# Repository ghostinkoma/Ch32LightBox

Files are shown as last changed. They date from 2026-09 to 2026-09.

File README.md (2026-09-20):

# LightBox — CH32V003 LED Dimmer Controller

**English** · [日本語](README_JP.md)

> **Status: ✅ Hardware Verified & Operational (as of 2026-09, no issues)** — All functions confirmed on both custom PCB (KiCad) and universal breadboard/perfboard. Verified nightlight, brightness control, soft start/off, 12-hour endurance test, and virtually zero heat generation with a ~1A LED.
> **Enclosed and currently in actual use inside a 3D-printed case designed in Fusion 360.**
>
> **License: Non-Commercial (CC BY-NC 4.0 compliant / Attribution required, modification allowed for non-commercial use, provided AS-IS without warranty)** → [LICENSE](LICENSE)

A single-channel PWM LED dimmer controlled via a rotary encoder.
Powered by the **CH32V003** microcontroller with a self-contained firmware based on [ch32fun](https://github.com/cnlohr/ch32fun).

To prioritize reproducing brightness as **perceived by the human eye**, the PWM duty cycle is generated using the **CIE 1931 L\* (lightness) curve**. One click produces a "perceptually equal" shift in brightness—slower changes at low levels and sharper changes at high levels—achieving a balanced response for human vision.

## Key Features

| Feature | Description |
|---|---|
| **CIE L\* Dimming** | Perceptually uniform brightness. 64 total steps, LUT generated at startup, runtime lookup via integer table. |
| **16-bit PWM** | TIM2, default 4095 steps / ~12 kHz. Adjustable resolution and frequency in `config.h`. |
| **Debouncing** | Full-step state machine (Ben Buxton) + direction reversal lockout (default 5 ms). No simple delays used. |
| **Fast-turn Snap** | Immediately sets duty to 100% or 0% if turned in the same direction $j$ times within $n$ ms. |
| **CW/CCW Support** | Swap rotation direction with a single line in `config.h`. |
| **Brightness Memory** | Flash wear leveling (dedicated 2 KB area, saved after 5 sec, ~1024x lifespan extension, saves ON/OFF state). |
| **Overheat Failsafe** (Default OFF) | Forcefully shuts off main PWM (MOSFET) when overheated → resumes when cooled down. Thermal throttles to $j$\% after $n$ cycles. **Die estimation disabled due to false triggers (`TEMP_PROTECT_ENABLE 0`)**; enable only when using an external NTC sensor. |
| **Watchdog** | IWDG. Automatically resets on system freeze for self-recovery. |
| **EMI Mitigation** | Configurable PWM slew rate (GPIO speed) + spread spectrum (period dithering, brightness invariant). |
| **Nightlight (WS2812 or single LED)** | When completely dark: ①WS2812/SK6812 breathes light↔dark on the CIE curve (RGB/RGBW, color order, max color), or ②a single-color LED blinks `x` ms every `n` s. |
| **Deep Low-Power (experimental)** | Optional battery mode (`LOW_POWER_MODE`): single-LED nightlight with the MCU in Standby between blinks (AWU periodic wake, push-switch EXTI wake). Default off; see CONFIG_REFERENCE. |
| **Soft Start** | Smoothly fades in/out to target brightness on power ON/OFF based on CIE curve (duration set in config, disabled if 0, max 65535 ms). |
| **Push Switch** | Short press toggles ON/OFF (time-based debouncing; smoothly tracks re-triggering during active fades). |

All configuration options are centralized in **`source/config.h`** (see [CONFIG_REFERENCE.md](documents/CONFIG_REFERENCE.md) for details).
Detailed specifications are in [SPEC.md](documents/SPEC.md), design decisions are in [DESIGN.md](documents/DESIGN.md), and battery / low-power and LED-driver notes are in [POWER_AND_DRIVER.md](documents/POWER_AND_DRIVER.md).

## Pinout (**All features fit on SOP8 / J4M6**)

| Pin | Signal | Function |
|---|---|---|
| PA1 | ENC_A | Encoder Phase A (Internal pull-up, Common=GND) |
| PC1 | ENC_B | Encoder Phase B (Internal pull-up, Common=GND) |
| PA2 | ENC_SW | Push Switch (Internal pull-up, Active Low) |
| PC2 | PWM | **Main LED Output** (default `PWM_PIN`=PC2 → TIM2_CH2 remap1) |
| PC4 | (Selectable) | **WS2812 Nightlight** / External Temp Sensor / Warning LED (Mutually exclusive, choose one) |
| PD1 | SWIO | Programming / debugprintf (Reserved) |

> **Feature ↔ pin assignment is done entirely in `config.h`** (one pin macro per feature: `PWM_PIN`, `ENC_*_PIN`, `WS_DIN_PIN`, `TEMP_SENSE_PIN`, `WARN_LED_PIN`). `source/pins.h` validates capabilities (PWM-/ADC-capable pins) and pin conflicts at compile time, and the LightBox Studio config editor mirrors the same checks. See the “Feature ↔ Pin Assignment” section of [CONFIG_REFERENCE.md](documents/CONFIG_REFERENCE.md).

> **Temperature protection is OFF by default** (die estimation rejected due to false shutdowns). Watchdog and EMI mitigations **require no external pins**, allowing PC4—the only remaining free pin on SOP8—to be used for the nightlight.
> If an external physical temperature sensor or warning LED is needed, allocate PC4 accordingly (mutually exclusive with the nightlight). To use more features simultaneously, switch to TSSOP20/QFN (F4P6) and assign individual pins in `config.h`.

## Connecting the LED

- **Recommended**: PC2 → MOSFET gate (e.g., AO3400 / 2N7002), driving the LED on the low side via the drain.
- **Simplified**: Low-current LEDs can be connected directly via `PC2 → [Resistor] → LED → GND` (Strictly respect $I_{\max} \approx 8\text{ mA}$ per pin).
- **Overheat Protection (Default OFF)**: The CH32V003 lacks an internal die temperature sensor. The initial duty-based "die temperature estimation" caused **false shutdowns (sudden turn-offs during continuous use)** because it was not a physical measurement. It has been **rejected (`TEMP_PROTECT_ENABLE 0`)**. If physical thermal protection is strictly required, attach a thermal-coupled NTC on the MOSFET to an ADC pin and run with `TEMP_PROTECT_ENABLE=1` + `TEMP_SOURCE=EXTERNAL`. See SPEC.md for details.

## Operation

- **Rotate Encoder**: $\pm 1$ step per click (perceptually equal spacing using CIE L*).
- **Fast Turn** (Default: 6+ clicks within 0.5s): Snaps to full brightness (100%) in the bright direction, or turns off (0%) in the dark direction.
- **Push Switch Short Press**: Toggles ON/OFF (retains last brightness level).
- **Auto Memory**: Defaults to 0 on first boot. Setting a brightness and leaving it untouched for 5 seconds automatically saves it to flash for next startup restoration.
- **Soft Start**: Fades in/out smoothly to target brightness on power ON/OFF or boot up (fade duration configured in config).
- **Nightlight**: Breathes automatically when turned completely dark (turns off when main LED turns on/brightens).

## Build & Flash

### ① ch32fun + Makefile (Verified Standard Build)

Dependencies: [ch32fun](https://github.com/cnlohr/ch32fun), RISC-V GCC (xpack riscv-none-elf recommended for `rv32ec libgcc`), WCH-LinkE.

```bash
cd source
make lightbox.bin CH32FUN=/path/to/ch32fun/ch32fun    # Build only
make             CH32FUN=/path/to/ch32fun/ch32fun    # Build -> Flash
```

Build memory footprints (Default config, all features ON, `DEBUG_LOG=0`): **Flash 8200 B / 16 KB (50%), RAM 184 B (9%)**.
Stripped footprint: Core only ~3 KB, + Nightlight ~3.6 KB. `DEBUG_LOG=1` adds ~1 KB.

> Set `DEBUG_LOG` to 1 only during development. `printf` is blocking and can stall if an SWD host is disconnected, causing dropped inputs in hot loops. Defaults to 0, which unlinks the printf infrastructure entirely.

### ② PlatformIO

See [PLATFORMIO.md](PLATFORMIO.md) (`platformio.ini` included).
*Note: The PlatformIO build has not been verified in this environment. The verified build method is the Makefile above.*

### ③ LightBox Studio (GUI — no VS Code required)

For a GUI-only workflow (`config.h` editing → compile → flash from a single menu), use the Java toolset in [tools/LightBoxStudio/](tools/LightBoxStudio/README.md). It downloads a self-contained toolchain on first run, so no command line or VS Code is required. See the [LightBox Studio README](tools/LightBoxStudio/README.md) for details.

## Directory Structure

```
LightBox/
├─ source/         Firmware source files
│  ├─ lightbox.c      Main application (main / encoder / PWM)
│  ├─ config.h        Centralized configuration (edit parameters here)
│  ├─ cie.h           CIE L* curve library (shared by main PWM & nightlight)
│  ├─ store.h         Non-volatile brightness storage (wear leveling)
│  ├─ temp.h          Temperature reading (external NTC, default OFF)
│  ├─ wdt.h           Watchdog timer (IWDG)
│  ├─ nightlight.h    WS2812/SK6812 nightlight driver
│  ├─ funconfig.h     ch32fun environment configuration
│  └─ Makefile
├─ documents/      SPEC.md / CONFIG_REFERENCE.md / HARDWARE.md / DESIGN.md / POWER_AND_DRIVER.md (+ *_JP.md)
├─ tools/          LightBoxStudio/ = GUI toolset (config edit → build → flash, no VS Code)
├─ ldscript/       Linker script for PlatformIO (lightbox_ch32v003.ld)
├─ PCB/            KiCad board files (LightBox/ = Schematic/PCB; AertWork.png; KiCad/ = FDS5680 lib)
├─ platformio.ini / PLATFORMIO.md
├─ 3D_Models/      Enclosure (Fusion 360 design / STL files, 3D printed)
└─ LICENSE         Non-commercial license (CC BY-NC 4.0 compliant)
```

## Enclosure

**Designed in Fusion 360 → 3D printed**. The board is assembled inside and **currently in operational use** (STL files available in `3D_Models/`).

## Hardware (PCB)

PCB layout, schematic, and artwork (with pin headers) completed → `PCB/LightBox/` (KiCad).
**Pin routing matches firmware exactly.** Details, BOM, and J1 pinout are in [HARDWARE.md](documents/HARDWARE.md).

- U1 CH32V003 (SOP8) / Q1 FDS5680 (N-MOSFET, low-side drive for main LED) / D1 SK6812 (OST45050C1A-W nightlight)
- R1 $100\ \Omega$ (Gate series resistor) / R2 $10\text{ k}\Omega$ (Gate pull-down = LED OFF during reset) / **D2 Pilot LED + R3 $100\ \Omega$ (series)**
- **Main (Power) LED is off-board** (Connected via LED OUT → J1). **Near-zero heat generation with ~1A LED** (heatsink added only as a precaution).
- J1 9-pin header: Breaks out Power / SWIO / Encoder / Signals for both LEDs. **Powered by $\text{VDD} = 5\text{ V}$**.
- Equivalent circuit constructed on a 1.27 mm pitch universal perfboard and verified working.

## Verification Status — ✅ Hardware Verified (Running Continuously)

- **★ Physical Board Operation Confirmed (2026-09-16 ~ present, running without issues)**: Board schematic/routing verified, flashing successful.
  - **Nightlight** (SK6812 / OST45050C1A-W, RGBW sequence)
  - **Brightness adjustment** (CIE L*, acceleration x3, fast-turn snap)
  - **ON/OFF soft start & soft off**
  - **12-hour ON / 12-hour OFF endurance test passed** (Disabling thermal protection eliminated false cutoffs, ensuring long-term stability)
- Build checks: Zero compiler warnings across all feature ON/OFF, RGBW, and half-step combinations (Makefile, ch32fun).
- Host simulation tests: CIE LUT, encoder state machine, flash wear store boundaries, nightlight curves, color ordering, acceleration, thermal model.
- Unverified: Long-term Flash wear (~10 million cycles by design), external NTC thermal protection (disabled by default), PlatformIO build environment.

## License

This project (original parts of firmware, PCB, enclosure, and documentation created by ghostinkoma) is licensed under a **Non-Commercial License (Creative Commons Attribution-NonCommercial 4.0 International / CC BY-NC 4.0 compliant)**. See [LICENSE](LICENSE) for full details.

- **Non-Commercial Use Only** (Contact the author for commercial licensing).
- **Attribution Required** (Must credit the original author **ghostinkoma** and "LightBox").
- **Modifications Allowed** (Free to adapt for non-commercial purposes; derivative works must inherit the same license conditions).
- **No Warranty / No Liability** (Provided "AS IS". The author accepts no responsibility for damages resulting from use).

*Note: Bundled/dependent third-party code (e.g., [ch32fun](https://github.com/cnlohr/ch32fun)) remains under its respective original licenses (MIT-x11 / NewBSD).*

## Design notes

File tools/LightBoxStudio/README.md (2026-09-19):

# LightBox Studio — CH32V003 One-Stop GUI (No VS Code Required)

**English** · [日本語](README_JP.md) · [← Project README](../../README.md)

A Java toolset for executing the workflow of `config.h` editing → compilation → flashing **from a single menu GUI**.
Its goal is to enable complete development of LightBox ([../../README.md](../../README.md)) using only a GUI, without requiring VS Code.

> **Status: ✅ Verified on real hardware (2026-09-18)**. On first-time setup, it automatically downloads the toolchain, deploys it to `toolchain/`, and fills in configuration settings automatically (self-contained, sandbox without scanning the PC).
> **config.h editing → compilation → CH32V003 flashing** was successfully executed on actual hardware using **only minichlink bundled in the downloaded ch32fun (inside dist, self-contained)** (`Detected CH32V003 → Image written`).
> Users do not need to search for installed paths. Detailed troubleshooting logs are recorded in [BUGFIX.md](BUGFIX.md).

## Architecture (5-Component Set)

| Executable | Role | Type |
|---|---|---|
| `LightBoxMenu.jar` | **Menu (Kicker)**. Launches other tools and aggregates logs | GUI |
| `setup.jar` | **Initial Setup**. Downloads/extracts toolchain and auto-fills settings (with progress bar) | GUI |
| `config-editor.jar` | Form-edits `config.h`, validates, and saves | GUI |
| `builder.jar` | Executes `make` to build (and optionally flash) | Background |
| `flasher.jar` | Flashes to CH32V003 using `minichlink` | Background |

The menu GUI and each background functional JAR operate as loosely coupled **separate processes**. Settings are shared via `settings.properties` (located in the same folder as the JARs).

## Requirements

- **JDK / JRE 11 or higher** (JDK for building, JRE sufficient for execution).
- Native toolchains (ch32fun / RISC-V GCC / make / minichlink) are **automatically prepared by [⬇ Initial Setup]**, so pre-installation is not required.
- Only for flashing, the **WinUSB driver for WCH-LinkE** (Zadig on first-time setup only) is required.
  * This is the only manual step that cannot be automated via Java (for distribution on other PCs).
  Instructions are built into the menu under **[🔌 Driver (Zadig)]** (refer to [ZADIG.md](ZADIG.md)).

> If you only edit `config.h`, **setup is not required** (operates in pure Java).

## Initial Setup (Self-Contained)

Pressing **[⬇ Initial Setup]** (`setup.jar`) in the menu **downloads & extracts** the following into `toolchain/` and automatically populates `settings.properties`. Progress is displayed via a progress bar.

| Component | Source | Approx. Size |
|---|---|---|
| RISC-V GCC (xpack riscv-none-elf) | xpack-dev-tools Releases | **~360MB** (takes time) |
| make (xpack windows-build-tools) | xpack-dev-tools Releases | ~2.7MB |
| ch32fun SDK | cnlohr/ch32fun (master zip) | A few MBs |
| minichlink | Automatically detects & copies existing binaries on PC due to lack of official prebuilts (internal process, no user action needed) | — |

- Download sources/versions can be replaced via `dist/toolchain.manifest.properties` (optional).
- Since `toolchain/` is large, it is ignored via `.gitignore` (not included in the repository).
- If minichlink is not found on the PC, the step is skipped; building and editing remain functional, but **flashing requires manually specifying minichlink**.

## Build

```bash
# Windows
build.bat
# Linux/macOS
./build.sh
```
Five JAR files will be generated in `dist/` (pre-generated JARs are also bundled in this repository).

## Usage

1. Launch the menu:
   - **Recommended: Double-click `LightBoxStudio.bat` (Windows) / `LightBoxStudio.sh` (Linux/macOS)**.
     The launcher automatically detects Java (① Bundled portable JRE → ② `JAVA_HOME` → ③ PATH) and starts.
   - Direct execution is also possible: `java -jar dist/LightBoxMenu.jar`
2. First-time only: Press **[⬇ Initial Setup]** to acquire the toolchain (wait until the progress bar completes).
   * If only editing config.h, this step is not needed. If a toolchain already exists, you can manually specify it in **[⚙ Settings]**.
3. **① Edit config.h** → **② Compile** → **③ Flash** (or **②+③ Build & Flash**).

### Java Runtime (When System Installation is Undesirable)

- The launcher **prioritizes detecting and reusing existing Java** (`JAVA_HOME`/PATH). If Java is already present, nothing extra is needed.
- If you **do not wish to install Java onto the system**, select **"☐ Also acquire portable JRE"** during initial setup. This extracts Adoptium Temurin 17 JRE (~44MB, no installer required) **only into `dist/runtime/`**.
- **System PATH, registry, and admin privileges remain untouched** — deleting the folder returns the system to its original state (**sandbox**). Subsequent launcher runs will automatically use this `runtime/`.
- Distributing to a PC without Java: **Run "Also acquire portable JRE" on a PC with Java → Copy the folder whole**. The target PC can run the launcher without installing Java (including `dist/toolchain/` allows self-contained building and flashing as well).

## Settings (settings.properties)

| Key | Meaning |
|---|---|
| `project.dir` | The `source/` folder containing `config.h` / `Makefile` (empty = auto-detect) |
| `ch32fun.dir` | The folder containing `ch32fun.mk` |
| `make.path` | `make` executable path (empty = PATH) |
| `gcc.bin.dir` | `bin` directory containing `riscv-none-elf-gcc` (empty = PATH) |
| `minichlink.path` | `minichlink` executable path (empty = PATH) |
| `flash.artifact` | Target file to flash (default `lightbox.bin`, relative paths based on `project.dir`) |

## Features of config.h Editor

- **Schema-Driven**: Form-edit all 64 settings with type-specific widgets (numeric / checkbox / dropdown / pin / color).
  Definitions correspond to [`documents/CONFIG_REFERENCE.md`](../../documents/CONFIG_REFERENCE.md) and `source/config.h`.
- **Feature ↔ Pin Assignment**: Per-feature pin dropdowns are filtered by hardware capability — `PWM_PIN` lists only PWM-capable pins, `TEMP_SENSE_PIN` only ADC-capable pins. Pin conflicts (two features on one pin), capability violations, and SWIO(PD1) use are flagged before save, mirroring the firmware `source/pins.h` compile-time checks.
- **Nightlight type & deep low-power**: choose ①WS2812 or ②single-color LED; validation enforces that deep low-power (`LOW_POWER_MODE`) is used only with single-LED + no-PWM + `NL_PERIOD_S≤30` + `WDT_ENABLE=0`. A **live CR2032 battery-life estimate** (1 kΩ assumption) is shown for the single-LED nightlight to guide config.
- **Non-Destructive Editing**: Replaces **only value tokens** in `#define KEY VALUE`, preserving comments, enum definitions, empty lines, `u`/`L` suffixes, and `(-300)` formatting (without regenerating full text). Creates `config.h.bak` before saving.
- **Cross-Constraint Validation** (Pre-save validation):
  - When `PWM_SPREAD_SPECTRUM=1`: `PWM_TOP+PWM_SPREAD_RANGE≤65535` and `RANGE<PWM_TOP`
  - `STORE_SIZE_BYTES` must be a multiple of 1KB / `LEVEL_INIT≤LEVELS`
  - `WARN_TEMP_HYST_C<WARN_TEMP_C` / `THERMAL_THROTTLE_MAX<100` / `TEMP_CAL_SLOPE_X100≠0`
  - **PC4 Mutual Exclusion** (Nightlight / External temp sensor / Warning LED cannot share PC4 simultaneously)
  - Links digit counts of `WS_MAX_COLOR` with `WS_ORDER` (RGB = 6 digits / RGBW = 8 digits)
  - Warnings: `DEBUG_LOG=1` (must be 0 for normal operation), Die estimation temperature source (risk of false cutoffs)
- **Advanced Mode**: Fixed hardware wiring items like `ENC_*_PIN` are locked by default to prevent accidental modifications.

## Flashing Notes (Compliant with README / CONFIG_REFERENCE.md)

- SWD printf monitoring (`minichlink -T`) is **mutually exclusive with flashing**. Close monitoring before flashing.
- If no flash artifact exists, run **② Compile** first to generate `lightbox.bin`.
- WCH-LinkE not recognized → Verify WinUSB driver (Zadig), power supply, and SWIO (PD1) wiring.
- **If flashing hangs**: Use **[■ Abort]** in the menu to stop execution (kills child minichlink processes as well).
- **minichlink compatibility varies by build**: When multiple versions exist on a PC, some builds initialize successfully but hang during flashing. As a countermeasure, flashing **tries multiple minichlink candidates sequentially**, with each attempt **timing out after ~25 seconds** before falling back automatically (ensuring execution using a working binary even if a hanging binary is selected initially). Initial setup automatically records candidates in `minichlink.candidates`.
- **For guaranteed reliability**: Specify a proven `minichlink.exe` via **[🔧 Select Flashing Tool]** in the menu (runs with highest priority). This setting persists across setup re-runs.
- **Once successfully flashed, minichlink is recorded in user profile (`~/.lightboxstudio/`)**, and will be **automatically prioritized on subsequent runs** even if the `tools/` folder is deleted and cleanly reinstalled.
  * "Once a working minichlink is configured, it works automatically from then on."
- Candidate evaluation order: ① Local settings → ② Historical successful runs → ③ Auto-detected candidates. If a record exists, unnecessary waiting is avoided.
- Re-running setup skips downloading large files if `toolchain/` is already extracted.

### minichlink Compatibility and Self-Containment (Investigation Results)

- **Source builds are not required**. ch32fun bundles Windows `minichlink.exe` and `libusb-1.0.dll` in its repository (prebuilts built with tcc committed). Extracting ch32fun during initial setup yields `toolchain/ch32fun-master/minichlink/minichlink.exe`.
  → **Flashing automatically tests this minichlink as a self-contained candidate** (no PC-wide search required).
- **However, compatibility exists between minichlink builds and WCH-LinkE drivers/firmware** (Verified on hardware):
  - `Could not initialize` … WinUSB driver not assigned. Assign WCH-Link to WinUSB via **Zadig** (one-time setup).
  - Hangs after `Found WCH Link` … Compatibility issue between minichlink build and LinkE firmware (e.g., firmware 2.17 succeeds with older `bc15212` series but hangs with newer series). **Once a working version is used, it is remembered automatically**.
- Fallback sequence (**No full PC scanning = Sandbox**): ① Local settings → ② Historical successes (`~/.lightboxstudio/`) → ③ **Bundled with ch32fun (inside dist, self-contained)**. Each times out after 25s.
  **Successful versions are recorded permanently** (retained across clean reinstalls).
- If the bundled version fails in your environment: Explicitly specify a working `minichlink.exe` via [🔧 Select Flashing Tool] (default path points to the bundled location in ch32fun). Explicitly set paths gain highest priority and permanent memory.
- If flashing still fails, update WCH-LinkE firmware (using WCH-LinkUtility) to match driver versions.

> Key takeaway: Simply point to or assign a working minichlink **once**, and the process becomes fully automatic afterward. Even for CH32 beginners, the target is to complete flashing using ch32fun-bundled minichlink + Zadig (one-time initial driver setup).

## Roadmap

- **Phase 0 (Completed)**: GUI implementation assuming pre-existing environment. `config-editor` completed as a standalone tool.
- **Phase 1 (Completed / Current)**: `setup.jar` automatically downloads xpack GCC / make / ch32fun into `toolchain/`, auto-detects/copies existing minichlink, and populates configuration settings (self-contained, with progress bar).
- **Phase 2 (In Progress)**: **Portable JRE (sandbox) + Launcher** for complete self-contained Java dependency management.
  Existing Java installations are auto-detected and reused; if missing/unwanted, extracted solely to `dist/runtime/` (no system modifications).
  Remaining: Single `.exe` creation via `jpackage`, integrated WinUSB driver installation (Zadig) guide.

## License

This toolset follows the same non-commercial license (CC BY-NC 4.0 compliant) as LightBox itself ([../../LICENSE](../../LICENSE)).

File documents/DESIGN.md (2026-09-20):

# LightBox Design Notes

**English** · [日本語](DESIGN_JP.md) · [← README](../README.md)

CH32V003 LED Dimmer. Documenting design decisions and rationale to ensure third-party reproducibility.
Battery / low-power and LED-driver decisions are recorded separately in [POWER_AND_DRIVER.md](POWER_AND_DRIVER.md).

## Requirements
- Input: Locally connected rotary encoder
- Output: Single PWM (1ch LED)
- MCU: CH32V003
- Uses a 16-bit timer
- **Perceptual Brightness Priority**: Recreates human visual perception as top priority → adopts CIE 1931 L*
- Snap shortcut: Sets duty to 100% or 0% immediately if clicked $j+$ times in the same direction within $n\text{ ms}$ ($n, j$ configured via config)
- Encoder Direction: Supports both CW/CCW encoder types (configurable)
- Non-Volatile Brightness Memory: Stores brightness level upon power cycle with wear-leveling (initial 0, saves after 5 seconds)
- Over-temperature Fail-Safe: Thermal protection light (fail-safe with configurable thresholds)
- WS2812/SK6812 Night Light: "Breathing" illumination based on CIE standard when dark (configurable color, byte order, period)
- All settings consolidated in **config.h**

## Pin Assignment Rationale
Designed for the smallest package, **SOP8 (J4M6)**. Available GPIO pins are 5 in total: PA1, PA2, PC1, PC2, PC4 (excluding VDD/VSS, and preserving PD1 for SWIO debugging/flashing).

- PWM Output: **TIM2_CH2 (remap1) = PC2**. Tested and proven in the sister project FanConCH32V003, presenting the lowest risk.
- Encoder Inputs: A=PA1, B=PC1, SW=PA2 assigned from remaining pins, all configured as internal pull-ups.
- Reserve Pin: PC4 reserved (for a future 2nd channel or status LED).

Since larger packages maintain pin compatibility with this layout, SOP8 serves as the baseline design.

## Encoder Decoding and Debouncing
Mechanical rotary encoders inherently suffer from contact bounce. **Simple delay-based debouncing was rejected** as it blocks the main execution loop, worsening dropped events and failing to suppress bounce occurring during the delay itself. Instead, a **State Machine + Time Lockout** architecture is implemented.

### Evaluated Debounce Strategies
| # | Strategy | Effect | Adoption |
|---|---|---|---|
| 1 | Reject invalid transitions (2-bit simultaneous change) | Suppresses glitch noise | Embedded in State Machine |
| 2 | **Full-Step State Machine (Ben Buxton Method)** | Triggers 1 step only upon completing a valid path between detents. Intermediate bounce bounces back/forth without firing, ignoring single-phase chatter. | **Adopted (Core)** |
| 3 | **Direction Reversal Lockout (Default 5ms)** | Ignores reverse steps occurring within an extremely short time window as physical impossibilities (bounce). Same-direction steps are unrestricted. | **Adopted** |
| 4 | Fixed Period Sampling (e.g., 1ms) | Hides fast bounce between samples | Rejected: Coarse sampling drops fast turns. #2 + #3 suffice without loss. |
| 5 | Majority Voting / Integration per Phase | Phase-independent debouncing | Rejected: Redundant with #2. |
| 6 | Inter-step Refractory Period | General step throttling | Reduced into #3 (reversal only). Global throttling hampers fast spins. |
| 7 | Simple `delay()` | - | **Rejected** (Degrades responsiveness, drops steps, fails to resolve bounce). |
| 8 | Pushbutton Time-Based Integration Debounce | Replaces loop-count-dependent counters | **Adopted** |

### (2) Full-Step State Machine
Column index = Current 2-phase state `(A<<1)|B` (idle = `0b11`). States start at START and must traverse BEGIN $\rightarrow$ NEXT $\rightarrow$ FINAL in the **correct order** for either CW or CCW to emit `DIR_CW` or `DIR_CCW`. Phase bounce simply oscillates between BEGIN $\leftrightarrow$ START without triggering invalid steps. Half-step lookup tables are also available via `ENC_HALF_STEP` (unused tables excluded via `#if`).
- Host Verification: Clean CW×3 $\rightarrow$ [1,1,1] / CCW×3 $\rightarrow$ [-1,-1,-1]. Single detent with injected bounce $\rightarrow$ [1]. Immediate reverse chatter following CW $\rightarrow$ [1] (zero false reversals).

### (3) Direction Reversal Lockout
Implements a strict threshold where opposite directional steps within 5ms are discarded. Even if state transitions near mechanical thresholds produce a reverse step, if it occurs in the opposite direction of the last **confirmed** step within `ENC_REVERSAL_LOCK_MS` (default 5ms), it is dropped as contact bounce. Manual reverse turning takes tens of ms; thus, reversals under 5ms are guaranteed chatter. **Same-direction steps are unrestricted**, maintaining responsiveness for rapid spins. Timing uses SysTick (unsigned subtraction, overflow-safe).

### (8) Pushbutton Debounce
When raw state changes, candidate value and timestamp update. Once the value remains stable for `SW_DEBOUNCE_MS` (default 20ms), state updates. Validated press (falling edge) toggles state. Replaces inaccurate loop-counter methods.

Polling Choice: Manual encoder rotation achieves at most a few ms per quarter-step. Polling in the main loop captures all events without missing, avoids interrupt complexity, and preserves SOP8 EXTI resources.

## Dimming Curve — CIE 1931 L* (Perceptual Brightness Priority)
The primary design goal is **matching human brightness perception**. Human visual perception follows a **power law (~cubic root, Stevens's Law)** rather than a pure logarithmic response, featuring high sensitivity at low light levels and lower sensitivity at high light levels. **CIE 1931 L\*** is used as the standardized perceptually uniform scale. Logarithmic/exponential tapers approximate this curve but suffer from accuracy loss at lower brightness levels.

Level index $i$ is mapped linearly to lightness $L^*$ (0..100) (meaning 1 click = equal perceived step change), and mapped back to relative luminance $Y$ and duty cycle:

$$\text{For } L^* \le 8: Y = \frac{L^*}{903.3} \quad (\text{linear toe near complete darkness})$$

$$\text{For } L^* > 8: Y = \left(\frac{L^* + 16}{116}\right)^3 \quad (\text{power law})$$

$$\text{Duty} = \text{PWM\_TOP} \times Y$$

- **Integer-Only Math**: CH32V003 lacks an FPU. $L^*$ is represented in units of $1/100$, and the cubic term is calculated during initialization using 64-bit unsigned integers (`uint64_t`): $\text{PWM\_TOP} \times (L^* + 16)_{x100}^3 / (11600)^3$. Maximum value $65535 \times 11600^3 < 2^{63}$, preventing overflow without `libm` or `float` dependencies.
- Linear Toe ($L^* \le 8$): Handles low-light conditions, avoiding the extreme dim-crushing associated with pure logarithmic functions.
- Lookup Table (LUT): Computed once at boot. Main execution relies purely on `uint16_t` array indexing. Host verified: 0 $\rightarrow$ PWM_TOP boundaries, strictly monotonic, no duplicate steps, uniform low-end resolution (`duty = 0, 7, 14, 21, 28, ...`).
- The curve is **fixed and parameterless** (as CIE $L^*$ defines standardized human vision). Gamut adjusters can be added upstream if custom scaling is needed in the future.

## PWM Resolution and Frequency (16-bit Timer)
- TIM2 is a **16-bit counter**. `PWM_TOP` supports values up to 65535 and is configurable via `config.h`.
- Default: `PWM_TOP = 4095` (12-bit resolution), `PSC = 0` $\rightarrow 48\text{MHz} / 4096 \approx \mathbf{11.7\text{kHz}}$. Operates outside audible range without visible flicker. Preserves fine step resolution at low duty cycles (e.g., duty = a few counts), whereas 8-bit resolution (256 steps) leads to rounding collisions at the low end. Resolution can be increased to 8191 or 16383 for smoother dimming.

## High-Speed Rotation Snap (Duty 100% / 0% Shortcut)
Rapidly setting maximum or minimum brightness is achieved through fast rotation gestures.

- Circular buffer tracks timestamps of recent `SNAP_CLICKS` clicks in the same direction.
- On a new click, if elapsed time `now - oldest` across $j$ clicks is within `SNAP_WINDOW_MS` ($n\text{ ms}$), shortcut triggers: sets `level = LEVELS` (100%) for clockwise/brightening, or `level = 0` (0%) for counter-clockwise/dimming.
- Driven by SysTick (`SysTick->CNT` / `Ticks_from_Ms`). Unsigned subtraction avoids wrap-around issues ($0.5\text{s window} \ll 32\text{-bit wrap period} \approx 715\text{s}$).
- Clears click history post-trigger to prevent repeated snapping. Configurable via `SNAP_WINDOW_MS` and `SNAP_CLICKS`.

## Dual CW/CCW Encoder Support
Variations in encoder hardware or wiring order can invert rotation direction. Invert signal decoding digitally via `ENC_REVERSE` (0 or 1 in `config.h`) without modifying hardware wiring (flips decoded `dir` sign, applying consistently across dimming and snap gestures).

## LED Drive Circuitry
- Recommended: **Low-side MOSFET switch** (e.g., 2N7002, AO3400). Avoids MCU GPIO drive limits ($I_{max} \approx 8\text{mA}$), enabling drive of high-power LEDs, series strings, or constant-current drivers.
- Small signal LEDs may connect directly to PC2 via current-limiting resistor within rating boundaries.

## Soft Power Toggle and Operating Options
Short press on encoder switch toggles output state (ON/OFF). Preserves active dimming level during OFF state, restoring prior brightness upon turning back ON.

- **`WAKE_ON_TURN` (Default: 1)**: Turning encoder while OFF automatically restores output. Prevents hidden level adjustments while output remains dark.
- **`DEBUG_LOG` (Default: 0)**: Restricts UART/SWD `printf` to development mode.

## Hot-Loop I/O Optimization (`DEBUG_LOG`)
Enabling `printf` calls within event loops introduces blocking behavior: (a) If SWD host is disconnected, buffer saturation halts CPU execution; (b) Each call incurs hundreds of microseconds to milliseconds, missing intermediate encoder transitions and dropping detents. Setting `DEBUG_LOG = 0` compiles out logging mechanics entirely, running polling loops at maximum rate. Reduces flash consumption from 4380 B to 2968 B.

## Non-Volatile Brightness Storage (Wear-Leveling)
Restores last selected brightness level across power cycles. To accommodate flash write/erase limits, the driver appends updates sequentially to erased space rather than overwriting fixed addresses, performing sector erasures only when full.

### Flash Physics (CH32V003 Standard Mode)
- Bit transitions are limited to **$1 \rightarrow 0$**. Resetting $0 \rightarrow 1$ requires sector erase.
- **Erase Block = 1KB** (`PER`). **Write Unit = 2 Bytes** (`PG`, half-word).
- Erased State = `0xFFFF`.

### Appending Single-Cell Log (Last-Written-Wins)
- Reserves the final `STORE_SIZE_BYTES` (2KB) as a dedicated **1KB-aligned `const` array** (initialized to `0xFFFF`). Being 1KB-aligned and a multiple of 1KB, this memory occupies dedicated sectors without interfering with code or constants (verified: `g_store @ 0x1400`, occupying sectors 5–6 while application code remains separated below `0x1400`).
- **Save Operation**: Appends 2-byte entry to the first available `0xFFFF` cell. **1 save = 1 write**.
- **Read Operation**: Reads cell immediately preceding first empty (`0xFFFF`) slot. Defaults to 0 on uninitialized storage.
- **Full Storage**: Erases reserved 2KB sectors and wraps execution to start.
- Levels (0..64) do not collide with `0xFFFF`, allowing raw values to reside in single cells.
- Flash controller operations translate array references into physical memory offsets based on $0x08000000$.

### Commit Delay Optimization
Defers flash writes until level remains unchanged for `STORE_COMMIT_MS` (5 seconds), grouping adjustments into a single flash commit.

### Flash Lifespan Estimation
- $2\text{KB} / 2\text{ Bytes} = \mathbf{1024\text{ records}}$. Sector erase occurs once every 1024 updates, reducing erase cycles to **~1/1024th** and extending flash endurance by ~1024x.
- Example: For flash erase endurance $E$, naive storage permits $E$ saves; this implementation permits $\approx 1024 \times E$ saves. Assuming $E = 10,000$, total write cycles reach **~10,000,000 saves**.
- Host Verification: Verified initial boot state 0, save/restore integrity, 1024-cell wraparound erase, and edge case handling.

### Alternative Storage Approaches
An alternative 2-cell structure using marker markers (`0x0000` + value) updates former markers to invalid state upon writing. The single-cell log structure simplifies this to a single write per save (reducing write ops to 1/3) while doubling capacity to 1024 records per 2KB.

### Power Interruption Behavior
Power loss during sector erase (~6ms per 1024 saves) may reset unsaved level changes to default (acceptable for non-critical lighting levels).

## Thermal Fail-Safe (Hardware Considerations)
CH32V003 lacks an internal junction temperature sensor (ADC ch8 = Vrefint, ch9 = Vcalint). Thermal monitoring utilizes external NTC thermistors thermally coupled to output MOSFETs via ADC channels.

- Utilizes `funAnalogInit()` / `funAnalogRead(ch)` with ADCCLK divided to HCLK/8 (6MHz) for stability ($\le 14\text{MHz}$).
- First-order linear approximation computes operational thermal thresholds, driving alert GPIO outputs with hysteresis.
- Optional safety feature: Clamps main PWM output to 0 during over-temperature events (`WARN_TEMP_CUT_OUTPUT`).

## WS2812/SK6812 Night Light Integration
When main lighting is inactive (`!g_on || level == 0`), the MCU drives a low-power background night light using a triangular breathing cycle scaled by CIE $L^*$ curve, followed by an off interval. Color, channel order, and RGBW parameters are fully configurable.

- Depends on `ws2812b_simple.h` (ch32fun), requiring **SysTick = HCLK (48MHz)** via `FUNCONF_SYSTICK_USE_HCLK 1` in `funconfig.h`. Timing references scale automatically via `Ticks_from_Ms`.
- Color byte ordering (GRB/RGB/GRBW/RGBW) rearranges packed output bytes during transmission. RGBW modes apply CIE scaling to W channel concurrently.

## Verification & Test Summary
- Resource Utilization: Flash: 8200 B / 16KB (50%), RAM: 184 B (9%) with all features enabled. Core implementation occupies ~3KB (Night light: +3.6KB, `DEBUG_LOG=1`: +1KB). Clean compilation across all feature combinations.
- Math & Logic Verification: Monotonicity and boundary checks confirmed via host testing. State machine and storage log logic verified under simulated chatter and wraparound conditions.
- **Hardware Verified (In Operation since 2026-09-16 on LightBox Custom PCB)**: Operational test covering SK6812 RGBW night light, rotary acceleration (3x), soft start/off, and continuous 12-hour ON/OFF cycles. Junction temperature estimation disabled (`TEMP_PROTECT_ENABLE 0`) to prevent false tripping.
- Hardware specifications and pinout details available in `documents/HARDWARE.md`.

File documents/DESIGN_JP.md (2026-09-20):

# LightBox 設計メモ

[English](DESIGN.md) · **日本語** · [← README](../README_JP.md)

CH32V003 による LED 調光器。設計上の判断とその根拠を残す（第三者が再現できるように）。
電池/低電力・LEDドライバの判断は [POWER_AND_DRIVER_JP.md](POWER_AND_DRIVER_JP.md) に別記。

## 要求
- 入力: ローカル接続のロータリーエンコーダ
- 出力: シングル PWM（LED 1ch）
- MCU: CH32V003
- 16bit タイマを使用
- **人間の目が感じる明るさ（知覚感度）を最優先で再現** → CIE 1931 L* を採用
- n ms 以内に同方向 j 回以上のクリックで duty=100%/0% に即セット（config で n,j）
- エンコーダの CW/CCW 2 タイプに両対応（config で切替）
- 電源再投入後に明るさを記憶（フラッシュ寿命を延ばすウェアレベリング／初回0／5秒後保存）
- 温度警告灯（フェイルセーフ, config で閾値）
- WS2812/SK6812 常夜灯（暗い時に CIE 基準で呼吸, config で色/色順/周期）
- 上記の設定値は **config.h** に集約

## ピン割当の根拠
最小パッケージ **SOP8 (J4M6)** で成立させる。使えるのは PA1/PA2/PC1/PC2/PC4 の 5 本
（PD1 は SWIO=書込/printf のため温存、VDD/VSS を除く）。

- PWM 出力は **TIM2_CH2 (remap1) = PC2** を採用。姉妹プロジェクト FanConCH32V003 で
  実機実証済みの経路で、リスクが最も低い。
- 残りからエンコーダ A=PA1 / B=PC1 / SW=PA2 を割当。全て内部プルアップ入力。
- PC4 は予備（将来の 2ch 目やステータスLEDに）。

より大きなパッケージでも同じ割当がそのまま使えるため、SOP8 基準で設計。

## エンコーダのデコードとチャタリング吸収
機械式エンコーダの接点は開閉時に必ずバウンス（チャタ）する。**単純 delay で固める方式は
却下**（ループを止めて他処理/取りこぼしが悪化、かつ delay 中のバウンスは吸収できない）。
代わりに「**状態機械 + 時間ロックアウト**」で構造的に吸収する。

### 検討した処置（列挙）と採否
| # | 処置 | 効果 | 採否 |
|---|---|---|---|
| 1 | 遷移テーブルで無効遷移(2bit同時変化)棄却 | ノイズ的グリッチ除去 | 状態機械に内包 |
| 2 | **フルステップ状態機械 (Ben Buxton方式)** | ディテント間の"正しい遷移経路"を完走時のみ1発火。途中バウンスは中間↔静止を往復するだけで発火せず、単相バウンスを構造的に無視 | **採用(主軸)** |
| 3 | **方向反転ロックアウト (既定5ms)** | 直前と逆方向のステップが極短時間に来たら物理的にあり得ない=バウンスとして破棄。同方向は制限せず高速回転を妨げない | **採用** |
| 4 | 定周期サンプリング(例1ms) | サンプル間の高速バウンスを不可視化 | 不採用: 粗いと高速回転でステップ取りこぼし。#2+#3で取りこぼし無く十分 |
| 5 | 各相の多数決積分(N回一致) | 相ごと独立デバウンス | 不採用: #2と役割重複 |
| 6 | ステップ間リフラクトリ(最小間隔) | 一般形 | #3(反転限定)に縮小採用。全方向に効かせると高速回転を殺す |
| 7 | 単純 delay | ─ | **却下**（応答性/取りこぼし悪化・そもそも吸収にならない） |
| 8 | 押しSWの時間ベース積分デバウンス | ループ回数依存の粗いカウンタ廃止 | **採用** |

### (2) フルステップ状態機械
列 index = 現在の2相 `(A<<1)|B`（静止=0b11）。状態は START から始まり、CW 側/CCW 側それぞれ
BEGIN→NEXT→FINAL の経路を**正しい順で完走**した時だけ `DIR_CW`/`DIR_CCW` を1回出す。
バウンスで途中の相が戻っても状態が BEGIN↔START を往復するだけで発火しない。
ハーフステップ品用の表も用意し `ENC_HALF_STEP` で選択（未使用側は `#if` で不コンパイル）。
- ホスト検証: クリーン CW×3→[1,1,1] / CCW×3→[-1,-1,-1]、各遷移にバウンス挿入した1ディテント→[1]
  のみ、CW直後の逆方向ジッタ→[1]のみ（誤反転ゼロ）を確認。

### (3) 方向反転ロックアウト（ユーザ要求の中核）
「5ms 以内に順逆が出現しない」を直接実装。状態機械が万一境界で反転を出しても、直前に**確定した**
ステップと逆方向で、経過が `ENC_REVERSAL_LOCK_MS`(既定5ms) 未満なら破棄する。人が実際にディテントを
逆回しするには数十 ms 以上かかるため、5ms 以内の反転は確実にバウンス。**同方向は無制限**なので
勢いよく回す（スナップ）操作は妨げない。時間は SysTick 実時間（符号なし減算でラップ安全）。

### (8) 押しSW デバウンス（時間ベース積分）
生読みが変化したら候補+時刻を更新し、同じ値が `SW_DEBOUNCE_MS`(既定20ms) 継続したら確定。
確定した押下(立下り)で ON/OFF トグル。ループ回数依存の旧カウンタ方式を廃した。

ポーリングにした理由: エンコーダは手回しで速くても quarter 数 ms 程度。メインループのポーリングで
取りこぼさず、割込みより単純・バグりにくく、SOP8 の EXTI 資源も温存できる。

## 調光カーブ — CIE 1931 L*（人間の知覚を最優先で再現）
最優先要求は「**人間の目が感じる明るさの再現**」。人間の明度知覚は輝度に対し純対数ではなく
**べき乗則（≒立方根, Stevens）**で、暗部は緩やか・明部は急峻。これを標準化した知覚均等スケールが
**CIE 1931 L\***。log/指数テーパでも「暗ゆっくり・明急峻」の形は出るが、特に暗部の感度が実際の
知覚とずれる。忠実再現を最優先するので L* を採用した。

段 i を明度 L*(0..100) に**等間隔**に割り当て（＝1クリック=知覚的に等量の変化）、
L* → 相対輝度 Y → duty に逆算する:

```
L* <= 8 : Y = L* / 903.3            (真っ暗付近の直線トウ)
L* >  8 : Y = ((L* + 16) / 116)^3   (べき乗則)
duty = PWM_TOP * Y
```

- **整数演算のみ**（CH32V003 は FPU 無し）。L* を 1/100 単位で持ち、立方項だけ起動時に
  `uint64` で計算（`PWM_TOP * (L*+16)_x100 ^3 / (11600)^3`）。最大 65535×11600³ < 2^63 で収まる。
  → **libm/float 完全不使用**（float 版よりコードも小さい）。
- 直線トウ（L*<=8）が真っ暗付近を担い、log の「暗部を潰しすぎる」問題を避ける。
- LUT は起動時に 1 回だけ生成。ループ中は `uint16` テーブル参照のみ。
  検算: 端点 0→PWM_TOP、単調増加、重複段ゼロ、低輝度側が知覚的に均等（duty=0,7,14,21,28,…）
  をホストで確認済み。
- 曲線は**固定・パラメータ無し**（L* は知覚均等になるよう定義された曲線そのもの）。
  もし後日「もっと暗部を伸ばす／浅くする」等が要れば、L*→duty の前段にガンマ係数を1つ足すだけで
  調整できる（現状は忠実再現を優先し素の L*）。

## PWM の分解能・周波数（16bit タイマ）
- TIM2 は **16bit カウンタ**。`PWM_TOP` は最大 65535 まで設定でき、`config.h` で可変。
- 既定 `PWM_TOP=4095(12bit), PSC=0` → 48MHz/4096 ≒ **11.7kHz**。可聴域外・目視フリッカ無し、
  かつ対数テーパの低輝度側（duty=数カウント）でも段が潰れず分離する
  （8bit=256 だと最下段が同一 duty に丸まってしまう）。さらに滑らかにしたいなら 8191/16383 へ。

## 高速回しスナップ（duty 100%/0% ショートカット）
「一気に最大／最小にしたい」を、勢いよく回すジェスチャで実現する。

- 同方向クリックの時刻を直近 `SNAP_CLICKS` 個だけリングバッファに保持。
- 新クリックで、その j 個の所要時間 `now - 最古` が `SNAP_WINDOW_MS`(=n ms) 以内なら発火し、
  明るい方向なら `level=LEVELS`(=100%)、暗い方向なら `level=0`(=0%) に即セット。
- 時間基準は SysTick（`SysTick->CNT` / `Ticks_from_Ms`）。符号なし減算でラップ安全
  （窓 0.5s ≪ 32bit ラップ周期 ~715s）。
- 発火後はカウンタをリセットして連続スナップを抑止。`SNAP_WINDOW_MS`/`SNAP_CLICKS` は config。

## エンコーダ CW/CCW 両対応
品種・配線で A/B の位相関係が逆になり、回す向きと増減が反転することがある。
配線し直さず `ENC_REVERSE`(config, 0/1) でデコード方向を反転して吸収する
（デコード後の方向 `dir` を符号反転するだけ。スナップ方向にも一貫して効く）。

## LED 駆動
- 推奨は **MOSFET ローサイドスイッチ**（2N7002 / AO3400 等）。CH32V003 のピン電流
  （Imax ≈ 8mA）に縛られず、明るい LED / 複数直列 / 定電流ドライバも駆動できる。
- 小信号 LED なら PC2 直結（直列抵抗経由）も可だが電流厳守。

## ソフト ON/OFF（押しSW）と動作オプション
押しSW 短押しで出力を ON/OFF トグル。OFF 中もレベルは保持し、再 ON で元の明るさへ。
デバウンスは時間ベース積分（上記(8)）。

- **WAKE_ON_TURN(既定1)**: OFF 中にエンコーダを回すと自動点灯。これが無いと OFF 中の回転は
  隠れた level だけ動いて LED が暗いまま＝無反応に見えるため、既定で有効にした。
- **DEBUG_LOG(既定0)**: printf は開発時専用。理由は下記「ログI/Oをホットループから排除」。

## ログ I/O をホットループから排除（DEBUG_LOG）
再検討で見つかった弱点: 旧実装は毎ディテントで printf していた。ch32fun の debugprintf は
**ブロッキング**で、(a) SWD ホスト未接続だと出力バッファが埋まり処理が停滞、(b) 接続時でも1回が
数百µs〜数ms かかり、その間にエンコーダの A/B 遷移が進むと **quarter を取りこぼして detent を落とす**
（＝高速回転が必要なスナップ機能を自ら阻害）。対策として全ログを `DEBUG_LOG` でコンパイル時ゲートし、
既定 0 では printf 機構ごとリンクしない → ホットループは I/O ブロック無しの最速ポーリング。
Flash も 4380→2968B に減。

## 明るさの不揮発記憶（ウェアレベリング）
電源再投入後に最後の明るさを復元する。フラッシュには**消去回数寿命**があるため、
「同じ番地を毎回 消去→書込」ではなく、消去済み領域へ**追記**し満杯時だけ消去する（循環）。

### フラッシュ物理則（CH32V003 標準モード）
- ビットは **1→0 のみ**書込可。0→1 に戻すには消去が必要。
- **消去単位 = 1KB**（`PER`）。**書込単位 = 2バイト**（`PG`, ハーフワード）。
- 消去済み = 0xFFFF。

### 採用方式：単一セル追記ログ（last-written-wins）
- 末尾 `STORE_SIZE_BYTES`(=2KB) を専用領域として **1KB整列の const 配列**で予約
  （初期値 0xFFFF）。1KB整列かつサイズ=1KBの倍数なので、この領域は**専用セクタ群を
  丸ごと占有**し、消去がコード/定数へ波及しない（実ビルドで g_store@0x1400、
  専用セクタ5–6を占有・コードは〜0x1400 で分離、を確認）。
- **保存** = 先頭から最初の空(0xFFFF)セルへ 2バイト書込（追記）。**1保存=1書込**。
- **現在値** = 先頭から見て最初の空セルの「手前」= 最後に書いた値。空なら 0（初回）。
- **満杯** = 2 セクタ消去して先頭から再利用（循環）。
- レベルは 0..64 で 0xFFFF と衝突しないため、値そのものを 1 セルに格納できる。
- フラッシュコントローラは 0x08000000 ベースの物理アドレスを要求するので、g_store の
  オフセットを 0x08000000 に載せ替えて読み書きする（ch32fun flashtest に倣う）。

### 保存タイミング（書込回数の最小化）
`STORE_COMMIT_MS`(=5秒) の間 明るさが変化しなくなってから **1回だけ**書く。回すたびには
書かない → 調整1セッション=1書込。実際の物理書込を激減させる。

### 寿命の見積り
- 2KB / 2バイト = **1024 レコード**。消去は 1024 保存に 1 回だけ
  → 消去回数を **約 1/1024** に削減 → フラッシュ寿命 **約1024倍**。
- 例: フラッシュ消去寿命を E 回とすると、素朴方式=E 保存、本方式≈ 1024×E 保存。
  E=10,000 なら約 **1000万回**保存可（要データシートで E を確認）。
- ホスト検証: 初回=0、各保存→復元一致、N セル満杯で循環消去、を確認。

### ユーザ提案との対応
ユーザ案は「マーカ(0x0000)＋値」の2セル方式で、更新時に旧マーカも書き換える。目的
（追記＋満杯時のみ消去で寿命延伸）は同じだが、本実装は**単一セル追記**に簡略化した：
- 1保存が **1書込**（案は マーカ＋値＋旧無効化で最大3書込）→ 書込が 1/3 で更に長寿命。
- 2KB で **1024** レコード（案の2セル=512 の倍）。
- 「先頭から最初の空の手前が最新」で一意に復元でき、マーカ／無効化書込が不要。
厳密に案どおりの2セル方式が必要なら容易に切替可能。

### 循環境界の電源断（保留）
満杯→全消去→先頭書込の間(約6ms/1024保存に1回)に電源断すると、その1回の設定が失われうる
（明るさは非致命的なので許容）。厳密化はセクタ ping-pong（新セクタに書いてから旧セクタ消去）。

## 温度警告灯 — CH32V003 に内蔵温度センサが無い問題
再検討で判明: **CH32V003 は内蔵ダイ温度センサを持たない**（ADC ch8=Vrefint / ch9=Vcalint のみ、
温度チャンネルは未定義）。当初 ch8 を温度として読む実装はバグ（無意味な値）だった。
ユーザ意図が「制御MOSFETへのサーマルカップリングで異常発熱を検知」なので、
**外付けアナログ温度センサ(NTC等)を MOSFET に熱結合して ADC で読む**方式に是正。
- `funAnalogInit()/funAnalogRead(ch)` を使用。ADCCLK≤14MHz にするため HCLK/8(6MHz)へ分周。
- 換算は近似1次（NTC は動作点付近を線形近似）。閾値+ヒステリシスで警告 GPIO を駆動。
- 任意で過熱時に本体 PWM も 0 クランプ（`WARN_TEMP_CUT_OUTPUT`）。

## WS2812/SK6812 常夜灯
本体が完全に暗い(`!g_on || level==0`)ときだけ、CIE 基準(cie.h 共用)で 明→暗 を三角波×CIE で
1往復し、その後インターバル完全オフ、を反復。色/色順/RGBW を config 化。
- ws2812b_simple.h(ch32fun) を使用。これが **SysTick=HCLK(48MHz)** を要求するため
  funconfig.h で `FUNCONF_SYSTICK_USE_HCLK 1`。時間ロジックは全て `Ticks_from_Ms` 経由で
  自動追従（SysTick 32bit は 48MHz で約89s ラップ、全ウィンドウ≪89s で安全）。
- 色順(GRB/RGB/GRBW/RGBW)はパック時にバイト順を切替。RGBW系は W チャンネルも CIE で明滅。

## バグ洗い出しの記録（このイテレーション）
- **[修正] 内蔵温度センサ不在**: ch8 は Vrefint。外付けセンサ方式へ是正（上記）。
- **[修正] WS_MAX_COLOR 桁不整合**: 既定 GRB(6桁)に対し 8桁(RGBW)値でバイトずれ → 6桁に修正、
  RGBW は別例として明記。
- **[追加] 静的アサート**: STORE_SIZE_BYTES%1KB、LEVELS<0xFFFF、SLOPE≠0、PERIOD≥2、WS_COUNT≥1。
- **[検証] ストア最終値 0x0000**: 0x0000(消灯)≠0xFFFF(空) で正しく復元。境界網羅テスト全合格＝バグ無し。
- **[検証] 条件コンパイル**: 全機能ON/OFF・RGBW・ハーフステップの各組合せで警告ゼロ。

## 検証状況
- ビルド検証済み: 全機能ON Flash 8200 B / 16KB (50%)・RAM 184 B (9%)。
  コアのみ約3KB、+常夜灯約3.6KB、DEBUG_LOG=1で+約1KB。
  全トグル組合せ(ON/OFF・RGBW・ハーフ)で警告ゼロ。
- LUT はホストで同式を検算（端点 0→TOP・単調性・重複ゼロ・知覚均等な低輝度分解能）。
- エンコーダ状態機械もホストで検証（クリーン回転=1発火・バウンス吸収・誤反転ゼロ）。
- ストア論理もホストで検証（初回=0・各保存→復元一致・満杯で循環消去・最終値0x0000）。
  ストア領域の1KB整列/セクタ分離を実 elf(g_store@0x1800, sec6–7)で確認。
- 常夜灯の呼吸カーブ(三角波×CIE)・WS色順パッキングもホスト検証。
- **★実機検証済み（2026-09-16〜, 実基板 PCB/LightBox・継続稼働中/問題なし）**: 常夜灯(SK6812/OST45050C1A-W,
  WS_ORDER=RGBW) / 明るさ調整(加速×3) / ON-OFFソフトスタート・ソフトオフ /
  **消灯・点灯 各約12時間 異常なし**。ダイ温度推定は誤遮断のため**不採用(TEMP_PROTECT_ENABLE 0)**。
- 未確認: フラッシュ長期摩耗(設計~1000万回)、外付けNTC温度保護(既定OFF)、PlatformIO ビルド。
- ハードウェア(BOM/回路/ピンアウト)は documents/HARDWARE.md。

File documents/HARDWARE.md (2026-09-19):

# LightBox Hardware (Board / Circuit / BOM)

**English** · [日本語](HARDWARE_JP.md) · [← README](../README.md)

Physical PCB for the CH32V003 LED Dimmer Controller. Complete KiCad project located at:
`PCB/LightBox/` (Schematic: `LightBox.kicad_sch` / PCB: `LightBox.kicad_pcb`).
Artwork image: `PCB/AertWork.png`. MOSFET symbol: `PCB/KiCad/FDS5680.*`.

> PCB design, schematic design, and artwork (including pin headers) are complete. **Wiring has been verified to match the active firmware identically.**

## System Overview

* **U1 CH32V003JxMx** (SOP8 / J4M6) — Main MCU

* **Q1 FDS5680** (N-channel MOSFET, SO-8) — **Low-side drive** for the main LED

* **D1 SK6812** (RGBW addressable = OptoSupply **OST45050C1A-W**) — Night light, data line on `PC4`

* **D2 LED** — **On-board pilot (status) LED**. Synchronized with Q1's `LED OUT` (drain) side

* **R1 100$\Omega$** — Series resistor from `PC2` to MOSFET gate

* **R2 10k$\Omega$** — Gate-to-GND pull-down (**fail-safe ensuring LED is OFF during reset or un-driven state**)

* **R3 100$\Omega$** — **Series current-limiting resistor for pilot LED D2** (connected to D2 cathode)

* **Main (Power) LED** — External to PCB. Connected via pin header from `LED OUT` (`J1-1`) (external current limiting required)

* **J1 Conn_01x09** (9-pin header) — Breakout for power, programming, encoder, and dual LED signals

* **SW2 RotaryEncoder_Switch** — Rotary encoder with push button switch

## Pin Assignment (U1 = CH32V003 SOP8)

| U1 Pin | Signal (Net) | Destination | Firmware `config.h` | 
 | -----: | ----- | ----- | ----- | 
| 1 PA1 | ENC A | SW2-A / J1-7 | `ENC_A_PIN=PA1` | 
| 2 VSS | GND | GND | — | 
| 3 PA2 | SW (Encoder Push) | SW2-S1 / J1-8 | `ENC_SW_PIN=PA2` | 
| 4 VDD | VDD | Power / J1-9 | — | 
| 5 PC1 | ENC B | SW2-B / J1-6 | `ENC_B_PIN=PC1` | 
| 6 PC2 | PWM $\rightarrow$ R1 $\rightarrow$ Q1 Gate | R1 / U1-6 | PWM=`PC2` (Fixed) | 
| 7 PC4 | LED2810 (SK6812 DIN) | D1-2 / J1-2 | `WS_DIN_PIN=PC4` | 
| 8 PD1 | SW IO (SWIO Flash/debug) | J1-3 | Preserved | 

$\rightarrow$ **PCB pinout matches the flashed firmware identically** (all features verified on real hardware).

## J1 9-Pin Header Pinout

| J1 | Signal | Description | 
 | ---: | ----- | ----- | 
| 1 | LED OUT | Main LED Cathode side (Q1 Drain). Connect external LED + current limiting here | 
| 2 | LED2810 / DIN | Night light SK6812 / OST45050C1A-W data input (`PC4`) | 
| 3 | SW IO | SWIO (WCH-LinkE Flashing / `debugprintf`, `PD1`) | 
| 4 | GND | Power / Signal Ground | 
| 5 | GND | Power / Signal Ground | 
| 6 | ENC B | Encoder Phase B (`PC1`) | 
| 7 | ENC A | Encoder Phase A (`PA1`) | 
| 8 | SW | Encoder Push Switch (`PA2`) | 
| 9 | VDD | Power Supply (**5V Input**. CH32V003 operates from 2.7V to 5.5V) | 

## Main LED Drive Stage (Low-Side Switch)

```
VDD ──▶ [External Main LED (≈1A)] ──▶ J1-1 (LED OUT) = Q1 (FDS5680) Drain
VDD ──▶ [Pilot LED D2] ─[R3 100Ω]──▶ (LED OUT)                      ← Status Indicator
PC2 ─[R1 100Ω]─┬─ Q1 Gate
               └─[R2 10kΩ]─ GND    (Pull-down: LED OFF during reset)
Q1 Source ── GND
```

* PWM (`PC2`) High $\rightarrow$ MOSFET ON $\rightarrow$ Drain pulled to GND $\rightarrow$ External LED and Pilot D2 illuminate.

* **R2 actively pulls the gate Low during boot/reset, keeping the LED OFF** (passive fail-safe).

* **External current limiting** (resistor or constant-current driver) must be provided for the main LED. Pilot LED D2 is limited by R3.

* FDS5680 is a 30V logic-level N-channel MOSFET. **Generates virtually no heat when driving a $\approx 1\text{A}$ LED** (heatsink is purely preventive).

## Power Supply

* **VDD = 5V Input**. Since the CH32V003 supports 5V operation, GPIO High levels reach $\approx 5\text{V}$, easily exceeding the SK6812 data input high threshold ($\approx 0.7 \times \text{VDD} = 3.5\text{V}$). This makes 5V preferable to 3.3V.

## LED Configuration Details

* **Main (Power) LED is External**: Connected via pin header at `LED OUT` (`J1-1`, Q1 drain). Current limiting is handled externally (resistor or CC driver). Verified operational with a **$\approx 1\text{A}$ LED**.

* **On-board Pilot LED D2**: Illuminates in sync with `LED OUT`, with **current limited by R3 (100$\Omega$)** (connected to D2 cathode). Acts as a physical status indicator for the output.

* SK6812 data line (`PC4` $\rightarrow$ DIN) is directly connected. For noisy environments, a series resistor of 100–470$\Omega$ and a decoupling capacitor ($0.1\mu\text{F}$ to a few $\mu\text{F}$) near the power pins can optionally be added.

> *Note:* Earlier references mentioning "R3 unconnected" were based on an outdated `LightBox.dsn` export prior to routing R3. The physical hardware has R3 wired in series with D2 as specified.

## Physical Hardware Verification — ✅ Verified (In active use, operating normally)

* **★ Flashed successfully on 2026-09-16** (WCH-LinkE / minichlink, CH32V003 UUID `a5-69-ab-cd-0d-91-bc-5b`). Running continuously without issues since.

* **★ Functional Verification Complete**: SK6812 / OST45050C1A-W night light breathing, brightness scaling (3x rotary acceleration), soft start / soft off transitions, and **12-hour continuous testing in both ON and OFF states passed without anomalies** (false over-temperature cutoffs resolved by setting thermal protection to OFF).

* **★ Prototyped on 1.27mm pitch perfboard with hand-wired circuit $\rightarrow$ Operational success confirmed**.

* **★ Integrated into custom 3D-printed enclosure designed in Fusion 360** (STL files located in `3D_Models/`).

* **Thermal Performance**: Although a heatsink was attached as a precaution, **virtually no heat generation was observed under a $\approx 1\text{A}$ LED load**. This confirms that previous false trips under duty-cycle-based die estimation were caused by math model discrepancies rather than physical heat, validating the decision to set `TEMP_PROTECT_ENABLE` to `0` (disabled). If thermal protection is required in the future, a physical external NTC sensor should be used.

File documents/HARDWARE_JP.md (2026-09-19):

# LightBox ハードウェア (基板 / 回路 / BOM)

[English](HARDWARE.md) · **日本語** · [← README](../README_JP.md)

CH32V003 LED 調光コントローラの実基板。KiCad プロジェクト一式:
`PCB/LightBox/`（回路図 `LightBox.kicad_sch` / 基板 `LightBox.kicad_pcb`）。
アートワーク画像: `PCB/AertWork.png`。MOSFETシンボル: `PCB/KiCad/FDS5680.*`。

> 基板設計・スキーマ設計・アートワーク（ピンヘッダ付き）完了。**ファーム(現行)と配線完全一致を確認済み**。

## 構成概要
- **U1 CH32V003JxMx**（SOP8 / J4M6）— メインMCU
- **Q1 FDS5680**（N-ch MOSFET, SO-8）— メインLED を**ローサイド駆動**
- **D1 SK6812**（RGBW アドレサブル = OptoSupply **OST45050C1A-W**）— 常夜灯、データ=PC4
- **D2 LED** — **基板上パイロット(点灯表示)LED**。Q1 の `LED OUT`(ドレイン)側に同期して点灯
- **R1 100Ω** — PC2 → MOSFET ゲート直列
- **R2 10K**  — ゲート → GND プルダウン（**リセット/未駆動時に LED OFF のフェイルセーフ**）
- **R3 100Ω** — **パイロットLED D2 の直列(電流制限)抵抗**（D2-K に接続）
- **メイン(パワー)LED** — 基板外。`LED OUT`(J1-1) からピンヘッダ経由で外部接続（電流制限は外部）
- **J1 Conn_01x09**（9ピンヘッダ）— 電源/書込/エンコーダ/両LED信号の引き出し
- **SW2 RotaryEncoder_Switch** — ロータリーエンコーダ（押しSW付き）

## ピン割当（U1 = CH32V003 SOP8）
| U1ピン | 信号(ネット) | 接続先 | ファーム config |
|---:|---|---|---|
| 1 PA1 | ENC A | SW2-A / J1-7 | `ENC_A_PIN=PA1` |
| 2 VSS | GND  | GND | — |
| 3 PA2 | SW（エンコーダ押下） | SW2-S1 / J1-8 | `ENC_SW_PIN=PA2` |
| 4 VDD | VDD | 電源 / J1-9 | — |
| 5 PC1 | ENC B | SW2-B / J1-6 | `ENC_B_PIN=PC1` |
| 6 PC2 | PWM → R1 → Q1ゲート | R1 / U1-6 | PWM=PC2（固定） |
| 7 PC4 | LED2810（SK6812 DIN） | D1-2 / J1-2 | `WS_DIN_PIN=PC4` |
| 8 PD1 | SW IO（SWIO 書込/debug） | J1-3 | 温存 |

→ **PCB のピン配線はフラッシュ済みファームと完全一致**（実機で全機能動作を確認済み）。

## J1 9ピンヘッダ ピンアウト
| J1 | 信号 | 説明 |
|---:|---|---|
| 1 | LED OUT | メインLED カソード側（Q1 ドレイン）。外部LED＋電流制限をここへ |
| 2 | LED2810 / DIN | 常夜灯 SK6812/OST45050C1A-W データ入力（PC4） |
| 3 | SW IO | SWIO（WCH-LinkE 書込 / debugprintf、PD1） |
| 4 | GND | — |
| 5 | GND | — |
| 6 | ENC B | エンコーダ B 相（PC1） |
| 7 | ENC A | エンコーダ A 相（PA1） |
| 8 | SW | エンコーダ押しSW（PA2） |
| 9 | VDD | 電源（**5V 給電**。CH32V003 は 2.7〜5.5V 動作） |

## メインLED 駆動段（低側スイッチ）
```
VDD ──▶ [外部メインLED(≒1A)] ──▶ J1-1(LED OUT)=Q1(FDS5680)ドレイン
VDD ──▶ [パイロットLED D2] ─[R3 100Ω]─▶ (LED OUT)          ← 本体状態表示
PC2 ─[R1 100Ω]─┬─ Q1 ゲート
               └─[R2 10K]─ GND   (プルダウン: リセット時LED OFF)
Q1 ソース ── GND
```
- PWM(PC2) High → MOSFET ON → ドレインがGNDへ → 外部LED / パイロットD2 が点灯。
- **リセット/起動前は R2 が確実にゲートを引き下げ、LED は消灯**（受動的フェイルセーフ）。
- 外部メインLEDの**電流制限は外部**（抵抗 or 定電流）。パイロットD2は R3 で制限。
- FDS5680 は 30V 級ロジックレベル N-ch。**≒1A LED で発熱ほぼ無し**（ヒートシンクは予防的）。

## 電源
- **VDD=5V 給電**。CH32V003 は 5V 動作可のため、GPIO High ≈ 5V となり
  SK6812 系のデータ閾値（約 0.7×VDD=3.5V）を確実に満たす（3.3V ではなく 5V が有利）。

## LED まわりの構成（確定）
- **メイン(パワー)LED は基板外**：`LED OUT`(J1-1, Q1ドレイン) からピンヘッダ経由で外部接続。
  電流制限は外部（抵抗 or 定電流ドライバ）で設ける。実測 **≒1A のLED**で運用実績あり。
- **基板上パイロットLED D2**：`LED OUT` 側に同期点灯し、**R3(100Ω) で電流制限**（D2-K 接続）。
  本体出力の状態表示になる。
- SK6812 データ線(PC4→DIN) は直結。ノイズが気になる環境では 100〜470Ω 直列＋
  電源近傍デコップリング(0.1µF/数µF) を追加可（任意）。

> ※本ファイルの初版で「R3 未接続」と記したのは、参照した `LightBox.dsn`(Specctra) が
>   R3 結線前の古いエクスポートだったため。現物は上記のとおり R3=D2 直列で接続済み。

## 検証状況（実機） — ✅ 実機検証済み（継続稼働中・問題なし）
- **★2026-09-16 実機フラッシュ成功**（WCH-LinkE / minichlink、CH32V003 UUID a5-69-ab-cd-0d-91-bc-5b）。以降 問題なく稼働中。
- **★実機動作確認済**: 常夜灯(SK6812/OST45050C1A-W) / 明るさ調整(加速×3) /
  ON-OFF ソフトスタート・ソフトオフ / **消灯・点灯 各約12時間 異常なし**
  （過熱誤遮断は温度保護オフで解消、長時間安定）。
- **★ユニバーサル基板(1.27mmピッチ)でフリーハンド同等回路を製作 → 動作確認済**。
- **★Fusion 360 で設計・3Dプリントした筐体に組み込み、実運用中**（STL は `3D_Models/`）。
- **発熱**: 念のためヒートシンクを追加しているが、**≒1A のLED接続でほとんど発熱は見られない**。
  → デューティ由来の「ダイ温度推定」が誤遮断していたのは実発熱ではなく推定値の問題だったことを裏付け、
  温度保護OFF(不採用)の判断は妥当。実発熱で保護が要るなら外付けNTC実測へ。

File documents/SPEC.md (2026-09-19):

# LightBox Specification Document (SPEC)

**English** · [日本語](SPEC_JP.md) · [← README](../README.md)

Functional specification for the CH32V003 LED Dimmer Controller. Architectural rationale and design decisions can be found in [DESIGN.md](DESIGN.md), and configuration references in [CONFIG_REFERENCE.md](CONFIG_REFERENCE.md).

## 1. Target & Architecture
- **MCU**: CH32V003 (Recommended package: **F4P6 TSSOP20**; SOP8 supports core functionality only)
- **Framework**: ch32fun (self-contained)
- **Clock**: HCLK 48MHz, SysTick = HCLK (48MHz) *Required for WS2812 driver timings*
- **Inputs**: Rotary Encoder (A/B + Push Switch), External Temperature Sensor (NTC, etc.)
- **Outputs**: Main Output PWM 1-channel (LED), Over-temperature Warning GPIO, WS2812/SK6812 Night Light

## 2. Dimming Curve (CIE 1931 $L^*$)
- Step $i \in [0..64]$ is allocated at equal intervals of lightness $L^* \rightarrow$ inverse mapping $L^* \rightarrow \text{luminance } Y \rightarrow \text{duty cycle}$ (1 click = perceptually uniform change).
  - $L^* \le 8: Y = L^* / 903.3$ (linear toe) / $L^* > 8: Y = ((L^* + 16) / 116)^3$
- Uses integer arithmetic only (cubic terms computed using `uint64_t`), without `libm` or floating-point libraries. Shared between the main output and night light (`cie.h`).

## 3. PWM Output
- `TIM2_CH2` (remap 1) = `PC2`, 16-bit counter. Default `PWM_TOP = 4095` ($\approx 12\text{kHz}$). Maximum limit: 65,535.
- **Output pin selectable via `PWM_PIN`** (default `PC2`=TIM2_CH2; also `PC1`=TIM2_CH4 / `PA1`=TIM1_CH2 / `PC4`=TIM1_CH4). `source/pins.h` derives the timer/channel/remap and validates it at compile time. Only `PC2` is hardware-verified; other pins are compile-supported.

## 4. Encoder & Debouncing
- **Full-step State Machine (Ben Buxton)**: Emits $\pm 1$ only upon completing a valid state transition path $\rightarrow$ suppresses single-phase bounce artifacts.
- **Direction Reversal Lockout**: If a step in the opposite direction occurs within `ENC_REVERSAL_LOCK_MS` (default 5ms), it is treated as physical bounce and discarded. Steps in the same direction are unrestricted to allow fast spinning.
- Supports half-step hardware (`ENC_HALF_STEP`) and direction inversion (`ENC_REVERSE`).
- **Fast-spin Snap**: Performing `SNAP_CLICKS` steps in the same direction within `SNAP_WINDOW_MS` snaps brightness immediately to 100% or 0%.
- **Push Switch**: Time-based integration debounce (`SW_DEBOUNCE_MS`). Short press toggles power ON/OFF.

## 5. Non-Volatile Brightness Memory (Wear Leveling)
### Storage Strategy
- Dedicated reservation of `STORE_SIZE_BYTES` (default 2KB) via a 1KB-aligned `const` array. Single-cell append log (last-written-wins).
  - *Note*: Placement is managed by the linker (immediately following code execution space) rather than hardcoded to the flash boundary. Because it is **1KB aligned and sized as a multiple of 1KB**, it exclusively occupies dedicated flash sectors, guaranteeing that erase operations will not affect adjacent code regardless of absolute address.
  - *Note*: Memory address may shift across firmware compilation sizes. Default data is embedded as `0xFF` in the binary payload. Maintaining persistence across firmware re-flashing requires fixing the memory location in the linker script.
- **Save Operation**: Appends 2 bytes to the first empty cell (`0xFFFF`) from the array start (1 save = 1 write). Active value resides immediately before the first empty cell. When full, 2 sectors are erased and rotation resets to the start. Default initial state (`0xFFFF` array) restores as OFF / Brightness 0.
- **Power State Persistence**: Packs both state and level into a single cell (`bit15 = ON`, `bit[0..6] = level`; maximum value `0x8040`, non-conflicting with empty marker `0xFFFF`).
  $\rightarrow$ Remembers power state across power cycles and restores to OFF if powered down while OFF.
- **Write Timing**: Commits once after state (`ON/OFF + level`) remains unchanged for `STORE_COMMIT_MS` (5 seconds).
  *Note: Powering off within 5 seconds of an adjustment leaves the latest change uncommitted to minimize flash wear.*

### Flash Endurance Estimation
- CH32V003 Flash Erase Endurance $\approx \mathbf{10,000 \text{ cycles/sector}}$ (WCH datasheet nominal value).
- $2\text{KB} / 2\text{ bytes} = \mathbf{1024 \text{ records/erase cycles}}$. Therefore:

  $$\text{Estimated Total Write Cycles} \approx 1024 \times 10,000 = \mathbf{\approx 10,240,000 \text{ cycles}}$$

- **Assessment**: Exceeds 100,000 write cycles by approximately 100 times. $\rightarrow$ **The default 2KB allocation is sufficient; no flash expansion required.**
  - Even assuming a conservative sector limit of 1,000 cycles, $1024 \times 1000 \approx 1,024,000$ operations.
  - The 5-second delayed write filter consolidates each adjustment session into a single commit, reducing real-world consumption far below theoretical limits.
- To expand log retention, scale `STORE_SIZE_BYTES` in 1KB increments ($4\text{KB} = 2048$ records).

### Handling Zero Level Edge Cases
- Brightness levels range from $0..64$. **`0x0000` (lights off) is a valid data state**, whereas empty cells read `0xFFFF`. Because these values are distinct, zero values restore accurately. Verified on host test harness across edge cases (single 0, consecutive 0s, terminal cell 0, alternating 0/non-zero, full wraparound 0).

## 6. Thermal Fail-Safe (Forced Cutoff & Thermal Throttling)
> **★ Default Status: OFF (`TEMP_PROTECT_ENABLE 0`)**. Die temperature estimation previously caused false triggers on physical hardware during full output due to mathematical model drift without an physical sensor.
> $\rightarrow$ **Die estimation is discarded**. Thermal protection should only be enabled when using external NTC physical sensing (Section 6.2).
> The following describes the system behavior when enabled.

Selectable temperature source via `TEMP_SOURCE`:

### 6.1 Internal Die Temperature Estimation (Deprecated / Reference)
- ★ **CH32V003 lacks an integrated internal die temperature sensor** (ADC channels only expose `ADC_CH8 = Vrefint` and `ADC_CH9 = Vcalint`). Thermal state is estimated via a thermal rise model:
  - $T_{\text{target}} = T_{\text{ambient}} (28^\circ\text{C}) + \left(\frac{\text{effective\_duty}}{\text{PWM\_TOP}}\right) \times T_{\text{rise\_full}} (60^\circ\text{C})$
  - $T_{\text{est}}$ follows $T_{\text{target}}$ using a first-order lag filter with time constant `DIE_TAU_MS`.
  - Uses effective duty cycle (reflecting active cutoffs/throttling) as input, enabling estimation decay upon shutdown.
- Zero external component requirement. Output values are indicative reference approximations.

### 6.2 External Analog Sensor (Physical Sensing)
- Thermally couples an NTC thermistor to the switching MOSFET and samples via ADC (`TEMP_SENSE_PIN`; the ADC channel is derived automatically). Calibrated via linear approximation coefficients `TEMP_CAL_*`.

### 6.3 Protection Logic (Both Sources)
- Exceeding `WARN_TEMP_C` ($80^\circ\text{C}$) $\rightarrow$ **Forces main output PWM (MOSFET) to 0** to mitigate thermal hazards.
- Resumes operation once temperature drops below hysteresis limit `WARN_TEMP_HYST_C`.
- **Thermal Throttling**: Every `THERMAL_TRIP_N` ($n$) trip/recovery cycles, maximum allowed output duty cumulative drops by `THERMAL_THROTTLE_PCT` ($j\%$), capped at `THERMAL_THROTTLE_MAX`.
  $\rightarrow$ Automatically limits power dissipation under sustained thermal loads until thermal equilibrium is maintained below the threshold.
- Optional indicator output via `WARN_LED_ENABLE` (asserted High during over-temperature condition).

## 5b. Soft Start (Fade-In / Fade-Out)
- Smoothly fades output to target brightness upon power toggle (push switch) or system boot.
- **Perceptual lightness $L^*$ is linearly interpolated over time**, converting each step to PWM duty via CIE 1931 $\rightarrow$ visually linear dimming transitions.
- Independent durations via `SOFT_START_ON` / `SOFT_START_OFF` (in milliseconds; 0 = immediate, max 65,535ms).
- Direct rotary encoder adjustments bypass soft start for immediate response. Rotary or switch inputs during an active fade transition smoothly recalculate target trajectory from current dynamic output level without abrupt jumps.
- Night light sequence initiates only after soft-off fade completely reaches zero brightness.

## 6b. Watchdog Timer (IWDG)
- Automatic system reset recovery in event of firmware execution stall. Timeout configurable via `WDT_TIMEOUT_MS` (default 2000ms, range $\approx 2..\text{8190ms}$).
- Driven by low-speed internal oscillator (LSI $\approx 128\text{kHz}$) divided by 256. Refreshed at top of main loop execution cycle.
- Timeout duration validated to exceed longest blocking operation (flash page erase/write cycles $\approx \text{several ms}$).
- *Note: If `DEBUG_LOG = 1` and SWD host is disconnected, unbuffered `printf` blocking may trigger watchdog resets.*

## 6c. EMI Mitigation (High-Current Load Optimization)
- **Slew Rate Control**: Configures GPIO speed `PWM_SLEW_MHZ` (2, 10, or 30MHz) to soften edge transitions and suppress high-frequency harmonics (2MHz recommended for high-current driving).
- **Spread Spectrum**: `PWM_SPREAD_SPECTRUM = 1` applies micro-dither ($\pm\text{PWM\_SPREAD\_RANGE}$) to auto-reload register `ATRLR` to spread fundamental frequency peaks. Duty ratios dynamically track period adjustments, **maintaining constant light output**. Dither period managed via `PWM_SPREAD_PERIOD_MS`.

## 7. WS2812 / SK6812 Night Light
- Active exclusively when main lighting output is fully extinguished (`!g_on || level == 0`).
- **Operating Cycle**: Executes smooth bright-to-dark pulse over `NIGHTLIGHT_PERIOD_MS` ($n$) using triangular wave mapped through CIE dimming curves.
- Enters complete off state for `NIGHTLIGHT_INTERVAL_MS` ($i$) after each cycle before repeating. Disables immediately upon main light activation.
- Time tracking evaluates on millisecond scale prior to scaling to prevent integer overflow in `Ticks_from_Ms(period) = period \times 48000` ($period \gtrsim 89.5\text{s}$). Cycle/interval configurations constrained to $\le 60,000\text{ms}$ to maintain safety margin against 32-bit SysTick roll-over ($\approx 89.5\text{s}$).
- Configurable maximum color `WS_MAX_COLOR` (RGB format `0xRRGGBB` / RGBW format `0xRRGGBBWW`).
- Selectable color channel ordering via `WS_ORDER` (GRB, RGB, GRBW, RGBW).
- Supports SK6812 RGBW LED protocol. Configured on `WS_DIN_PIN` (GPIO port/number derived automatically) for `WS_COUNT` elements.
- Frame updates emitted at `NIGHTLIGHT_REFRESH_MS` intervals via `ws2812b_simple.h` (requires `SysTick = HCLK`).

## 8. Boot Sequence
1. Execute `SystemInit` $\rightarrow$ Initialize GPIO and encoder hardware peripherals.
2. Generate CIE 1931 lookup tables (LUT).
3. Restore state and level from non-volatile flash storage (default initial state = level 0, `g_on = level > 0`).
4. Initialize PWM peripheral (applying restored state).
5. Initialize Temperature ADC / Night Light control logic.
6. Enter main execution loop (Encoder processing $\rightarrow$ Switch debounce $\rightarrow$ Temperature checking $\rightarrow$ Night Light state engine $\rightarrow$ Flash store commit processing).

## 9. Verification & Status — ✅ Verified on Physical Hardware (In Continuous Operation)
- **★ Hardware Execution Verified (2026-09-16 to present)**: Flashed and operational on target PCB (`LightBox`). 
  - Verified Night Light function (SK6812 / OST45050C1A-W).
  - Verified CIE brightness control, rotary acceleration ($3\times$), and snapping.
  - Verified Soft-Start / Soft-Off transition curves.
  - **12-hour continuous operation in ON and OFF states validated without anomalies** (disabling uncalibrated thermal protection eliminated false shutdowns).
- **Host Unit Tests Passed**: CIE calculations, state machine transitions, flash boundary storage handling, night light curves, channel ordering, acceleration, and thermal modeling.
- **Build Verification**: Zero warnings across configuration permutations. Memory usage footprint: Flash 50%, RAM 3.5%.
- **Unverified Edge Cases**: Long-term flash endurance wear limit testing (design target $\approx 10^7$ writes), physical external NTC thermal protection behavior (default OFF), PlatformIO toolchain integration.
- Hardware specifications, schematics, and BOM detailed in [HARDWARE.md](HARDWARE.md).

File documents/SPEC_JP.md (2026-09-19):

# LightBox 仕様書 (SPEC)

[English](SPEC.md) · **日本語** · [← README](../README_JP.md)

CH32V003 LED 調光コントローラの機能仕様。設計判断の根拠は [DESIGN_JP.md](DESIGN_JP.md)、
設定項目は [CONFIG_REFERENCE_JP.md](CONFIG_REFERENCE_JP.md)。

## 1. 対象・構成
- MCU: CH32V003（推奨パッケージ **F4P6 TSSOP20**。SOP8 はコア機能のみ）
- フレームワーク: ch32fun（自己完結）
- クロック: HCLK 48MHz、SysTick=HCLK（48MHz）※WS2812 ドライバ要件
- 入力: ロータリーエンコーダ(A/B + 押しSW)、外付け温度センサ(NTC等)
- 出力: 本体 PWM 1ch(LED)、温度警告 GPIO、WS2812/SK6812 常夜灯

## 2. 調光カーブ（CIE 1931 L*）
- 段 i(0..64) を明度 L* に等間隔割当 → L*→輝度Y→duty 逆算（1クリック=知覚的に等量）。
  - `L*≤8: Y=L*/903.3`（直線トウ） / `L*>8: Y=((L*+16)/116)^3`
- 整数演算のみ（立方は uint64）、libm/float 不使用。本体と常夜灯で共用（`cie.h`）。

## 3. PWM 出力
- TIM2_CH2(remap1)=PC2、16bit カウンタ。既定 `PWM_TOP=4095`（≈12kHz）。最大 65535。
- **出力ピンは `PWM_PIN` で選択可**（既定 `PC2`=TIM2_CH2。他に `PC1`=TIM2_CH4 / `PA1`=TIM1_CH2 / `PC4`=TIM1_CH4）。`source/pins.h` がタイマ/チャネル/remap を導出しコンパイル時に検証。実機検証済は `PC2` のみ、他はコンパイル対応。

## 4. エンコーダ / チャタリング吸収
- フルステップ状態機械(Ben Buxton)。正しい遷移経路を完走時のみ ±1 発火 → 単相バウンス構造吸収。
- **方向反転ロックアウト**: 直前と逆方向のステップが `ENC_REVERSAL_LOCK_MS`(既定5ms)以内なら
  物理的にあり得ない=バウンスとして破棄。同方向は無制限（高速回しを妨げない）。
- ハーフステップ品対応(`ENC_HALF_STEP`)、CW/CCW 反転(`ENC_REVERSE`)。
- 高速回しスナップ: `SNAP_WINDOW_MS` 内に同方向 `SNAP_CLICKS` 回で 100%/0%。
- 押しSW: 時間ベース積分デバウンス(`SW_DEBOUNCE_MS`)、短押しで ON/OFF。

## 5. 明るさ不揮発記憶（ウェアレベリング）
### 方式
- `STORE_SIZE_BYTES`(既定2KB) を 1KB整列 const 配列で専用予約。単一セル追記ログ(last-written-wins)。
  ※配置は「Flash末尾」ではなくリンカ任せ(コード直後)。だが **1KB整列 かつ サイズ=1KBの倍数**
  なので専用セクタを丸ごと占有し、消去が他データに波及しないことは**位置に依存せず保証**される
  （const オブジェクト=リンカが排他確保、実測でも同セクタ内は g_store のみ）。
  ※アドレスはファーム容量で変わりうる／保存データはバイナリに0xFF初期値として含まれ再書込で消える
  （ファーム更新をまたいで残すには別途リンカスクリプトで固定領域を確保する必要あり）。
- 保存 = 先頭から最初の空(0xFFFF)へ 2バイト追記（1保存=1書込）。現在値=最初の空の手前。
  満杯で 2 セクタ消去し循環。初回(全0xFFFF)=OFF/明るさ0。
- **ON/OFF も保存**: 1セルに `bit15=ON, bit0..6=level` をパック（最大0x8040, 空0xFFFFと非衝突）。
  → 電源を切った(OFF)状態も記憶し、次回投入時に OFF で復帰する。
- 保存タイミング: 状態(ON/OFF+level)が `STORE_COMMIT_MS`(5秒)変化しなくなってから 1回だけ。
  ※5秒未満で電源断すると直前の変更は未保存（フラッシュ摩耗を抑える遅延書込の仕様）。

### フラッシュ寿命（データシート上の想定設定回数）
- CH32V003 フラッシュ消去寿命 ≈ **10,000 回/セクタ**（WCH データシート値。実機で要確認）。
- 2KB / 2バイト = **1024 レコード**／消去。よって:

  **想定保存回数 ≈ 1024 × 10,000 = 約 10,240,000 回（約1000万回）**

- **判定**: 10万回を大きく上回る（約100倍以上）。→ **現状の 2KB でフラッシュ増設は不要**。
  - 仮に消去寿命が 1,000 回でも 1024×1000 ≈ 102万回で 10万超。
  - さらに「5秒後に1回だけ書込」で実書込は1調整セッション=1回に圧縮され、実運用の
    消費はこの理論値よりずっと少ない。
- 記録数を増やしたい場合のみ `STORE_SIZE_BYTES` を 1KB 単位で増やす（4KB=2048レコードで倍）。

### 最終値 0x0000 の扱い（境界）
- レベルは 0..64 で **0x0000(=消灯) は有効値**、空セルは 0xFFFF。両者は別物なので
  「最終値が0」でも正しく復元される。ホストで境界網羅テスト済（単発0/連続0/最終セル0/
  0とnonzero交互/満杯循環後0 — 全て復元一致）。**この件のバグは無し。**

## 6. 過熱フェイルセーフ（強制遮断＋サーマルスロットル）
> **★現状 既定OFF（`TEMP_PROTECT_ENABLE 0`）**。当初のダイ温度「推定」は実測でないため
> 全開時に推定値だけで閾値を超え、点けっぱなしで**急に消灯する誤遮断**が実機で発生した。
> → ダイ推定は**不採用**。本当に発熱保護が要る場合のみ、外付けNTC実測(6.2)で有効化する。
> 以下は機能の仕様として記載（有効化した場合の動作）。

温度源を 2 種から選択（`TEMP_SOURCE`）:

### 6.1 ダイ温度「推定」（不採用・参考）
- ★**CH32V003 に内蔵ダイ温度センサは無い**（ADC ch8=Vrefint / ch9=Vcalint のみ）。
  実測できないので **熱モデルで推定**する（「おおよその値／28℃からの上昇分」で十分という前提）:
  - `T_target = DIE_AMBIENT_C(28℃) + (実効duty/PWM_TOP) × DIE_RISE_AT_FULL_C(60℃)`
  - `T_est` は時定数 `DIE_TAU_MS` で `T_target` に一次追従。
  - 実効デューティ（遮断/スロットル反映後）を入力にするので、遮断すれば推定も下がり再開する。
- 外付け部品ゼロ。値は目安（`DIE_RISE_AT_FULL_C` を実機の発熱に合わせ調整）。

### 6.2 外付けアナログセンサ（実測・要ピン）
- NTC 等を制御MOSFETに熱結合し ADC(`TEMP_SENSE_PIN`。ADCチャネルは自動導出)で実測。近似1次校正 `TEMP_CAL_*`（要校正）。

### 6.3 保護動作（両ソース共通）
- `WARN_TEMP_C`(80℃)超 → **本体PWM(MOSFET)を強制的に0**（火災リスク回避）。
- `WARN_TEMP_HYST_C` 下がって再開。
- **サーマルスロットル**: 遮断→再開を `THERMAL_TRIP_N`(n)回繰り返すごとに、最大出力を
  `THERMAL_THROTTLE_PCT`(j)% ずつ累積ダウン（上限 `THERMAL_THROTTLE_MAX`）。
  → 過熱を繰り返す環境では自動的に出力が下がり、いずれ定常温度が閾値未満に収まって安定。
  （ホスト検証: 全開→80℃遮断→72℃再開を3回→20%ダウン→実効80%→定常76℃で以後トリップ停止。）
- 任意で警告灯 `WARN_LED_ENABLE`（過熱中 High）。

## 5b. ソフトスタート（フェードイン/アウト）
- 電源(押しSW)ON/OFF 時、および起動(電源投入)時に、設定輝度まで滑らかにフェード。
- **明度 L*(知覚量)を時間に対し線形補間**し、各点を CIE で duty 化 → 目で見て均等な変化。
  （duty は暗部で細かく明部で粗く変化＝知覚リニア。ホスト検証: L*時間差分ほぼ一定。）
- `SOFT_START_ON`/`SOFT_START_OFF`(ms, 0=即時, 最大65535≒65.5s)。ON/OFFで別指定。
- エンコーダ操作は即応（ソフトスタート対象外）。フェード中の再トグル/回転は現在輝度から
  滑らかに目標へ追従（ジャンプしない）。押しSWチャタは時間ベースデバウンスで吸収。
- 常夜灯はフェード完了で輝度0になってから開始（フェード中は点かない）。

## 6b. ウォッチドッグ（IWDG）
- ファーム暴走時に自動リセットで復帰。`WDT_TIMEOUT_MS`(既定2000ms、約2〜8190ms)。
- LSI(≈128kHz)/256 駆動でタイムアウトは概算。メインループ先頭で毎周リフレッシュ。
- 最悪ブロック（フラッシュ書込 数ms 等）よりタイムアウトが十分長いことを確認済み。
- ※`DEBUG_LOG=1` かつ SWD ホスト未接続だと printf 停滞で WDT リセットしうる（開発時の注意）。

## 6c. EMI 対策（大電流LED向け）
- **スルーレート制御**: PWM 出力ピンの GPIO 速度 `PWM_SLEW_MHZ`(2/10/30) を下げてエッジを鈍らせ
  高調波を低減（大電流は 2MHz 推奨）。
- **スペクトラム拡散**: `PWM_SPREAD_SPECTRUM=1` で ATRLR を `±PWM_SPREAD_RANGE` 微小ディザし
  基本波のピークを分散。duty比は周期に追従させるので **明るさは不変**。`PWM_SPREAD_PERIOD_MS` 間隔。

## 7. WS2812 / SK6812 常夜灯
- 本体が「完全に暗い」（`!g_on || level==0`）ときだけ動作。
- 1周期: `NIGHTLIGHT_PERIOD_MS`(n) かけて CIE 基準で 明→暗 を1往復（三角波×CIE）。
- 周期後 `NIGHTLIGHT_INTERVAL_MS`(i) 完全オフ → 反復。本体を明るくすると即オフ。
- 時間判定は**ms基準で比較**（経過を先に ms 化）。`Ticks_from_Ms(period)=period×48000` の
  uint32 オーバーフロー(period≳89.5s)を回避。周期/間隔は静的に ≤60000ms に制約(SysTick
  32bit ラップ~89.5s の安全マージン)。
- 最大色 `WS_MAX_COLOR`（RGB=0xRRGGBB / RGBW=0xRRGGBBWW）。各chを CIE で明滅。
- チップのバイト並び `WS_ORDER` を GRB/RGB/GRBW/RGBW から選択（製品差を吸収）。
- SK6812 RGBW 対応。データ線 `WS_DIN_PIN`（port/番号は自動導出）、`WS_COUNT` 個。
- 送信は `NIGHTLIGHT_REFRESH_MS` 間隔。ws2812b_simple.h(ch32fun) 使用（SysTick=HCLK 要件）。

## 8. 起動シーケンス
1. SystemInit → GPIO/エンコーダ初期化
2. CIE LUT 生成
3. ストアから前回明るさ復元（初回=0、`g_on=level>0`）
4. PWM 起動（復元値を反映）
5. 温度 ADC / 常夜灯 初期化
6. メインループ（エンコーダ/SW/温度周期/常夜灯/ストアコミット）

## 9. 検証状況 — ✅ 実機検証済み（継続稼働中・問題なし）
- **★実機動作 確認済（2026-09-16〜、以降 問題なく稼働中）**: 実基板(PCB/LightBox)・配線一致・フラッシュ成功。
  常夜灯(SK6812/OST45050C1A-W) / 明るさ調整(CIE・加速×3・スナップ) /
  ON-OFF ソフトスタート・ソフトオフ / **消灯・点灯 各約12時間 異常なし**（温度保護OFFで
  誤遮断解消・長時間安定）。
- ホスト検証済: CIE、状態機械、ストア境界、常夜灯カーブ、色順、加速、熱モデル。
- ビルド検証済: 全機能組合せで警告ゼロ、Flash 50%/RAM 3.5%。
- 未確認: フラッシュ長期摩耗(設計~1000万回)、外付けNTC温度保護(既定OFF)、PlatformIO ビルド。
- ハードウェア詳細(BOM/回路/J1): [HARDWARE_JP.md](HARDWARE_JP.md)。

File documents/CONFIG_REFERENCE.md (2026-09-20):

# LightBox Configuration Reference Guide (config.h)

**English** · [日本語](CONFIG_REFERENCE_JP.md) · [← README](../README.md)

Full reference for all parameters in `source/config.h`. Rebuild after changing any values (refer to [README](../README.md)).
Pins are named using ch32fun pin nomenclature (`PA1`, `PC2`, `PD0`, etc.).

## Pin Assignments (one macro per feature)

Each feature is assigned with a **single pin macro**. `source/pins.h` derives the GPIO
port/number, ADC channel, and PWM timer/channel/remap automatically, and rejects capability
violations (non-PWM / non-ADC pins) and pin conflicts (two features on one pin) at **compile
time** (`_Static_assert`). SOP8 (J4M6) pins: `PA1 PA2 PC1 PC2 PC4 PD1(SWIO)`.

| Item | Default | Description |
|---|---|---|
| `PWM_PIN` | `PC2` | Main LED PWM output. PWM-capable pins only: `PC2`(TIM2_CH2) / `PC1`(TIM2_CH4) / `PA1`(TIM1_CH2) / `PC4`(TIM1_CH4). **`PC2` is the hardware-verified default; other pins are compile-supported but not hardware-verified** |
| `ENC_A_PIN` | `PA1` | Encoder Phase A (Internal Pull-Up) |
| `ENC_B_PIN` | `PC1` | Encoder Phase B (Internal Pull-Up) |
| `ENC_SW_PIN` | `PA2` | Push Button Switch (Internal Pull-Up, Active Low) |

## PWM (16-bit TIM2)

| Item | Default | Description |
|---|---|---|
| `PWM_TOP` | `4095` | Resolution - 1. Frequency = `48MHz / (TOP + 1) / (PSC + 1)`. Max 65535. Increasing it results in smoother dimming at a lower frequency. |
| `PWM_PSC` | `0` | Prescaler |

## Dimming Levels

| Item | Default | Description |
|---|---|---|
| `LEVELS` | `64` | Number of steps (0 = Off to LEVELS = Max) |
| `LEVEL_INIT` | `32` | Startup brightness level when persistent store is disabled (only active when `STORE_ENABLE=0`) |

> The dimming curve (CIE L*) is fixed and parameterless (it directly uses the formula defined for perceptually linear light adjustment).

## Encoder / Debounce

| Item | Default | Description |
|---|---|---|
| `ENC_REVERSE` | `0` | Set to `1` to swap CW/CCW direction (accommodates hardware/wiring variations) |
| `ENC_HALF_STEP` | `0` | `0` = Full-step (4 transitions = 1 step) / `1` = Half-step (2 transitions = 1 step) |
| `ENC_ACCEL_ENABLE` | `1` | Acceleration: Turning quickly multiplies step count |
| `ENC_ACCEL_FACTOR` | `3` | Step multiplier per click during fast turns (3x) |
| `ENC_ACCEL_WINDOW_MS` | `50` | If time since last click in the same direction is less than this value (ms), enable acceleration |
| `ENC_REVERSAL_LOCK_MS` | `5` | Reverse steps occurring within this time window are ignored as bounce. Shorten if fast inputs drop clicks, lengthen if chatter remains |
| `SW_DEBOUNCE_MS` | `20` | Debounce stabilization time for push switch |

## Fast Turn Snap

| Item | Default | Description |
|---|---|---|
| `SNAP_WINDOW_MS` | `500` | Detection time window (ms) |
| `SNAP_CLICKS` | `6` | Number of clicks in the same direction required within the window to trigger snap ($\ge 2$) |

## Operational Options

| Item | Default | Description |
|---|---|---|
| `WAKE_ON_TURN` | `1` | Turning the encoder while off automatically turns the light on (only if resulting level > 0; turning towards dark keeps level at 0 and stays off). Set to `0` to require button push to turn on |
| `PWM_ON_TIME_S` | `0` | **Auto-off timer (seconds)**: turns the main output off (soft fade) this many seconds after it was switched on. `0` = disabled (stays on). Any encoder/switch activity resets (extends) the countdown. Lowers average on-time → saves battery, and adds an auto-off convenience on continuous power |
| `SOFT_START_ON` | `800` | Turn-on fade-in time (ms). `0` = Instantaneous, Max = 65535 ($\approx 65.5\text{s}$). Perceptually linear based on CIE |
| `SOFT_START_OFF` | `600` | Turn-off fade-out time (ms). `0` = Instantaneous, Max = 65535 |
| `DEBUG_LOG` | `0` | Set to `1` to enable SWD printf (development only). **Must be set to `0` for normal operation** (blocking printf can cause missed events) |

## Non-Volatile Brightness Store

| Item | Default | Description |
|---|---|---|
| `STORE_ENABLE` | `1` | Brightness memory using wear-leveling. Set to `0` to disable |
| `STORE_SIZE_BYTES` | `2048` | Reserved Flash memory size (**must be a multiple of 1KB**). 2KB = 1024 records. Larger size increases Flash longevity |
| `STORE_COMMIT_MS` | `5000` | Delay time after level stabilizes before committing to Flash (ms) |

> Lifespan $\approx (\text{STORE\_SIZE\_BYTES} / 2) \times \text{Erase cycles}$. 2KB yields approximately 10 million saves (SPEC.md Section 5).

## EMI Mitigation (PWM)

| Item | Default | Description |
|---|---|---|
| `PWM_SLEW_MHZ` | `2` | PWM output pin slew rate (GPIO speed): 2 / 10 / 30 MHz. Lower speeds soften edges and reduce harmonics (2 MHz recommended for high-current LEDs) |
| `PWM_SPREAD_SPECTRUM` | `0` | Set to `1` to dither PWM period for spread spectrum (brightness remains unaffected) |
| `PWM_SPREAD_RANGE` | `192` | ATRLR sweep range ($\pm\text{counts}$). **Must satisfy `PWM_TOP + RANGE` $\le 65535$ and `RANGE < PWM_TOP`** (ATRLR is 16-bit; violations are caught by compile-time assertions and clamped to $[1, 65535]$ at runtime) |
| `PWM_SPREAD_PERIOD_MS` | `2` | Dither update interval |

## Overheat Failsafe

| Item | Default | Description |
|---|---|---|
| `TEMP_PROTECT_ENABLE` | **`0`** | Thermal protection (cutoff + throttling). **Default OFF** (die estimation omitted to prevent false cutoffs). Enable only when using physical NTC |
| `TEMP_SOURCE` | `TEMP_SOURCE_EXTERNAL` | Temperature source when enabled. **Physical NTC (`EXTERNAL`) is recommended**. `DIE` estimation is not recommended due to potential false cutoffs |
| **[DIE]** `DIE_AMBIENT_C` | `28` | Baseline ambient temperature at zero load ($^\circ\text{C}$) |
| **[DIE]** `DIE_RISE_AT_FULL_C` | `60` | Steady-state temperature rise at 100% duty cycle ($^\circ\text{C}$). *Adjust based on real hardware measurement* |
| **[DIE]** `DIE_TAU_MS` | `30000` | Thermal time constant (ms). Larger values smooth out temperature changes |
| **[EXT]** `TEMP_SENSE_PIN` | `PC4` | Analog sensor input pin. **ADC-capable pins only: `PA2`(ch0) / `PA1`(ch1) / `PC4`(ch2)** (the ADC channel is derived automatically) |
| **[EXT]** `TEMP_CAL_T0_C` | `25` | Calibration reference temperature |
| **[EXT]** `TEMP_CAL_ADC0` | `512` | Raw 10-bit ADC value at $T_{0\text{C}}$ (*Requires calibration*) |
| **[EXT]** `TEMP_CAL_SLOPE_X100` | `-300` | $\text{ADC counts} / ^\circ\text{C} \times 100$ (Signed, non-zero) (*Requires calibration*) |
| `WARN_TEMP_C` | `80` | Cutoff trigger threshold ($^\circ\text{C}$) |
| `WARN_TEMP_HYST_C` | `8` | Recovery temperature margin ($^\circ\text{C}$ drop required to restart; $0 < \text{HYST} < \text{WARN}$) |
| `WARN_TEMP_PERIOD_MS` | `200` | Sampling / update interval |
| `THERMAL_TRIP_N` | `3` | Number of cutoff $\rightarrow$ restart cycles before throttling engages ($n$) |
| `THERMAL_THROTTLE_PCT` | `20` | Output power reduction step during throttling (%) (accumulates every $N$ trips) |
| `THERMAL_THROTTLE_MAX` | `80` | Maximum power reduction limit (%) ($< 100$) |
| `WARN_LED_ENABLE` | `0` | Set to `1` to drive `WARN_LED_PIN` High during overheat conditions |
| `WARN_LED_PIN` | `PC4` | Warning LED pin (any SOP8 GPIO; conflicts with other features are caught at compile time) |

## Watchdog Timer

| Item | Default | Description |
|---|---|---|
| `WDT_ENABLE` | `1` | Enable IWDG. Automatically resets MCU on hang |
| `WDT_TIMEOUT_MS` | `2000` | Reset threshold if watchdog is not refreshed within this duration ($\approx 2\text{ to }8190\text{ ms}$) |

> *Note:* If `DEBUG_LOG=1` and no SWD host is connected, `printf` blocking may trigger unintended Watchdog resets during development.

### External Sensor (EXTERNAL) Calibration Procedure (Linear Approximation)
$$\text{temp} = \text{TEMP\_CAL\_T0\_C} + \frac{(\text{adc} - \text{TEMP\_CAL\_ADC0}) \times 100}{\text{TEMP\_CAL\_SLOPE\_X100}}$$

1. Build and flash with `DEBUG_LOG=1`. (If you need to view raw ADC readings, temporarily add output for `adc` in `temp_update` inside `temp.h`).
2. Record raw ADC value at a known baseline temperature $T_1$ (e.g., room temperature $25^\circ\text{C}$) $\rightarrow$ Assign to `TEMP_CAL_ADC0` and `TEMP_CAL_T0_C`.
3. Record raw ADC value at a second temperature $T_2$ (e.g., $60^\circ\text{C}$ using a heat gun) $\rightarrow$ Calculate slope:
   $$\text{TEMP\_CAL\_SLOPE\_X100} = \frac{(\text{adc}_2 - \text{adc}_1) \times 100}{T_2 - T_1}$$
4. Set `WARN_TEMP_C` to target limit ($80^\circ\text{C}$). Although NTCs are non-linear, a 2-point calibration near the operating limit ($80^\circ\text{C}$) provides sufficient accuracy for over-temperature warnings.
5. Revert `DEBUG_LOG=0` for production release.

## Nightlight

Two nightlight types are selectable with `NIGHTLIGHT_TYPE`:
①`NL_TYPE_WS2812` (color, effect-priority — the existing WS2812/SK6812 driver) and
②`NL_TYPE_SINGLE` (single-color LED on a dedicated pin, blinked `NL_ON_MS` every `NL_PERIOD_S`).
Only **② single LED with `NL_USE_PWM=0`** is eligible for the deep low-power (Standby) mode below.

| Item | Default | Description |
|---|---|---|
| `NIGHTLIGHT_ENABLE` | `1` | Enables nightlight feature |
| `NIGHTLIGHT_TYPE` | `NL_TYPE_WS2812` | ①`NL_TYPE_WS2812` (color/effect) or ②`NL_TYPE_SINGLE` (single-color LED, low-power) |
| **②** `NL_LED_PIN` | `PC4` | Single-LED dedicated pin (any SOP8 GPIO) |
| **②** `NL_PERIOD_S` | `5` | Blink period in **seconds** (`1..60`; `1..30` when deep low-power is on) |
| **②** `NL_ON_MS` | `100` | On-time per blink in ms (must be `< NL_PERIOD_S*1000`) |
| **②** `NL_USE_PWM` | `0` | `0` = GPIO on/off (lowest power, deep-sleep eligible) / `1` = soft-PWM breathing (effect; not deep-sleep) |
| **①** `WS_DIN_PIN` | `PC4` | WS2812 data line GPIO (any SOP8 pin; GPIO port/number derived automatically) |
| `WS_COUNT` | `1` | Number of addressable LEDs |
| `NIGHTLIGHT_PERIOD_MS` | `4000` | Duration for 1 full bright $\rightarrow$ dim breathing cycle in ms (**2 to 60000**). Upper limit provides safety margin against 32-bit SysTick wrap ($\approx 89.5\text{s}$) |
| `NIGHTLIGHT_INTERVAL_MS` | `3000` | Complete OFF delay following breathing cycle in ms (**$\le 60000$**) |
| `NIGHTLIGHT_REFRESH_MS` | `30` | Refresh rate for data transmission (smoothness) |
| `NIGHTLIGHT_BOOT_TEST_MS` | `1500` | Illuminates WS LED with configured color briefly at startup (for wiring diagnostics; `0` = disabled) |
| `WS_ORDER` | `WS_ORDER_RGBW` | Chip color byte order: `WS_ORDER_GRB`, `RGB`, `GRBW`, or `RGBW` (default matches the bundled SK6812 RGBW) |
| `WS_MAX_COLOR` | `0x40300810` | Maximum color intensity. RGB = **`0xRRGGBB` (6 hex digits)** / RGBW = **`0xRRGGBBWW` (8 hex digits)** |

### Color Order & RGBW Configuration Examples
- Standard WS2812 (GRB): `#define WS_ORDER WS_ORDER_GRB` / `#define WS_MAX_COLOR 0x403008`
- RGB-ordered variants: `#define WS_ORDER WS_ORDER_RGB`
- **SK6812 RGBW**: `#define WS_ORDER WS_ORDER_GRBW` / `#define WS_MAX_COLOR 0x40300810` ($R=0\text{x}40, G=0\text{x}30, B=0\text{x}08, W=0\text{x}10$)
- *Note:* The hex length of `WS_MAX_COLOR` must strictly match the selected `WS_ORDER` (with or without White channel).

## Feature ↔ Pin Assignment (config.h only, SOP8 / J4M6)

Assign each feature with its single pin macro in `config.h`. `source/pins.h` validates every
assignment at compile time. SOP8 pin capabilities:

| Pin | GPIO | ADC ch | PWM route (positive output) | Default use |
|-----|---|---|---|---|
| `PA1` | GPIOA/1 | ch1 | TIM1_CH2 | ENC_A |
| `PA2` | GPIOA/2 | ch0 | — (CH2N complementary only) | ENC_SW |
| `PC1` | GPIOC/1 | — | TIM2_CH4 | ENC_B |
| `PC2` | GPIOC/2 | — | **TIM2_CH2** ★default PWM | PWM |
| `PC4` | GPIOC/4 | ch2 | TIM1_CH4 | Nightlight / Temp / Warn LED |
| `PD1` | GPIOD/1 | — | — | **SWIO (flash/printf reserved)** |

Rules enforced at compile time (and mirrored in the GUI config editor):
- **`PWM_PIN`** must be a PWM-capable pin (`PC2`/`PC1`/`PA1`/`PC4`). `PC2` is hardware-verified; others are compile-supported only.
- **`TEMP_SENSE_PIN`** (external temp) must be ADC-capable (`PA2`/`PA1`/`PC4`); the ADC channel is derived automatically.
- **No two enabled features may share a pin** (conflict → `_Static_assert` error). This subsumes the old "PC4 mutual exclusion" of Nightlight / External Sensor / Warning LED.
- Assigning **`PD1`** to a feature emits a `#warning` (it collides with SWIO flashing/`debugprintf`).

*Note:* Software-only features (die-estimated temperature, thermal cutoff/throttling, watchdog, EMI spread spectrum) **need no GPIO pin**. To run more pin-bound features simultaneously than SOP8 allows, switch to a larger package such as TSSOP20 / QFN (CH32V003F4P6) — that package's pin set is out of scope for this table.

## Deep Low-Power Mode (Standby + AWU) — experimental, hardware-unverified

For battery use, `LOW_POWER_MODE=1` puts the MCU into Standby between single-LED nightlight blinks
and wakes periodically via AWU; a push-switch (EXTI) wakes it to normal dimmer operation for a while.
Design rationale and the LED-driver discussion are in [POWER_AND_DRIVER.md](POWER_AND_DRIVER.md).

| Item | Default | Description |
|---|---|---|
| `LOW_POWER_MODE` | `0` | `1` = deep-sleep nightlight. **Requires** `NIGHTLIGHT_TYPE=NL_TYPE_SINGLE`, `NL_USE_PWM=0`, `NL_PERIOD_S≤30`, `WDT_ENABLE=0` (enforced at compile time and in the GUI) |
| `LOWPWR_ACTIVE_WINDOW_S` | `30` | Seconds of normal operation kept after a push-switch wake before returning to sleep |

- **Reflash safety**: hold the push-switch while powering on → the device stays in normal mode (does not sleep), so SWD can attach for flashing.
- **`LOW_POWER_MODE=0` (default) is byte-identical to the previous firmware.** The Standby/AWU/EXTI path is experimental and **must be verified on hardware** (Standby wake behavior, AWU period, actual current).

## Battery Operation (supplementary — design estimates)

LightBox is primarily designed for **continuous power**; battery use is feasible for a low-duty
nightlight. The figures below are **design estimates** (confirm on hardware):

- **Nightlight LED**: a green LED via a **~1 kΩ** series resistor at 3 V ≈ **0.9 mA** (clearly
  visible for a nightlight). A ~2 mA option (510 Ω) is brighter but roughly **halves** battery life;
  1 kΩ is a good brightness/life balance.
- **Duty**: e.g. 100 ms on every 5 s.
- **`PWM_ON_TIME_S` (shipped)**: the auto-off timer lowers average on-time and thus battery drain,
  independent of any sleep mode — the concrete lever available today.
- **Deep low-power (`LOW_POWER_MODE`, experimental — now implemented)**: Standby + AWU periodic
  wake, push-switch (EXTI) wake, encoder pull-ups released to analog-input during sleep. For
  1 kΩ / 100 ms-per-5 s, a single **CR2032 (~220 mAh)** is estimated at **~3–4 months as implemented**
  (the MCU sleeps at 48 MHz during the on-time). Lowering the clock during the on-time (future)
  would extend this toward ~6.5 months. **Without** deep low-power (MCU at 48 MHz always) a coin
  cell lasts only ~a day. The GUI config editor shows this CR2032 estimate live (1 kΩ assumption).
- **Cell choice**: 2×CR2032 in *series* raises voltage (6 V) but **not capacity**, and 6 V exceeds
  the CH32V003 5.5 V maximum (needs regulation). For longer life prefer *parallel* cells (~440 mAh)
  or a larger cell (CR2450 ~600 mAh ≈ ~2 years est.). Add a 10–100 µF buffer cap to handle CR2032
  pulse load / internal resistance.

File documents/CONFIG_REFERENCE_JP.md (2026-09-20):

# LightBox 設定リファレンスガイド (config.h)

[English](CONFIG_REFERENCE.md) · **日本語** · [← README](../README_JP.md)

`source/config.h` の全項目リファレンス。値を変えたら再ビルド（[README](../README_JP.md) 参照）。
ピンは ch32fun のピン名（`PA1`, `PC2`, `PD0` …）。

## ピン割当（1機能=1ピンマクロ）

各機能は**単一のピンマクロ**で割当てる。`source/pins.h` が GPIOポート/番号・ADCチャネル・
PWMのタイマ/チャネル/remap を自動導出し、能力違反（PWM/ADC不可ピン）とピン衝突（2機能が
同一ピン）を**コンパイル時**に `_Static_assert` で弾く。SOP8(J4M6)実在ピン: `PA1 PA2 PC1 PC2 PC4 PD1(SWIO)`。

| 項目 | 既定 | 説明 |
|---|---|---|
| `PWM_PIN` | `PC2` | 本体LED PWM出力。PWM可能ピンのみ: `PC2`(TIM2_CH2)/`PC1`(TIM2_CH4)/`PA1`(TIM1_CH2)/`PC4`(TIM1_CH4)。**PC2=実機検証済の既定。他はコンパイル対応・実機未検証** |
| `ENC_A_PIN` | `PA1` | エンコーダ A 相（内部プルアップ） |
| `ENC_B_PIN` | `PC1` | エンコーダ B 相（内部プルアップ） |
| `ENC_SW_PIN` | `PA2` | 押しSW（内部プルアップ, 押下=Low） |

## PWM（16bit TIM2）

| 項目 | 既定 | 説明 |
|---|---|---|
| `PWM_TOP` | `4095` | 分解能-1。周波数=`48MHz/(TOP+1)/(PSC+1)`。最大 65535。上げると滑らか/低周波 |
| `PWM_PSC` | `0` | プリスケーラ |

## 調光段

| 項目 | 既定 | 説明 |
|---|---|---|
| `LEVELS` | `64` | 段数（0=消灯〜LEVELS=最大） |
| `LEVEL_INIT` | `32` | ストア無効時の起動レベル（`STORE_ENABLE=0` のときのみ有効） |

> 調光カーブ（CIE L*）は固定・パラメータ無し（知覚均等になるよう定義された曲線そのもの）。

## エンコーダ / チャタリング

| 項目 | 既定 | 説明 |
|---|---|---|
| `ENC_REVERSE` | `0` | 1 で CW/CCW 反転（品種・配線差を吸収） |
| `ENC_HALF_STEP` | `0` | 0=フルステップ(4遷移で1段) / 1=ハーフステップ(2遷移で1段) |
| `ENC_ACCEL_ENABLE` | `1` | 加速: 速く回すとステップ倍化 |
| `ENC_ACCEL_FACTOR` | `3` | 速回し時の1クリックのステップ倍率（=3倍） |
| `ENC_ACCEL_WINDOW_MS` | `50` | 前クリックからこの時間未満(同方向)なら加速 |
| `ENC_REVERSAL_LOCK_MS` | `5` | この時間内の「逆方向」ステップはバウンス扱いで無視。速い操作で取りこぼすなら短く、チャタが残るなら長く |
| `SW_DEBOUNCE_MS` | `20` | 押しSW 安定確定時間 |

## 高速回しスナップ

| 項目 | 既定 | 説明 |
|---|---|---|
| `SNAP_WINDOW_MS` | `500` | 判定の窓（n ms） |
| `SNAP_CLICKS` | `6` | 窓内で発火する同方向クリック数（j, 2以上） |

## 動作オプション

| 項目 | 既定 | 説明 |
|---|---|---|
| `WAKE_ON_TURN` | `1` | 消灯中に回したら自動点灯（結果 level>0 のときのみ。level=0のまま暗方向は消灯維持）。0 で点灯は押しSWのみ |
| `PWM_ON_TIME_S` | `0` | **自動消灯タイマ(秒)**: 点灯からこの秒数で本体出力を自動消灯(ソフトオフ)。`0`=無効(点けっぱなし)。エンコーダ/押しSW 操作でカウントはリセット(延長)。平均点灯時間↓＝バッテリ節約＋常時電源でも自動消灯の付加価値 |
| `SOFT_START_ON` | `800` | 点灯フェードイン時間(ms)。0=即時、最大65535(≒65.5s)。CIE基準で均等 |
| `SOFT_START_OFF` | `600` | 消灯フェードアウト時間(ms)。0=即時、最大65535 |
| `DEBUG_LOG` | `0` | 1 で SWD printf（開発時のみ）。**通常運用は0厳守**（ブロッキングで取りこぼし要因） |

## 明るさ不揮発ストア

| 項目 | 既定 | 説明 |
|---|---|---|
| `STORE_ENABLE` | `1` | 明るさ記憶（ウェアレベリング）。0 で無効 |
| `STORE_SIZE_BYTES` | `2048` | 予約する恒久フラッシュ量（**1KBの倍数**）。2KB=1024レコード。増やすと寿命↑ |
| `STORE_COMMIT_MS` | `5000` | 値が落ち着いてから保存するまでの待ち（n 秒） |

> 寿命 ≈ (STORE_SIZE_BYTES/2) × 消去寿命。2KBで約1000万回（SPEC.md 5章）。

## EMI 対策（PWM）

| 項目 | 既定 | 説明 |
|---|---|---|
| `PWM_SLEW_MHZ` | `2` | PWM出力ピンのスルーレート(GPIO速度) 2/10/30。低いほどエッジが鈍り高調波↓（大電流LEDは2推奨） |
| `PWM_SPREAD_SPECTRUM` | `0` | 1 で周期を微小ディザしスペクトラム拡散（明るさ不変） |
| `PWM_SPREAD_RANGE` | `192` | ATRLR の振り幅(±カウント)。**`PWM_TOP+RANGE≤65535` かつ `RANGE<PWM_TOP`** 必須（ATRLRは16bit。違反はコンパイル時アサートで検出、実行時も[1,65535]にクランプ） |
| `PWM_SPREAD_PERIOD_MS` | `2` | ディザ更新間隔 |

## 過熱フェイルセーフ

| 項目 | 既定 | 説明 |
|---|---|---|
| `TEMP_PROTECT_ENABLE` | **`0`** | 過熱保護（遮断＋スロットル）。**既定OFF**（ダイ推定は誤遮断のため不採用）。実測NTCで守る時のみ1 |
| `TEMP_SOURCE` | `TEMP_SOURCE_EXTERNAL` | 有効化時の温度源。**実測NTC(EXTERNAL)推奨**。DIE(推定)は誤遮断のため非推奨 |
| **[DIE]** `DIE_AMBIENT_C` | `28` | 無負荷時の基準温度(℃) |
| **[DIE]** `DIE_RISE_AT_FULL_C` | `60` | duty100%連続時の定常上昇(℃) ※目安, 実機の発熱に合わせ調整 |
| **[DIE]** `DIE_TAU_MS` | `30000` | 熱時定数(ms)。大きいほどゆっくり上下 |
| **[EXT]** `TEMP_SENSE_PIN` | `PC4` | アナログセンサ入力ピン。**ADC対応ピンのみ: `PA2`(ch0)/`PA1`(ch1)/`PC4`(ch2)**（ADCチャネルは自動導出） |
| **[EXT]** `TEMP_CAL_T0_C` | `25` | 校正基準温度 |
| **[EXT]** `TEMP_CAL_ADC0` | `512` | T0_C 時の生ADC（10bit）※要校正 |
| **[EXT]** `TEMP_CAL_SLOPE_X100` | `-300` | ADCカウント/℃ ×100（符号付, 0不可）※要校正 |
| `WARN_TEMP_C` | `80` | 遮断オン閾値(℃) |
| `WARN_TEMP_HYST_C` | `8` | この分下がると再開（0<HYST<WARN） |
| `WARN_TEMP_PERIOD_MS` | `200` | サンプリング/更新周期 |
| `THERMAL_TRIP_N` | `3` | 遮断→再開をこの回数繰り返したらスロットル発動(n) |
| `THERMAL_THROTTLE_PCT` | `20` | スロットル時の出力ダウン量(%)(j, N回ごと累積) |
| `THERMAL_THROTTLE_MAX` | `80` | ダウンの上限(%)（<100） |
| `WARN_LED_ENABLE` | `0` | 1 で過熱中に `WARN_LED_PIN` を High |
| `WARN_LED_PIN` | `PC4` | 警告灯ピン（任意のSOP8 GPIO。他機能との衝突はコンパイル時に検出） |

## ウォッチドッグ

| 項目 | 既定 | 説明 |
|---|---|---|
| `WDT_ENABLE` | `1` | IWDG 有効。ハング時に自動リセット |
| `WDT_TIMEOUT_MS` | `2000` | この時間リフレッシュ無しでリセット（約2〜8190ms） |

> ※`DEBUG_LOG=1` かつ SWD ホスト未接続だと printf 停滞で WDT リセットしうる（開発時の注意）。

### 外付けセンサ(EXTERNAL)の校正手順（近似1次）
`temp = TEMP_CAL_T0_C + (adc - TEMP_CAL_ADC0)*100 / TEMP_CAL_SLOPE_X100`
1. `DEBUG_LOG=1` でビルド・書込。`temp=..C` と一緒に…（生ADCを見たい場合は temp.h の
   `temp_update` で `adc` も出力するよう一時追記）。
2. 既知温度T1（例 室温25℃）で生ADCを記録 → `TEMP_CAL_ADC0`, `TEMP_CAL_T0_C` に。
3. 別温度T2（例 ドライヤ等で60℃）で生ADCを記録 → 傾き
   `TEMP_CAL_SLOPE_X100 = (adc2 - adc1)*100 / (T2 - T1)`。
4. `WARN_TEMP_C` を目標(80℃)に。NTCは非線形だが、動作点(80℃)付近で2点校正すれば警告用途に十分。
5. `DEBUG_LOG=0` に戻して本運用。

## 常夜灯

`NIGHTLIGHT_TYPE` で2種から選択: ①`NL_TYPE_WS2812`(カラー・演出優先=従来WS2812/SK6812) と
②`NL_TYPE_SINGLE`(専用ピンの単色LEDを `NL_PERIOD_S` 秒おきに `NL_ON_MS` 点灯)。
**②単色LED＋`NL_USE_PWM=0` のときだけ**下記の深い低電力(Standby)対象。

| 項目 | 既定 | 説明 |
|---|---|---|
| `NIGHTLIGHT_ENABLE` | `1` | 常夜灯機能 |
| `NIGHTLIGHT_TYPE` | `NL_TYPE_WS2812` | ①`NL_TYPE_WS2812`(カラー/演出) or ②`NL_TYPE_SINGLE`(単色LED/低電力) |
| **②** `NL_LED_PIN` | `PC4` | 単色LED専用ピン(任意SOP8 GPIO) |
| **②** `NL_PERIOD_S` | `5` | 点灯周期**秒**(`1..60`。深い低電力時 `1..30`) |
| **②** `NL_ON_MS` | `100` | 1回の点灯時間ms(`< NL_PERIOD_S*1000`) |
| **②** `NL_USE_PWM` | `0` | `0`=GPIO ON/OFF(最小電力/deep sleep可) / `1`=ソフトPWM明滅(演出/不可) |
| **①** `WS_DIN_PIN` | `PC4` | WS2812 データ線GPIO（任意のSOP8ピン。port/番号は自動導出） |
| `WS_COUNT` | `1` | LED 個数 |
| `NIGHTLIGHT_PERIOD_MS` | `4000` | n: 明→暗 1往復(ms, **2〜60000**)。上限は32bit SysTick(~89.5s)ラップ回避の安全マージン |
| `NIGHTLIGHT_INTERVAL_MS` | `3000` | i: 周期後の完全オフ(ms, **≤60000**) |
| `NIGHTLIGHT_REFRESH_MS` | `30` | 送信リフレッシュ間隔（滑らかさ） |
| `NIGHTLIGHT_BOOT_TEST_MS` | `1500` | 起動直後にWS LEDを設定色で点灯（配線/切り分け用, 0=無効） |
| `WS_ORDER` | `WS_ORDER_RGBW` | チップのバイト並び。`WS_ORDER_GRB/RGB/GRBW/RGBW`（既定は同梱SK6812 RGBWに一致） |
| `WS_MAX_COLOR` | `0x40300810` | 最大色。RGB系=**0xRRGGBB(6桁)** / RGBW系=**0xRRGGBBWW(8桁)** |

### 色順・RGBW の設定例
- 一般的 WS2812（GRB）: `#define WS_ORDER WS_ORDER_GRB` / `#define WS_MAX_COLOR 0x403008`
- RGB 順の製品: `#define WS_ORDER WS_ORDER_RGB`
- **SK6812 RGBW**: `#define WS_ORDER WS_ORDER_GRBW` / `#define WS_MAX_COLOR 0x40300810`
  （R=0x40 G=0x30 B=0x08 W=0x10）
- ※`WS_MAX_COLOR` の桁数は `WS_ORDER`（W有無）に必ず合わせること。

## 機能↔ピン割当（config.h のみ, SOP8 / J4M6）

各機能を config.h の単一ピンマクロで割当てる。`source/pins.h` が全割当をコンパイル時に検証する。
SOP8 のピン能力:

| ピン | GPIO | ADC ch | PWM経路(正出力) | 既定用途 |
|---|---|---|---|---|
| `PA1` | GPIOA/1 | ch1 | TIM1_CH2 | ENC_A |
| `PA2` | GPIOA/2 | ch0 | —（CH2N相補のみ） | ENC_SW |
| `PC1` | GPIOC/1 | — | TIM2_CH4 | ENC_B |
| `PC2` | GPIOC/2 | — | **TIM2_CH2** ★既定PWM | PWM |
| `PC4` | GPIOC/4 | ch2 | TIM1_CH4 | 常夜灯 / 温度 / 警告灯 |
| `PD1` | GPIOD/1 | — | — | **SWIO（書込/printf 予約）** |

コンパイル時に強制されるルール（GUI 設定エディタでも同様に検証）:
- **`PWM_PIN`** は PWM可能ピン（`PC2`/`PC1`/`PA1`/`PC4`）のみ。`PC2` は実機検証済、他はコンパイル対応のみ。
- **`TEMP_SENSE_PIN`**（外付け温度）は ADC対応ピン（`PA2`/`PA1`/`PC4`）のみ。ADCチャネルは自動導出。
- **有効な2機能が同一ピンを共有できない**（衝突→`_Static_assert` エラー）。従来の「PC4 排他（常夜灯/外付けセンサ/警告灯）」はこれに包含。
- **`PD1`** を機能に割当てると `#warning`（SWIO 書込/`debugprintf` と競合）。

※ソフトのみの機能（ダイ推定温度・過熱遮断/スロットル・ウォッチドッグ・EMIスペクトラム拡散）は**ピン不要**。
SOP8 で足りないほど多機能を同時に使う場合は TSSOP20/QFN(F4P6) 等へ（そのピン集合は本表の対象外）。

## 深い低電力モード (Standby + AWU) ★実験的・実機未検証

バッテリ向け。`LOW_POWER_MODE=1` で、単色LED常夜灯の点灯間は MCU を Standby にして AWU で周期起床。
押しSW(EXTI)を押すと一定時間 通常ディマーとして動作する。
設計根拠と LED ドライバの検討は [POWER_AND_DRIVER_JP.md](POWER_AND_DRIVER_JP.md)。

| 項目 | 既定 | 説明 |
|---|---|---|
| `LOW_POWER_MODE` | `0` | `1`=deep sleep 常夜灯。**要件**: `NIGHTLIGHT_TYPE=NL_TYPE_SINGLE`, `NL_USE_PWM=0`, `NL_PERIOD_S≤30`, `WDT_ENABLE=0`(コンパイル時＆GUIで強制) |
| `LOWPWR_ACTIVE_WINDOW_S` | `30` | 押しSW起水後に通常動作を維持する秒数 |

- **再書込みセーフティ**: 起動時に押しSWを押していれば通常モードに留まりスリープしない(SWD 接続可)。
- **`LOW_POWER_MODE=0`(既定)は従来ファームと byte 同一。** Standby/AWU/EXTI 経路は実験的で、
  実機での確認（Standby 復帰・AWU 周期・実消費）が必須。

## バッテリ駆動（補足・設計見積り）

LightBox は基本 **常時電源**向けだが、低デューティの常夜灯ならバッテリ駆動も可能。以下は
**設計上の見積り**（実機で要確認）:

- **常夜灯LED**: 緑LEDを **~1kΩ** 直列・3V で ≈ **0.9mA**（常夜灯として十分視認可）。
  ~2mA(510Ω)は明るいが電池寿命はおよそ**半分**。**1kΩ が明るさ/寿命のバランス良好**。
- **デューティ**: 例）5秒おきに 100ms 点灯。
- **`PWM_ON_TIME_S`（実装済）**: 自動消灯タイマは平均点灯時間を下げて消費を削減。スリープ実装の
  有無に関わらず効く「今すぐ使えるレバー」。
- **深い低電力（`LOW_POWER_MODE`・実験的=実装済）**: Standby＋AWU 周期起床、押しSW(EXTI)起水、
  スリープ中はエンコーダのプルアップをアナログ入力化してリーク停止。1kΩ・100ms/5s で単セル
  **CR2032(~220mAh)** は **実装形では約3〜4ヶ月**（点灯中は 48MHz のまま Sleep）。点灯中にクロックを
  落とせば(将来)~6.5ヶ月方向へ延伸。**深い低電力なし(48MHz常時)では約1日**しかもたない。
  GUI 設定エディタはこの CR2032 目安を 1kΩ 前提でライブ表示する。
- **セル選択**: CR2032×2 の*直列*は電圧(6V)は上がるが**容量は増えず**、6V は CH32V003 の 5.5V 上限
  超過（要降圧）。寿命重視なら*並列*(~440mAh)か大容量セル（CR2450 ~600mAh ≈ 約2年見積り）。
  CR2032 のパルス負荷/内部抵抗対策に 10–100µF のバッファコンデンサ推奨。

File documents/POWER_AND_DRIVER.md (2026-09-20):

# LightBox — Power, Low-Power & LED-Driver Design Notes

**English** · [日本語](POWER_AND_DRIVER_JP.md) · [← README](../README.md)

Design record for the battery / low-power features, the nightlight variants, and the main-LED
driver selection. This complements [CONFIG_REFERENCE.md](CONFIG_REFERENCE.md) (per-setting
reference) and [DESIGN.md](DESIGN.md) (core firmware rationale). Parts marked **★experimental**
are compile-supported but **not yet hardware-verified**.

---

## 1. Feature ↔ Pin assignment (why it is config-driven)

Motivation is PCB simplification on the SOP8 (J4M6) package, whose datasheet pinout clusters
power on pins 2/4 (VSS/VDD) and GPIO on pins 5–8:

- Grouping the rotary encoder + push switch on **PC1/PC2/PC4** (pins 5–7) keeps the 5-terminal
  encoder connector on one side → simpler routing.
- Putting the output(s) on **PA1/PA2** (pins 1/3, next to power) collects the LED/output section
  near VDD/VSS → the other clean zone.

CH32V003 constrains which pins can do PWM (timer channel/remap) and ADC, so `source/pins.h`
models each SOP8 pin's capability, derives GPIO/ADC/timer info from a single pin macro, and
rejects capability violations and pin conflicts at compile time. Full table and rules are in
[CONFIG_REFERENCE.md](CONFIG_REFERENCE.md) ("Feature ↔ Pin Assignment"). Note: `PWM_PIN=PA1`
(TIM1_CH2) + `WS_DIN_PIN`/nightlight on PA2 + encoder on PC1/PC2/PC4 is fully expressible.

## 2. Auto-off timer (`PWM_ON_TIME_S`)

Turns the main output off (soft fade) N seconds after it was switched on; `0` = disabled.
Any encoder/switch activity resets the countdown. It lowers average on-time (battery) and adds a
"forgot to turn it off" convenience on continuous power. Counted in 1-second steps so it is
independent of the ~89 s SysTick wrap.

## 3. Nightlight variants (`NIGHTLIGHT_TYPE`)

- **① WS2812/SK6812** (`NL_TYPE_WS2812`) — color, effect-priority (existing driver). Not eligible
  for deep sleep (needs tight CPU timing / higher voltage than a coin cell provides).
- **② Single-color LED** (`NL_TYPE_SINGLE`) — a dedicated pin blinks `NL_ON_MS` every
  `NL_PERIOD_S`. `NL_USE_PWM=0` = plain GPIO on/off (lowest CPU/power) or `=1` = soft-PWM
  breathing (effect). **Only ② + `NL_USE_PWM=0`** is eligible for the deep low-power mode.

Nightlight current is set by a **series resistor** (not a driver IC); at 5 V a white LED via ~1 kΩ
≈ 1.8 mA, plenty for a nightlight and current-stable thanks to the headroom.

## 4. Deep low-power mode (Standby + AWU) — ★experimental

Battery mode (`LOW_POWER_MODE=1`, `source/lowpower.h`). Design decisions:

- **Only for the low-power nightlight config**: requires ② single-LED + `NL_USE_PWM=0` +
  `NL_PERIOD_S≤30` + `WDT_ENABLE=0` (enforced by `_Static_assert`). WS2812 / PWM effect keep the
  normal always-on architecture (effect-priority).
- **Sleep structure**: LED on for `NL_ON_MS` in **Sleep** (GPIO holds), then **Standby** (deepest,
  ~µA) for the rest of the period. Both intervals are timed by **AWU (LSI ≈128 kHz, clock-independent)**;
  a push-switch on **EXTI** also wakes it. AWU one-cycle max ≈ 30 s → `NL_PERIOD_S≤30`.
- **Wake model**: the **push switch** wakes the device into normal dimmer operation for
  `LOWPWR_ACTIVE_WINDOW_S`; after that, with the main light off, it returns to sleep. The **rotary
  encoder is deliberately NOT a Standby wake source** (two-phase EXTI is complex and leaves
  pull-ups leaking).
- **Leakage**: before sleeping, encoder A/B are switched to **analog-input** so their pull-ups stop
  leaking (a closed contact through a ~30–50 kΩ pull-up would draw ~100 µA — larger than Standby).
  The push switch keeps a pull-up (normally open → ~0 idle leak, low on press = wake).
- **Reflash safety**: hold the push switch while powering on → the device stays in normal mode and
  never sleeps, so SWD can attach for flashing. This also doubles as reset-tolerance: whether
  Standby wake resets or resumes, `main` re-deriving state (or the resume loop) reaches the same
  decision from the button state.
- **Watchdog**: `WDT_ENABLE=0` is required — IWDG runs on LSI and could reset during Standby
  before the AWU fires.

**Status**: the Standby/AWU/EXTI path is compile-supported but **must be verified on hardware**
(Standby wake behavior, AWU period accuracy, actual currents). `LOW_POWER_MODE=0` (default) is
byte-identical to the previous firmware.

## 5. Battery-life estimates

Model (documented assumptions, ★confirm on hardware): green LED via **1 kΩ** at 3 V ≈ **0.9 mA**;
Standby ≈ 10 µA; active @48 MHz ≈ 8 mA; on-time Sleep @48 MHz ≈ 3 mA; wake overhead ≈ 5 ms;
CR2032 ≈ 220 mAh. Average current dominated by **"how the MCU spends the on-time"**, not the LED.

Coin-cell (3 V) nightlight, 100 ms every 5 s:

| Config | Avg current | CR2032 life (est.) |
|---|---|---|
| Deep low-power (as implemented, Sleep @48 MHz during on-time) | ~90 µA | **~3–4 months** |
| Deep + lowering the clock during on-time (future optimization) | ~45 µA | ~6.5 months |
| No deep low-power (MCU 48 MHz always) | ~8 mA | ~1 day |

- **Resistor bias vs brightness/life**: 510 Ω (~1.8 mA) is bright but roughly halves life; **1 kΩ
  (~0.9 mA) is the brightness/life sweet spot**; beyond ~1–2 kΩ, life approaches the MCU+Standby
  floor, so extend by shortening on-time / lowering clock rather than dimming further.
- **Cell choice**: 2×CR2032 in **series** doubles voltage (6 V) but **not capacity**, and 6 V
  exceeds the CH32V003 5.5 V max (needs regulation, which wastes the extra energy in an LDO) —
  it improves LED-current stability, not mAh life. For life prefer **parallel** cells (~440 mAh)
  or a larger cell (CR2450 ~600 mAh ≈ ~2 years). Add a 10–100 µF buffer cap for CR2032 pulse/IR.

The GUI config editor shows this CR2032 estimate live for the single-LED nightlight (1 kΩ assumption).

## 6. Main-LED driver selection

**Confirmed operating conditions:** 5 V single supply · white-ish main LED · nightlight current set
by a resistor · main PWM limited to **≤2 kHz** (so it can dim a CN5711 via its CE pin).

### CN5711 (Consonance) — chosen candidate
Linear constant-current LED driver: Vin 2.8–6 V, up to **1.5 A**, low dropout **0.37 V @1.5 A**,
±5 %, on-chip MOSFET + sense, current set by **ISET resistor** (≤30 kΩ), **temperature regulation
(foldback)**, SOP8. **PWM dimming via the CE pin at <2 kHz.** Using it replaces the discrete
MOSFET (FDS5680) gate drive: LED anode→5 V, cathode→CN5711 LED pin, CE←MCU PWM.

**Key caveat — it is LINEAR:** it dissipates `(Vin − Vf) × I` in the IC. At 5 V into a ~3.2 V white
LED the drop is ~1.8 V:

| Main LED current | CN5711 dissipation | SOP8 (with thermal pad) |
|---|---|---|
| 100 mA | ~0.18 W | fine |
| 300 mA | ~0.54 W | OK (wide copper) |
| 500 mA | ~0.9 W | marginal |
| **1 A** | **~1.8 W** | too much → thermal foldback (self-dims) |

The current MOSFET+resistor design was "virtually no heat" because the `(Vin−Vf)` loss sat in the
external current-limit element / the LED ran modestly; a linear driver **relocates that loss into
the small SOP8**. So at ~1 A white/5 V, CN5711 will fold back.

### Alternatives
- **AMC7135** — cheaper linear CC, fixed 350 mA (parallel N for more), whole-chip PWM. Cheapest, but
  fixed granularity and more heat.
- **PT4115 / AL8860 / MT7202** — **buck** CC with a DIM pin (PWM, incl. >2 kHz). Efficient when
  Vin≫Vf or for battery, and no `(Vin−Vf)` heat; costs an inductor + Schottky (more BOM/area).

### Decision guide (by main-LED current, 5 V, white)
- **≤ ~300–400 mA → CN5711** is the sweet spot: simple, low dropout, few parts, built-in thermal
  foldback (which also lightens the MCU's own thermal-protection burden).
- **~1 A → prefer a buck driver (PT4115 etc.)** or reduce the LED current, or keep the MOSFET+CC.

### Firmware implication of ≤2 kHz CE dimming
Set the main PWM to ≤2 kHz, e.g. `PWM_TOP=23999, PWM_PSC=0` → 48 MHz/24000 = **2 kHz** (24000-step
resolution, no visible flicker). Alternatively keep the fast MOSFET PWM and don't add a CC IC.

**Sources (CN5711):**
[LCSC C35634](https://www.lcsc.com/product-detail/C35634.html) ·
[datasheetbank preview](https://www.datasheetbank.com/en/preview/CN5711-CONSONANCE) ·
[alldatasheet](https://www.alldatasheet.com/datasheet-pdf/pdf/1133252/CONSONANCE/CN5711.html)

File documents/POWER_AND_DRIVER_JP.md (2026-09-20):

# LightBox — 電力・低電力・LEDドライバ 設計メモ

[English](POWER_AND_DRIVER.md) · **日本語** · [← README](../README_JP.md)

バッテリ/低電力機能・常夜灯の種類・本体LEDドライバ選定に関する設計記録。
項目別リファレンスは [CONFIG_REFERENCE_JP.md](CONFIG_REFERENCE_JP.md)、コア設計判断は
[DESIGN_JP.md](DESIGN_JP.md) を参照。**★実験的**はコンパイル対応だが**実機未検証**。

---

## 1. 機能↔ピン割当（config 主導にした理由）

動機は SOP8(J4M6) の PCB 簡素化。データシートのピン配置は電源が pin2/4(VSS/VDD)、GPIO が pin5–8 に集中:

- ロータリエンコーダ＋押しSW を **PC1/PC2/PC4**(pin5–7) に集約 → 5端子のエンコーダ部品を片側にまとめられ配線が素直。
- 出力を **PA1/PA2**(pin1/3, 電源近傍) に置く → LED/出力部を VDD/VSS 側の別ゾーンにまとめられる。

CH32V003 は PWM(タイマ channel/remap) と ADC の可否がピンで縛られるため、`source/pins.h` が
各 SOP8 ピンの能力をモデル化し、単一ピンマクロから GPIO/ADC/タイマ情報を導出、能力違反とピン衝突を
コンパイル時に弾く。表と規則は [CONFIG_REFERENCE_JP.md](CONFIG_REFERENCE_JP.md) の「機能↔ピン割当」。
`PWM_PIN=PA1`(TIM1_CH2)＋常夜灯を PA2＋エンコーダを PC1/PC2/PC4、という配置も表現可能。

## 2. 自動消灯タイマ（`PWM_ON_TIME_S`）

点灯から N 秒で本体をソフト消灯（`0`=無効）。エンコーダ/押しSW 操作でリセット(延長)。平均点灯時間を
下げてバッテリに効き、常時電源でも「切り忘れ防止」の付加価値。1秒刻みで数えるので SysTick(~89s)ラップ非依存。

## 3. 常夜灯の種類（`NIGHTLIGHT_TYPE`）

- **① WS2812/SK6812**（`NL_TYPE_WS2812`）— カラー・演出優先(従来)。deep sleep 非対象
  (CPUタイミングがシビア／コイン電池では電圧不足)。
- **② 単色LED**（`NL_TYPE_SINGLE`）— 専用ピンを `NL_PERIOD_S` 秒おきに `NL_ON_MS` 点灯。
  `NL_USE_PWM=0`=GPIO 単純ON/OFF(最小CPU/電力) / `=1`=ソフトPWM明滅(演出)。
  **②＋`NL_USE_PWM=0` のときだけ**深い低電力の対象。

常夜灯電流は**直列抵抗**で設定(ドライバIC不使用)。5V で白色LEDを ~1kΩ なら ≈1.8mA、常夜灯に十分かつ
頭上余裕で電流安定。

## 4. 深い低電力モード（Standby + AWU）★実験的

バッテリモード(`LOW_POWER_MODE=1`, `source/lowpower.h`)。設計判断:

- **低電力常夜灯構成のみ対象**: ②単色LED＋`NL_USE_PWM=0`＋`NL_PERIOD_S≤30`＋`WDT_ENABLE=0` を要求
  (`_Static_assert`)。WS2812/PWM演出は従来の常時稼働アーキ(演出優先)。
- **スリープ構造**: 点灯 `NL_ON_MS` は **Sleep**(GPIO保持) で行い、残り時間は **Standby**(最深・µA級)。
  両区間とも **AWU(LSI≈128kHz, クロック非依存)** で計時。押しSW を **EXTI** 起水源にも設定。
  AWU 1サイクル上限 ≈30s → `NL_PERIOD_S≤30`。
- **起水モデル**: **押しSW** で通常ディマー動作に復帰し `LOWPWR_ACTIVE_WINDOW_S` 維持、その後 本体消灯なら
  スリープへ戻る。**ロータリエンコーダは意図的に Standby 起水源にしない**(2相 EXTI は複雑・プルアップが漏れる)。
- **リーク対策**: スリープ前にエンコーダ A/B を**アナログ入力化**しプルアップのリークを停止
  (~30–50kΩ プルアップに接点が閉だと ~100µA 流れ、Standby より大きい)。押しSW はプルアップ温存
  (常開=待機リークほぼ0、押下=Low で起水)。
- **再書込みセーフティ**: 起動時に押しSWを押していれば通常モードに留まりスリープしない(SWD 接続可)。
  これはリセット耐性も兼ねる: Standby 復帰が reset/resume どちらでも、`main` 再実行(または resume ループ)が
  ボタン状態から同じ判断に至る。
- **ウォッチドッグ**: `WDT_ENABLE=0` 必須 — IWDG は LSI 駆動で Standby 中も動き、AWU 前にリセットしうる。

**状態**: Standby/AWU/EXTI 経路はコンパイル対応だが**実機での確認が必須**(Standby 復帰・AWU 周期・実電流)。
`LOW_POWER_MODE=0`(既定)は従来ファームと byte 同一。

## 5. 電池寿命の見積り

前提(明示・★実機要確認): 緑LED を 1kΩ・3V で ≈**0.9mA** / Standby ≈10µA / アクティブ48MHz ≈8mA /
点灯中Sleep@48MHz ≈3mA / 起床overhead ≈5ms / CR2032 ≈220mAh。平均電流は **「点灯時間を MCU がどう過ごすか」**
が支配的で、LED ではない。

コイン電池(3V) 常夜灯、5秒おきに 100ms:

| 構成 | 平均電流 | CR2032 寿命(見積) |
|---|---|---|
| 深い低電力(実装形: 点灯中 48MHz Sleep) | ~90µA | **~3〜4ヶ月** |
| 深い低電力＋点灯中クロック低下(将来最適化) | ~45µA | ~6.5ヶ月 |
| 深い低電力なし(48MHz 常時) | ~8mA | ~1日 |

- **抵抗バイアス vs 明るさ/寿命**: 510Ω(~1.8mA)は明るいが寿命ほぼ半分。**1kΩ(~0.9mA)が最良バランス**。
  ~1–2kΩ を超えると寿命は MCU+Standby の下限に漸近するので、以降は点灯時間短縮/クロック低下で延ばす。
- **セル選択**: CR2032×2 直列は電圧(6V)は倍だが**容量は増えず**、6V は CH32V003 の 5.5V 上限超過
  (要降圧=LDOで余剰エネルギーを捨てる) → LED電流の安定には効くが mAh 寿命には効かない。寿命重視は
  **並列**(~440mAh) か大容量セル(CR2450 ~600mAh ≈約2年)。CR2032 のパルス/内部抵抗対策に 10–100µF。

GUI 設定エディタは単色LED常夜灯でこの CR2032 目安を 1kΩ 前提でライブ表示する。

## 6. 本体LEDドライバの選定

**確定条件:** 5V単一電源 ・ 白色系 本体LED ・ 常夜灯は抵抗で電流設定 ・ 本体PWMは **≤2kHz**
(CN5711 の CE ピンで調光するため)。

### CN5711 (Consonance) — 採用候補
リニア定電流ドライバ: Vin 2.8–6V、最大 **1.5A**、低ドロップ **0.37V@1.5A**、±5%、オンチップMOSFET＋センス、
電流は **ISET抵抗**(≤30kΩ)で設定、**温度レギュレーション(フォールドバック)**、SOP8。
**CE ピンへの PWM で調光(<2kHz)**。採用時は個別 MOSFET(FDS5680)ゲート駆動を置換
(LED陽極→5V、陰極→CN5711 LEDピン、CE←MCU の PWM)。

**最大の注意 — リニアである点:** `(Vin − Vf) × I` を IC 自身で熱にする。5V→白色LED(~3.2V)ではドロップ ~1.8V:

| 本体LED電流 | CN5711 損失 | SOP8(放熱パッド) |
|---|---|---|
| 100mA | ~0.18W | 余裕 |
| 300mA | ~0.54W | 良好(銅箔広め) |
| 500mA | ~0.9W | 際どい |
| **1A** | **~1.8W** | 過大→温度フォールドバック(自動減光) |

現行 MOSFET＋抵抗が「発熱ほぼ無し」だったのは `(Vin−Vf)` 損失が外部電流制限側にあった/LED電流が控えめ
だったため。リニアドライバは**その損失を小さな SOP8 に集中**させる。よって ~1A 白色/5V では CN5711 は
フォールドバックする。

### 代替
- **AMC7135** — より安いリニアCC、固定350mA(並列でN倍)、全体PWM。最安だが粒度固定・発熱大。
- **PT4115 / AL8860 / MT7202** — **降圧(buck)** CC、DIM ピン(PWM, >2kHz も可)。Vin≫Vf や電池で高効率、
  `(Vin−Vf)` を熱にしない。インダクタ＋ショットキーで BOM/面積増。

### 判断（本体LED電流別, 5V, 白色）
- **≤ ~300–400mA → CN5711 が最適**: 簡潔・低ドロップ・部品少・温度フォールドバック内蔵
  (MCU 側の温度保護も軽くできる)。
- **~1A → 降圧ドライバ(PT4115等)** か LED電流を下げる、または MOSFET＋CC のまま。

### ≤2kHz CE 調光の firmware 反映
本体 PWM を ≤2kHz に。例) `PWM_TOP=23999, PWM_PSC=0` → 48MHz/24000 = **2kHz**(24000段, ちらつき無し)。
あるいは MOSFET 高速PWM のままにして CC IC を足さない。

**出典 (CN5711):**
[LCSC C35634](https://www.lcsc.com/product-detail/C35634.html) ·
[datasheetbank preview](https://www.datasheetbank.com/en/preview/CN5711-CONSONANCE) ·
[alldatasheet](https://www.alldatasheet.com/datasheet-pdf/pdf/1133252/CONSONANCE/CN5711.html)

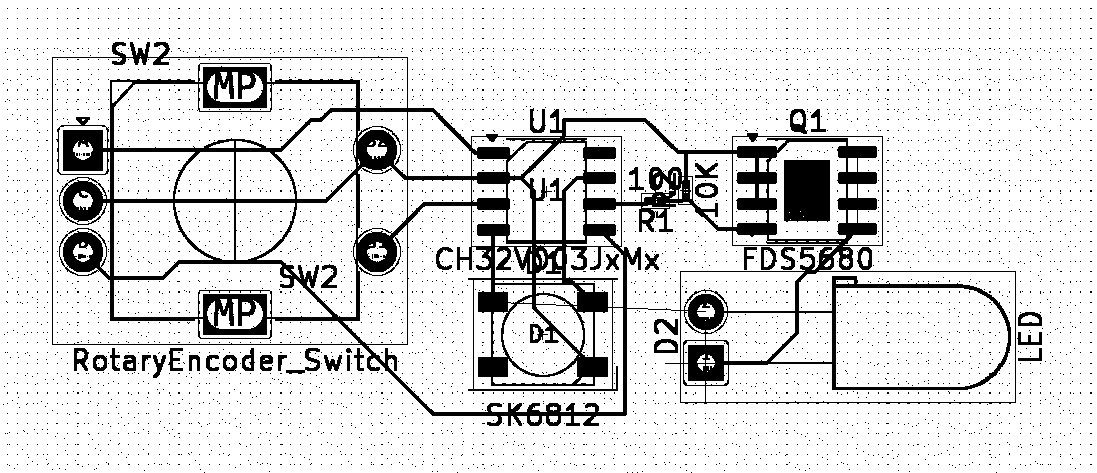
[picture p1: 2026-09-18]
PCB/AertWork.png

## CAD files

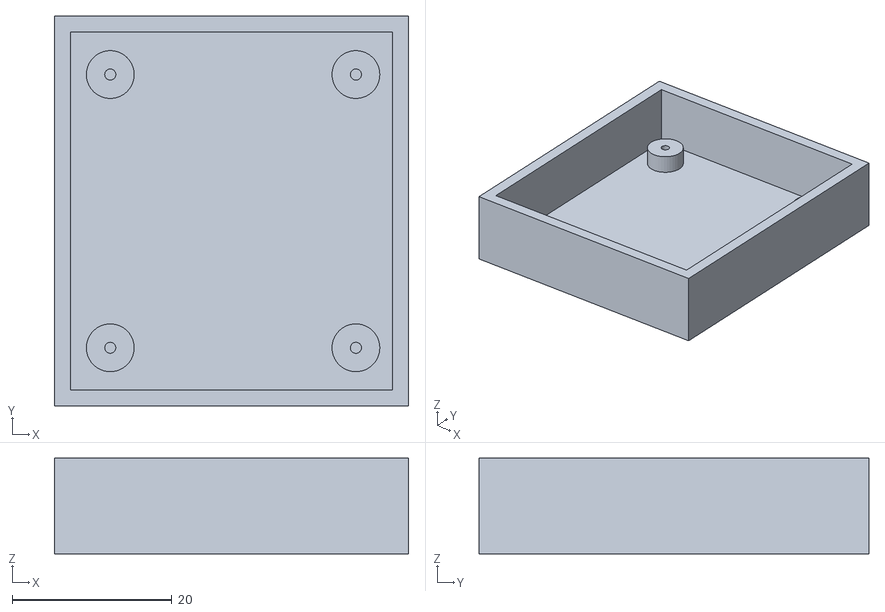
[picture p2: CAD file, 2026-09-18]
3D_Models/singleTeststl.stl
44.4 x 48.9 x 12.0

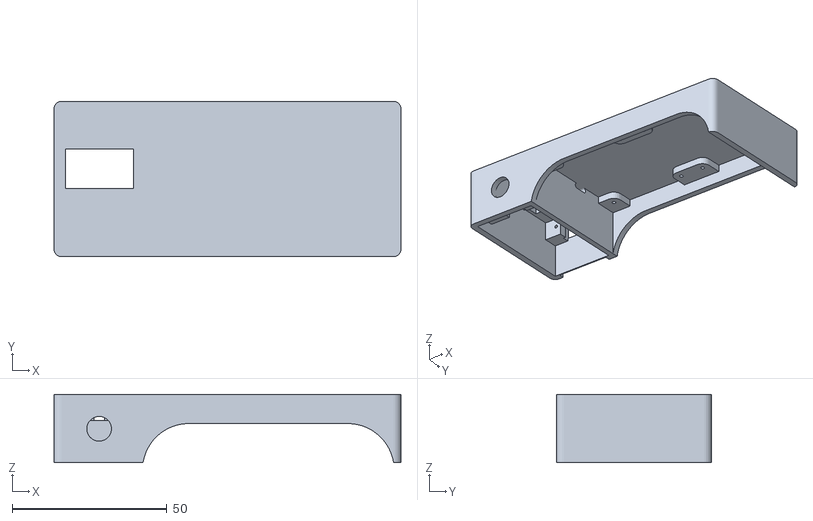
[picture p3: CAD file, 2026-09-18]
3D_Models/LightBoxMini.stl
112.2 x 50.2 x 22.0

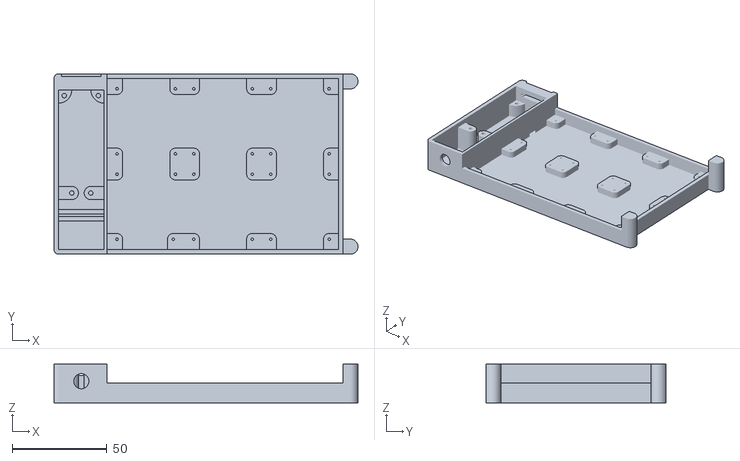
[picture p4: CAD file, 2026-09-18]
3D_Models/LightBox.stl
160.2 x 95.1 x 20.4

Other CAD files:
3D_Models/LightBoxMini.f3d

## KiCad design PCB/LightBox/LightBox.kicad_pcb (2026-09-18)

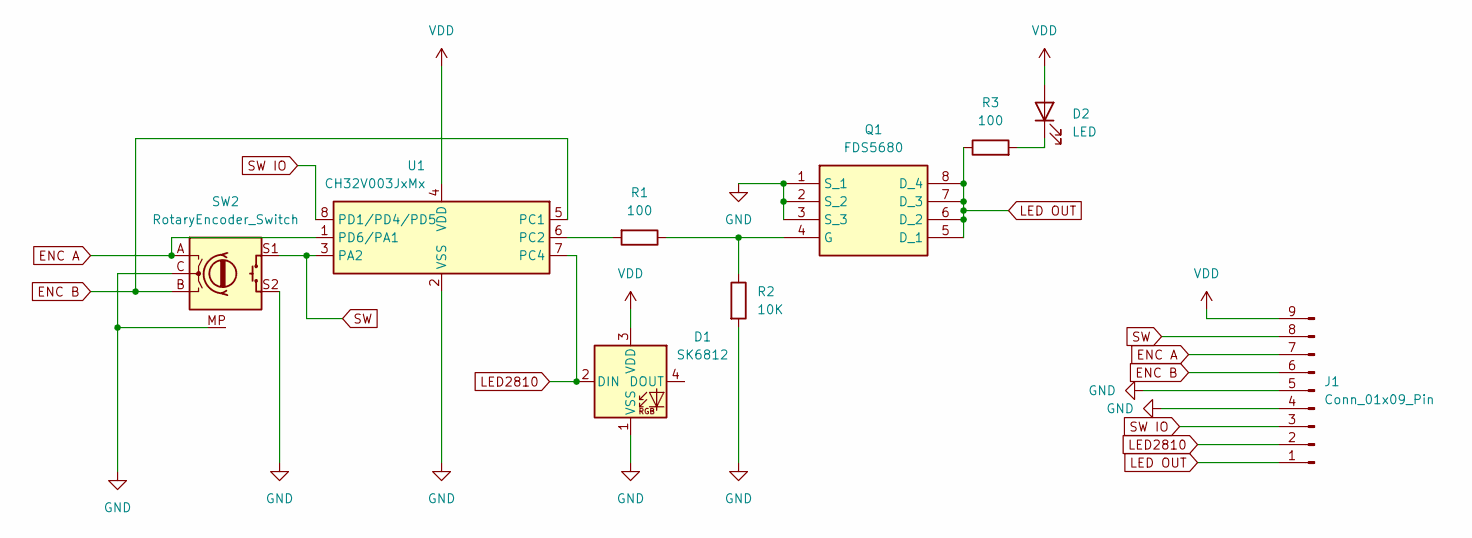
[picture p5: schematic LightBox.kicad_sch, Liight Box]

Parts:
D1: SK6812; LED_SK6812_PLCC4_5.0x5.0mm_P3.2mm
D2: LED; LED_D3.0mm
J1: Conn_01x09_Pin; PinHeader_1x09_P2.54mm_Vertical
Q1: FDS5680; SOIC-8-1EP_3.9x4.9mm_P1.27mm_EP2.29x3mm; Manufacturer_Part_Number FDS5680; Mouser Part Number 512-FDS5680
R1, R3: 100; R_0201_0603Metric
R2: 10K; R_0201_0603Metric
SW2: RotaryEncoder_Switch; RotaryEncoder_Alps_EC11E-Switch_Vertical_H20mm
U1: CH32V003JxMx; SOP-8_3.9x4.9mm_P1.27mm

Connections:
ENC A: J1.7, SW2.A, U1.1 (PD6/PA1)
ENC B: J1.6, SW2.B, U1.5 (PC1)
GND: D1.1 (VSS), J1.4, J1.5, Q1.1 (S_1), Q1.2 (S_2), Q1.3 (S_3), R2.2, SW2.C, SW2.MP, SW2.S2, U1.2 (VSS)
LED2810: D1.2 (DIN), J1.2, U1.7 (PC4)
LED OUT: J1.1, Q1.5 (D_1), Q1.6 (D_2), Q1.7 (D_3), Q1.8 (D_4), R3.1
unnamed: D2.1 (K), R3.2
unnamed: Q1.4 (G), R1.1, R2.1
unnamed: R1.2, U1.6 (PC2)
SW: J1.8, SW2.S1, U1.3 (PA2)
SW IO: J1.3, U1.8 (PD1/PD4/PD5)
VDD: D1.3 (VDD), D2.2 (A), J1.9, U1.4 (VDD)

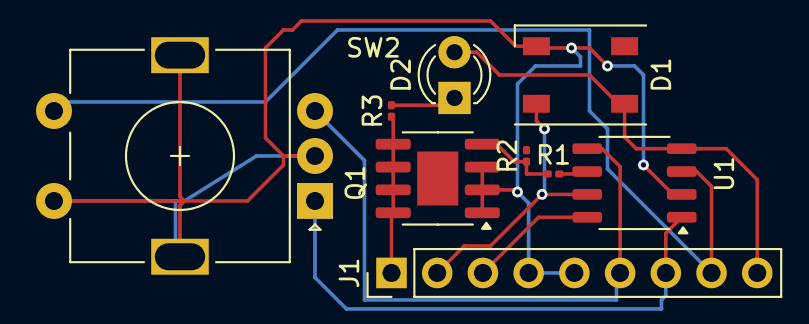
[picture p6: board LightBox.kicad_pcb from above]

Board: 2 copper layers, 9 parts (0 on the bottom side), 11 nets.

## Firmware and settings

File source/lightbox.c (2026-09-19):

/*
 * lightbox.c — CH32V003J4M6 (SOP8) LED 調光コントローラ
 *
 *  ・入力 : ローカル接続のロータリーエンコーダ (A/B 直交 + 押しSW)
 *  ・出力 : シングル PWM (LED 1ch)  — 16bit タイマ TIM2_CH2 / PC2
 *  ・調光 : CIE 1931 L*(明度) → 1クリック=知覚的に等量の明るさ変化 (人間の目を再現)
 *  ・機能 : 高速回しで duty=100%/0% スナップ / CW・CCW 両対応
 *
 *  全チューニング値は config.h に集約。整数演算のみ (CH32V003 は FPU 無し。
 *  LUT の立方項は起動時に uint64 で計算。libm/float には依存しない)。
 *
 *  ── SOP8 (J4M6) ピン割当 ── ※PD1 は SWIO(書込/printf) のため温存
 *   pin1 PA1 : ENC_A        内部プルアップ, 共通=GND
 *   pin2 VSS : GND
 *   pin3 PA2 : ENC_SW       内部プルアップ, 押下=Low (短押し=ON/OFFトグル)
 *   pin4 VDD : 3.3V
 *   pin5 PC1 : ENC_B        内部プルアップ, 共通=GND
 *   pin6 PC2 : PWM 出力(LED) TIM2_CH2 remap1
 *   pin7 PC4 : WS2812/SK6812 常夜灯データ (SOP8で唯一の空きピン。用途は排他で選択)
 *   pin8 PD1 : SWIO
 *
 *  SOP8 でも全機能が載る構成:
 *   ・温度=ダイ推定(熱モデル,ピン不要) / 過熱遮断・スロットル(PWMに作用,ピン不要)
 *   ・ウォッチドッグ(IWDG,ピン不要) / EMI対策(スルーレート・スペクトラム拡散,ピン不要)
 *   ・PC4 は 常夜灯 / 外付け温度センサ / 警告灯 のいずれか1つに割当(排他)。
 */
#include "ch32fun.h"
#include "config.h"
#include "pins.h"      /* 機能↔ピンの導出・能力/衝突のコンパイル時検証 */
#include "cie.h"
#if STORE_ENABLE
#include "store.h"
#endif
#if TEMP_PROTECT_ENABLE
#include "temp.h"
#endif
#if WDT_ENABLE
#include "wdt.h"
#endif
#if NIGHTLIGHT_ENABLE
  #if NIGHTLIGHT_TYPE == NL_TYPE_WS2812
    #define WS2812BSIMPLE_IMPLEMENTATION
    #include "nightlight.h"          /* ①WS2812/SK6812(従来・演出優先) */
  #else
    #include "nl_single.h"           /* ②単色LED(専用ピン, n秒/x ms/PWM有無) */
  #endif
#endif
#if LOW_POWER_MODE
  #include "lowpower.h"              /* 深い低電力(Standby+AWU)常夜灯 ★実験的 */
#endif

/* デバッグログ: 既定OFF。printf はブロッキングでホスト未接続だと停滞し、
 * ホットループ内では高速回転の遷移取りこぼし/スナップ不発を招くため通常は無効。 */
#if DEBUG_LOG
#include <stdio.h>
#define DBG(...)  printf(__VA_ARGS__)
#else
#define DBG(...)  ((void)0)
#endif

/* config の別名 (ピンは funPinMode 等へそのまま渡す) */
#define ENC_A   ENC_A_PIN
#define ENC_B   ENC_B_PIN
#define ENC_SW  ENC_SW_PIN

/* ---- 設定値の範囲チェック(堅牢性) ---- */
_Static_assert(LEVELS >= 1u && LEVELS <= 127u,
               "LEVELS は 1..127 (0=除算不能, 127=ストアの7bit level上限)");
_Static_assert(PWM_TOP >= 1u && PWM_TOP <= 65535u, "PWM_TOP は 1..65535 (16bit)");
_Static_assert(LEVEL_INIT <= LEVELS, "LEVEL_INIT は LEVELS 以下");
_Static_assert(SNAP_CLICKS >= 2u, "SNAP_CLICKS は 2 以上");

static uint8_t  g_level = LEVEL_INIT;   /* 現在の調光レベル 0..LEVELS */
static uint8_t  g_on    = 1;            /* ソフト ON/OFF */

/* PWM出力の実効デューティ(PWM_TOP基準)。スペクトラム拡散で ATRLR が動くため保持。 */
static uint16_t g_curDuty = 0;

#if TEMP_PROTECT_ENABLE
static uint8_t  g_thermCut  = 0;        /* 過熱で出力遮断中か */
static uint8_t  g_tripCount = 0;        /* 遮断→再開の回数 */
static uint8_t  g_deratePct = 0;        /* サーマルスロットルの累積ダウン率(%) */
#endif

/* PWM_SLEW_MHZ(2/10/30) → GPIO速度マクロ */
#if   PWM_SLEW_MHZ == 2
  #define PWM_GPIO_SPEED  GPIO_Speed_2MHz
#elif PWM_SLEW_MHZ == 30
  #define PWM_GPIO_SPEED  GPIO_Speed_30MHz
#else
  #define PWM_GPIO_SPEED  GPIO_Speed_10MHz
#endif

/* g_curDuty(PWM_TOP基準) を現在の周期(ATRLR)にスケールして選択チャネルの CVR に書く。
 * タイマ/チャネルは PWM_PIN から pins.h が導出 (既定 PC2=TIM2_CH2)。 */
static inline void pwm_write(void)
{
    uint32_t arr = PWM_TIMREG->ATRLR;         /* スペクトラム拡散で PWM_TOP から変動しうる */
    PWM_CVR = (uint32_t)g_curDuty * (arr + 1u) / (PWM_TOP + 1u);
}

/* ---- 表示輝度 (L*空間) とソフトスタート(フェード)状態 ----
 * g_dispLx = 実際に表示中の明度 L*(x100, 0..10000)。ON/OFF はこれをフェードさせる。
 * duty は cie_scale(g_dispLx) で算出 → フェードも人間の知覚で均等。 */
static uint16_t g_dispLx  = 0;            /* 現在表示中の L* */
static uint16_t g_fadeFrom = 0, g_fadeTo = 0;
static uint32_t g_fadeStart = 0;
static uint16_t g_fadeDurMs = 0;          /* 0 = フェードなし(停止) */

#if PWM_ON_TIME_S > 0
/* 自動消灯タイマ: 点灯からの経過を1秒刻みで数える(SysTick ラップ非依存)。
 * 操作のたびに arm() でリセット(=延長)。PWM_ON_TIME_S 秒到達で g_on=0 → ソフトオフ。 */
static uint32_t g_onSecTick = 0;          /* 1秒刻みの基準 tick */
static uint32_t g_onSeconds = 0;          /* 点灯開始/最終操作からの経過秒 */
static inline void autooff_arm(void) { g_onSeconds = 0; g_onSecTick = SysTick->CNT; }
#else
static inline void autooff_arm(void) {}   /* 無効時は何もしない */
#endif

/* 目標 L*: ON なら現在レベルの L*, OFF なら 0 */
static inline uint16_t target_lx(void)
{
    return g_on ? (uint16_t)(10000u * g_level / LEVELS) : 0u;
}

/* g_dispLx から duty を算出し、保護を適用して PWM へ書く */
static void output_refresh(void)
{
    uint16_t duty = cie_scale(g_dispLx, PWM_TOP);
#if TEMP_PROTECT_ENABLE
    if (g_thermCut) {
        duty = 0;                             /* 過熱: 強制遮断(火災リスク回避) */
    } else if (g_deratePct) {
        duty = (uint16_t)((uint32_t)duty * (100u - g_deratePct) / 100u); /* スロットル */
    }
#endif
    g_curDuty = duty;
    pwm_write();
}

/* 即時に目標輝度へ(フェードなし) */
static void output_immediate(void)
{
    g_fadeDurMs = 0;
    g_dispLx = target_lx();
    output_refresh();
}

/* 目標変更(レベル変更/スナップ時): フェード中なら目標だけ差し替え、非フェード中は即時 */
static void output_retarget(void)
{
    if (g_fadeDurMs) { g_fadeTo = target_lx(); g_fadeFrom = g_dispLx; g_fadeStart = SysTick->CNT; }
    else             { output_immediate(); }
}

/* ソフトスタート開始(ON/OFFトグル/起動時)。dur_ms=0 なら即時。 */
static void output_begin_fade(uint16_t dur_ms)
{
    uint16_t tgt = target_lx();
    if (dur_ms == 0 || tgt == g_dispLx) { output_immediate(); return; }
    g_fadeFrom  = g_dispLx;
    g_fadeTo    = tgt;
    g_fadeDurMs = dur_ms;
    g_fadeStart = SysTick->CNT;
    output_refresh();
}

/* メインループで毎回呼ぶ: フェード進行(L*線形補間→CIE) */
static void fade_tick(void)
{
    if (!g_fadeDurMs) return;
    uint32_t el_ms = (uint32_t)(SysTick->CNT - g_fadeStart) / Ticks_from_Ms(1);
    uint16_t nl;
    if (el_ms >= g_fadeDurMs) { nl = g_fadeTo; g_fadeDurMs = 0; }  /* 完了 */
    else {
        int32_t span = (int32_t)g_fadeTo - (int32_t)g_fadeFrom;
        nl = (uint16_t)((int32_t)g_fadeFrom + span * (int32_t)el_ms / (int32_t)g_fadeDurMs);
    }
    if (nl != g_dispLx) { g_dispLx = nl; output_refresh(); }
}

/* PWM_PIN を 16bit PWM 出力に設定 (config: PWM_TOP/PWM_PSC)。
 * タイマ/チャネル/remap/GPIO は PWM_PIN から pins.h が導出。
 * 既定(PWM_PIN=PC2=TIM2_CH2 remap1)は従来と同一のレジスタ操作を生成する(挙動不変)。
 * ★PC2 以外(TIM1/別チャネル)はコンパイル対応・実機未検証。 */
static void pwm_init(void)
{
    RCC->APB2PCENR |= PWM_RCC_GPIO_BIT | RCC_APB2Periph_AFIO;
#if PWM_USES_TIM1
    RCC->APB2PCENR |= RCC_APB2Periph_TIM1;
#else
    RCC->APB1PCENR |= RCC_APB1Periph_TIM2;
#endif

    /* PWM_PIN が出るように remap を設定 (対象タイマの remap ビットのみ更新) */
    AFIO->PCFR1 &= ~PWM_REMAP_CLEAR;
    AFIO->PCFR1 |=  PWM_REMAP_SET;

    /* PWM_PIN = 代替機能プッシュプル出力。EMI対策でスルーレート(GPIO速度)を config 化 */
    PWM_GPIO_PORT->CFGLR &= ~(0xf << (4 * PWM_PINNUM));
    PWM_GPIO_PORT->CFGLR |=  (PWM_GPIO_SPEED | GPIO_CNF_OUT_PP_AF) << (4 * PWM_PINNUM);

    /* タイマ リセット */
#if PWM_USES_TIM1
    RCC->APB2PRSTR |=  RCC_APB2Periph_TIM1;
    RCC->APB2PRSTR &= ~RCC_APB2Periph_TIM1;
#else
    RCC->APB1PRSTR |=  RCC_APB1Periph_TIM2;
    RCC->APB1PRSTR &= ~RCC_APB1Periph_TIM2;
#endif

    PWM_TIMREG->PSC   = PWM_PSC;
    PWM_TIMREG->ATRLR = PWM_TOP;                          /* 16bit カウンタ (最大65535) */
    PWM_CHCTLR |= PWM_OCM;                                /* 選択CH=PWM mode1 + preload */
    PWM_TIMREG->CCER |= PWM_CCE;                          /* 選択CH 出力有効 (正論理) */
    /* ARPE: ARR(周期)もプリロード化。動作中に ATRLR を変えても更新イベント境界で
     * 反映されるため、スペクトラム拡散のディザで周期が途中で化ける/グリッチを防ぐ。 */
    PWM_TIMREG->CTLR1 |= TIM_ARPE;
#if PWM_USES_TIM1
    PWM_TIMREG->BDTR  |= TIM_MOE;                         /* 高機能タイマ(TIM1)は主出力許可が必須 */
#endif
    PWM_TIMREG->SWEVGR = TIM_UG;                          /* シャドウ即反映(ARR/CVR ロード) */
    PWM_TIMREG->CTLR1 |= TIM_CEN;

    output_refresh();          /* 起動直後は g_dispLx=0(消灯) */
}

/* エンコーダ / SW を内部プルアップ入力に */
static void encoder_init(void)
{
    funGpioInitAll();
    funPinMode(ENC_A,  GPIO_CFGLR_IN_PUPD); funDigitalWrite(ENC_A,  FUN_HIGH);
    funPinMode(ENC_B,  GPIO_CFGLR_IN_PUPD); funDigitalWrite(ENC_B,  FUN_HIGH);
    funPinMode(ENC_SW, GPIO_CFGLR_IN_PUPD); funDigitalWrite(ENC_SW, FUN_HIGH);
}

/* ===================== エンコーダ: フルステップ状態機械 (Ben Buxton方式) =====
 * 単純 delay に頼らず、ディテント間の"正しい遷移経路"を完走したときだけ 1 ステップを
 * 発火する状態機械でチャタリングを構造的に吸収する。途中でバウンスしても中間状態と
 * 静止位置(11)を往復するだけで DIR は出ず、単相のバタつきを無視できる。
 *   ・列 index = 現在の2相 (A<<1)|B  … 静止=0b11
 *   ・戻り値下位: 次状態、bit4=DIR_CW / bit5=DIR_CCW を含む */
#define DIR_CW   0x10
#define DIR_CCW  0x20

#if ENC_HALF_STEP
/* ハーフステップ: 半クリック(2遷移)で1回発火 */
enum { H_START, H_CCW_BEGIN, H_CW_BEGIN, H_START_M, H_CW_BEGIN_M, H_CCW_BEGIN_M };
static const uint8_t ENC_TT[6][4] = {
    /* H_START      */ { H_START_M,           H_CW_BEGIN,    H_CCW_BEGIN,   H_START           },
    /* H_CCW_BEGIN  */ { H_START_M | DIR_CCW, H_START,       H_CCW_BEGIN,   H_START           },
    /* H_CW_BEGIN   */ { H_START_M | DIR_CW,  H_CW_BEGIN,    H_START,       H_START           },
    /* H_START_M    */ { H_START_M,           H_CCW_BEGIN_M, H_CW_BEGIN_M,  H_START           },
    /* H_CW_BEGIN_M */ { H_START_M,           H_START_M,     H_CW_BEGIN_M,  H_START | DIR_CW  },
    /* H_CCW_BEGIN_M*/ { H_START_M,           H_CCW_BEGIN_M, H_START_M,     H_START | DIR_CCW },
};
#else
/* フルステップ: 1クリック(4遷移)で1回発火 */
enum { F_START, F_CW_FINAL, F_CW_BEGIN, F_CW_NEXT, F_CCW_BEGIN, F_CCW_FINAL, F_CCW_NEXT };
static const uint8_t ENC_TT[7][4] = {
    /* F_START     */ { F_START,    F_CW_BEGIN,  F_CCW_BEGIN, F_START            },
    /* F_CW_FINAL  */ { F_CW_NEXT,  F_START,     F_CW_FINAL,  F_START | DIR_CW   },
    /* F_CW_BEGIN  */ { F_CW_NEXT,  F_CW_BEGIN,  F_START,     F_START            },
    /* F_CW_NEXT   */ { F_CW_NEXT,  F_CW_BEGIN,  F_CW_FINAL,  F_START            },
    /* F_CCW_BEGIN */ { F_CCW_NEXT, F_START,     F_CCW_BEGIN, F_START            },
    /* F_CCW_FINAL */ { F_CCW_NEXT, F_CCW_FINAL, F_START,     F_START | DIR_CCW  },
    /* F_CCW_NEXT  */ { F_CCW_NEXT, F_CCW_FINAL, F_CCW_BEGIN, F_START            },
};
#endif

static uint8_t g_encState = 0;   /* 状態機械の現在状態 (START = 0) */

/* A/B を1回読み、状態機械を1段進める。ディテント完成時のみ +1(CW)/-1(CCW) を返す(他は0)。 */
static int8_t enc_poll(void)
{
    uint8_t ab = (uint8_t)((funDigitalRead(ENC_A) << 1) | funDigitalRead(ENC_B));
    g_encState = ENC_TT[g_encState & 0x0f][ab];
    if (g_encState & DIR_CW)  return +1;
    if (g_encState & DIR_CCW) return -1;
    return 0;
}

/* ---- 高速回しスナップ: 同方向の直近 SNAP_CLICKS 回の時刻を保持 ---- */
static uint32_t g_snapTick[SNAP_CLICKS];
static uint8_t  g_snapIdx = 0;      /* 次に書く位置 = 最古の位置(満杯時) */
static uint8_t  g_snapCnt = 0;
static int8_t   g_snapDir = 0;

/* クリック(ディテント)1回を記録し、窓内 j 回以上なら 1 を返す */
static uint8_t snap_hit(int8_t dir, uint32_t now)
{
    if (dir != g_snapDir) { g_snapDir = dir; g_snapCnt = 0; g_snapIdx = 0; }

    g_snapTick[g_snapIdx] = now;
    uint8_t oldestIdx = (uint8_t)((g_snapIdx + 1u) % SNAP_CLICKS);
    g_snapIdx = oldestIdx;
    if (g_snapCnt < SNAP_CLICKS) g_snapCnt++;

    if (g_snapCnt >= SNAP_CLICKS) {
        uint32_t span = now - g_snapTick[oldestIdx];   /* 直近 j 回の所要時間(符号なし=ラップ安全) */
        if (span <= Ticks_from_Ms(SNAP_WINDOW_MS)) {
            g_snapCnt = 0; g_snapIdx = 0;               /* 連続スナップ抑止 */
            return 1;
        }
    }
    return 0;
}

#if PWM_SPREAD_SPECTRUM
/* スペクトラム拡散: ATRLR を PWM_TOP±PWM_SPREAD_RANGE で微小ディザ(周波数を分散)。
 * duty比は pwm_write が周期に追従させるので明るさは不変。
 * ★ATRLR は TIM2 の16bitレジスタ(最大65535)。PWM_TOP+j が 65536 以上になると
 *   切り詰めで 0 等に化けるので [1,65535] にクランプする。
 *   (設定段階の保証として下の _Static_assert も参照) */
static uint32_t g_lcg = 0x1234567u;
static void spread_tick(void)
{
    g_lcg = g_lcg * 1664525u + 1013904223u;              /* 簡易LCG */
    int32_t j   = (int32_t)(g_lcg % (2u * PWM_SPREAD_RANGE + 1u)) - (int32_t)PWM_SPREAD_RANGE;
    int32_t arr = (int32_t)PWM_TOP + j;
    if (arr > 65535) arr = 65535;                        /* 16bit ARR 上限 */
    if (arr < 1)     arr = 1;                            /* 下限(0除算/0周期回避) */
    PWM_TIMREG->ATRLR = (uint32_t)arr;
    pwm_write();                                          /* 新周期に CVR を再スケール */
}
/* 設定ミス防止: 拡散レンジを含めて 16bit(<=65535)に収め、下側も正に保つこと */
_Static_assert((uint32_t)PWM_TOP + PWM_SPREAD_RANGE <= 65535u,
               "PWM_TOP+PWM_SPREAD_RANGE が 65535 超(16bit ARRを超える)。PWM_TOP か RANGE を下げる");
_Static_assert(PWM_TOP > PWM_SPREAD_RANGE,
               "PWM_SPREAD_RANGE が PWM_TOP 以上(周期が0以下になりうる)");
#endif

#if TEMP_PROTECT_ENABLE
/* 過熱保護の状態機械: 遮断/再開/トリップ計数/サーマルスロットル */
static void thermal_protect(int16_t tC)
{
    if (!g_thermCut) {
        if (tC >= WARN_TEMP_C) {                          /* 過熱 → 強制遮断 */
            g_thermCut = 1;
            if (g_tripCount < 0xFF) g_tripCount++;
            /* THERMAL_TRIP_N 回ごとに j% 累積ダウン(上限 THERMAL_THROTTLE_MAX) */
            if (THERMAL_TRIP_N > 0 && (g_tripCount % THERMAL_TRIP_N) == 0) {
                uint16_t d = (uint16_t)g_deratePct + THERMAL_THROTTLE_PCT;
                if (d > THERMAL_THROTTLE_MAX) d = THERMAL_THROTTLE_MAX;
                g_deratePct = (uint8_t)d;
            }
            output_refresh();
            DBG("THERMAL CUT t=%dC trips=%u derate=%u%%\n", tC, g_tripCount, g_deratePct);
        }
    } else {
        if (tC <= (WARN_TEMP_C - WARN_TEMP_HYST_C)) {     /* 冷えた → 再開(スロットル適用) */
            g_thermCut = 0;
            output_refresh();
            DBG("THERMAL RESUME t=%dC derate=%u%%\n", tC, g_deratePct);
        }
    }
    temp_warn_led(g_thermCut);
}
#endif

int main(void)
{
    SystemInit();
    encoder_init();        /* funGpioInitAll を含む → 先に */
#if STORE_ENABLE
    {                                  /* 前回の ON/OFF + 明るさを復元(空=初回なら OFF/0) */
        uint16_t st = store_load();
        g_level = STORE_LEVEL(st);
        if (g_level > LEVELS) g_level = LEVELS;   /* 破損ガード */
        g_on = STORE_ON(st);
    }
#endif
    pwm_init();            /* g_dispLx=0(消灯)で起動 (PWM_PIN から導出) */
#if TEMP_PROTECT_ENABLE
    temp_init();
#endif
#if NIGHTLIGHT_ENABLE
  #if NIGHTLIGHT_TYPE == NL_TYPE_WS2812
    nightlight_init();
  #else
    nl_single_init();
  #endif
#endif
#if WDT_ENABLE
    wdt_init();            /* 全初期化後に開始 */
#endif

#if NIGHTLIGHT_ENABLE && (NIGHTLIGHT_TYPE == NL_TYPE_WS2812) && (NIGHTLIGHT_BOOT_TEST_MS > 0)
    /* 起動セルフテスト: 常夜灯LEDを一定時間点灯して配線/タイミングを切り分け */
    nightlight_test_on();
    {
        uint32_t t0 = SysTick->CNT;
        while ((uint32_t)(SysTick->CNT - t0) < Ticks_from_Ms(NIGHTLIGHT_BOOT_TEST_MS)) {
#if WDT_ENABLE
            wdt_feed();                    /* テスト中も WDT を維持 */
#endif
        }
    }
#endif

    /* 起動(電源投入): 復元輝度へソフトスタート・フェードイン */
    output_begin_fade(SOFT_START_ON);
    if (g_on) autooff_arm();               /* 点灯状態で起動したら自動消灯カウント開始 */

#if LOW_POWER_MODE
    /* 深い低電力: 起動時に押しSW非押下なら常夜灯スリープサイクルへ。
     * 押下(=起動時ホールド or 押しSW起水)なら通常アクティブモードに留まる(reflash-safe)。 */
    lp_init();
    if (!lp_button_down()) {
        lowpower_nightlight_cycle();       /* 押しSW起水で戻る(reset復帰時は main 再実行で同判断) */
        encoder_init();                    /* アナログ化したエンコーダピンを通常入力へ戻す */
        output_begin_fade(SOFT_START_ON);
    }
    uint32_t lpActivityTick = SysTick->CNT; /* アクティブ窓のアクティビティ計時 */
#endif

    DBG("LightBox CH32V003: CIE-L* dimmer  level=%u/%u top=%u rev=%u half=%u lock=%ums snap=%u/%ums\n",
        g_level, LEVELS, (unsigned)PWM_TOP,
        ENC_REVERSE, ENC_HALF_STEP, ENC_REVERSAL_LOCK_MS, SNAP_CLICKS, SNAP_WINDOW_MS);

    /* 方向反転ロックアウト用 */
    int8_t   lastDir      = 0;              /* 直前に"確定"した方向 (+1/-1) */
    uint32_t lastStepTick = SysTick->CNT;

    /* 押しSW 時間ベース・デバウンス */
    uint8_t  swStable   = 1;                /* 確定状態 (1=放し, 0=押下) */
    uint8_t  swCand     = 1;                /* 候補(生読み)状態 */
    uint32_t swCandTick = SysTick->CNT;     /* 候補が変わった時刻 */

#if STORE_ENABLE
    /* 不揮発ストア: 状態(ON/OFF+level)が STORE_COMMIT_MS 変化しなくなったら1回だけ書込 */
    uint16_t savedState = STORE_PACK(g_on, g_level);  /* 既にフラッシュにある状態 */
    uint8_t  dirty      = 0;                /* 未保存の変更あり */
    uint32_t dirtyTick  = 0;                /* 最後に変更した時刻 */
#endif
#if TEMP_PROTECT_ENABLE
    uint32_t tempTick   = SysTick->CNT;     /* 温度サンプリング周期用 */
#endif
#if PWM_SPREAD_SPECTRUM
    uint32_t spreadTick = SysTick->CNT;     /* スペクトラム拡散ディザ周期用 */
#endif

    for (;;) {
#if WDT_ENABLE
        wdt_feed();                         /* ループが回っている限りリセットしない */
#endif
        fade_tick();                        /* ソフトスタート進行 */
        /* --- ロータリー: 状態機械 → ディテント完成時のみ dir --- */
        int8_t dir = enc_poll();
        if (dir) {
#if ENC_REVERSE
            dir = (int8_t)-dir;                             /* CW/CCW 反転 (config) */
#endif
            uint32_t now = SysTick->CNT;

            /* 方向反転ロックアウト: 直前と逆方向が極短時間(既定5ms)に来たら
             * 物理的にあり得ない=バウンスとして破棄。同方向は制限しない。 */
            if (dir == -lastDir &&
                (uint32_t)(now - lastStepTick) < Ticks_from_Ms(ENC_REVERSAL_LOCK_MS)) {
                /* バウンス反転 → 無視 (状態は据置、lastStepTick も更新しない) */
            } else {
                uint32_t sinceLast = (uint32_t)(now - lastStepTick); /* 前クリックからの間隔 */
                int8_t   prevDir   = lastDir;
                lastDir = dir; lastStepTick = now;

                /* 加速: 同方向を速く連続で回したら 1クリック=±ENC_ACCEL_FACTOR 段 */
                uint8_t step = 1;
#if ENC_ACCEL_ENABLE
                if (dir == prevDir && sinceLast < Ticks_from_Ms(ENC_ACCEL_WINDOW_MS))
                    step = ENC_ACCEL_FACTOR;
#else
                (void)prevDir; (void)sinceLast;
#endif
                /* 先に新レベルを確定 */
                if (snap_hit(dir, now)) {
                    if (dir > 0) { g_level = LEVELS; g_on = 1; }  /* 全開 */
                    else         { g_level = 0;      }            /* 消灯(0%) */
                    DBG("SNAP %s -> level=%u duty=%u\n",
                        dir > 0 ? "MAX" : "MIN", g_level, cie_level(g_level, LEVELS, PWM_TOP));
                } else {
                    /* 通常: 1 クリック = ±step 段 (加速時 ×ENC_ACCEL_FACTOR)。エンコーダは即応 */
                    if (dir > 0) g_level = (g_level + step > LEVELS) ? (uint8_t)LEVELS
                                                                     : (uint8_t)(g_level + step);
                    else         g_level = (g_level > step)         ? (uint8_t)(g_level - step) : 0u;
                    DBG("level=%u/%u step=%u duty=%u\n", g_level, LEVELS, step,
                        cie_level(g_level, LEVELS, PWM_TOP));
                }
#if WAKE_ON_TURN
                /* OFF中に回したら点灯復帰。ただし"明るさが出る"操作(level>0)のときだけ。
                 * level==0 のまま(例: 消灯状態で更に暗方向)は g_on を立てない
                 * → 「回したのに点灯せず on だけ立つ」不整合を防ぐ。 */
                if (g_level > 0) g_on = 1;
#endif
                output_retarget();
                if (g_on) autooff_arm();           /* 操作があったら自動消灯カウントをリセット(延長) */
#if LOW_POWER_MODE
                lpActivityTick = now;              /* 操作 → アクティブ窓を延長 */
#endif
#if STORE_ENABLE
                dirty = 1; dirtyTick = now;        /* 変更 → 5秒後にコミット予約 */
#endif
            }
        }

        /* --- 押しSW: 時間ベース積分デバウンス (安定 SW_DEBOUNCE_MS で確定) --- */
        uint8_t swRaw = funDigitalRead(ENC_SW);        /* 押下=Low(0) */
        uint32_t nowSw = SysTick->CNT;
        if (swRaw != swCand) {                          /* 生読みが動いた→候補更新+計時 */
            swCand = swRaw; swCandTick = nowSw;
        } else if (swCand != swStable &&
                   (uint32_t)(nowSw - swCandTick) >= Ticks_from_Ms(SW_DEBOUNCE_MS)) {
            swStable = swCand;                          /* 安定継続→確定 */
            if (swStable == 0) {                        /* 確定した押下(立下り)でトグル */
                g_on = !g_on;
                output_begin_fade(g_on ? SOFT_START_ON : SOFT_START_OFF);  /* ソフトスタート */
                if (g_on) autooff_arm();                /* ONトグルで自動消灯カウント開始 */
#if LOW_POWER_MODE
                lpActivityTick = SysTick->CNT;          /* 押しSW操作 → アクティブ窓を延長 */
#endif
                DBG("output %s\n", g_on ? "ON" : "OFF");
#if STORE_ENABLE
                dirty = 1; dirtyTick = SysTick->CNT;    /* ON/OFF も保存対象 → コミット予約 */
#endif
            }
        }

#if STORE_ENABLE
        /* --- 不揮発コミット: 状態が STORE_COMMIT_MS 変化しなければ1回だけ書込 --- */
        if (dirty) {
            uint32_t nc = SysTick->CNT;
            if ((uint32_t)(nc - dirtyTick) >= Ticks_from_Ms(STORE_COMMIT_MS)) {
                uint16_t st = STORE_PACK(g_on, g_level);
                if (st != savedState) { store_save(st); savedState = st; }
                dirty = 0;
            }
        }
#endif

#if PWM_ON_TIME_S > 0
        /* --- 自動消灯タイマ: 点灯からの経過秒が PWM_ON_TIME_S に達したらソフトオフ ---
         * 1秒刻みで数えるので SysTick(32bit@48MHz, ~89秒周期)のラップに依存しない。 */
        if (g_on) {
            if ((uint32_t)(SysTick->CNT - g_onSecTick) >= Ticks_from_Ms(1000u)) {
                g_onSecTick += Ticks_from_Ms(1000u);        /* 1秒進める(ドリフト無し) */
                if (++g_onSeconds >= (uint32_t)PWM_ON_TIME_S) {
                    g_on = 0;
                    output_begin_fade(SOFT_START_OFF);      /* 自動消灯(ソフトオフ) */
                    DBG("AUTO-OFF after %us\n", (unsigned)PWM_ON_TIME_S);
#if STORE_ENABLE
                    dirty = 1; dirtyTick = SysTick->CNT;    /* OFF状態を保存予約 */
#endif
                }
            }
        }
#endif

#if TEMP_PROTECT_ENABLE
        /* --- 過熱保護 (周期サンプリング → 遮断/再開/スロットル) --- */
        if ((uint32_t)(SysTick->CNT - tempTick) >= Ticks_from_Ms(WARN_TEMP_PERIOD_MS)) {
            tempTick = SysTick->CNT;
            int16_t tc = temp_sample(g_curDuty);    /* DIEモデルは実効デューティで自己発熱推定 */
            thermal_protect(tc);
            DBG("temp=%dC cut=%u trips=%u derate=%u%%\n",
                tc, g_thermCut, g_tripCount, g_deratePct);
        }
#endif

#if PWM_SPREAD_SPECTRUM
        /* --- スペクトラム拡散: 周期ディザ --- */
        if ((uint32_t)(SysTick->CNT - spreadTick) >= Ticks_from_Ms(PWM_SPREAD_PERIOD_MS)) {
            spreadTick = SysTick->CNT;
            spread_tick();
        }
#endif

#if NIGHTLIGHT_ENABLE
        /* --- 常夜灯: 本体が完全に暗い(消灯意図かつフェード完了で輝度0)ときだけ動作 --- */
        {
            uint8_t nl_dark = ((!g_on || g_level == 0) && g_dispLx == 0) ? 1u : 0u;
  #if NIGHTLIGHT_TYPE == NL_TYPE_WS2812
            nightlight_update(nl_dark);      /* ①WS2812: 呼吸 */
  #else
            nl_single_update(nl_dark);       /* ②単色LED: 周期点灯 */
  #endif
        }
#endif
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

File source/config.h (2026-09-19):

/*
 * config.h — LightBox 設定 (ユーザが触るのはこのファイル)
 *
 *  ここに全チューニング値を集約。lightbox.c は本ヘッダを include するだけ。
 *  (ch32fun 本体の設定は別ファイル funconfig.h)
 */
#ifndef CONFIG_H
#define CONFIG_H

/* ===================== ピン割当 (SOP8 / J4M6) =====================
 * 「1機能=1ピンマクロ」で割当てる。port/ピン番号・ADCチャネル・PWMのタイマ/チャネル/remap は
 * pins.h が自動導出し、ハード能力違反(PWM/ADC不可ピン)とピン衝突(2機能が同一ピン)を
 * コンパイル時に _Static_assert で弾く。SOP8 実在ピン: PA1/PA2/PC1/PC2/PC4/PD1(SWIO予約)。
 *
 *   PWM_PIN 選択肢(正出力): PC2=TIM2_CH2(remap1,既定) / PC1=TIM2_CH4(remap1)
 *                          / PA1=TIM1_CH2 / PC4=TIM1_CH4
 *   ADC対応ピン(外付け温度): PA2/PA1/PC4 のみ
 *   ※PC2 以外の PWM は「コンパイル対応・実機未検証」。既定(PC2)は従来と挙動不変。 */
#define PWM_PIN      PC2     /* 本体LED PWM 出力 (既定 PC2=TIM2_CH2 remap1) */
#define ENC_A_PIN    PA1     /* エンコーダ A 相 (内部プルアップ, 共通=GND) */
#define ENC_B_PIN    PC1     /* エンコーダ B 相 (内部プルアップ, 共通=GND) */
#define ENC_SW_PIN   PA2     /* 押しSW (内部プルアップ, 押下=Low, 短押し=ON/OFF) */

/* ===================== PWM (16bit タイマ TIM2) =====================
 * TIM2 は 16bit カウンタ。PWM_TOP は最大 65535 まで設定可。
 *   周波数 = 48MHz / (PWM_TOP+1) / (PWM_PSC+1)
 *   分解能 = PWM_TOP+1 段
 * 既定 4095(12bit) → 約 11.7kHz: フリッカ/可聴音なし かつ 低輝度も細かい。
 * さらに滑らかにしたい場合 8191/16383 等へ上げる (周波数は下がる)。 */
#define PWM_TOP      4095u
#define PWM_PSC      0u

/* --- EMI 対策 (大電流LED時のノイズ低減) ---
 * PWM_SLEW_MHZ: PWM出力ピンのスルーレート(GPIO速度)。低いほどエッジが鈍り高調波が減る。
 *   2 / 10 / 30 のいずれか。大電流LEDは 2 推奨(ただし極端に低いと立上りが甘くなる)。
 * PWM_SPREAD_SPECTRUM: 1 で周期を微小ディザしてスペクトラム拡散(基本波のピークを分散)。
 *   duty比は保つので明るさは不変。PWM_SPREAD_RANGE は ATRLR の振り幅(±カウント)。
 *   PWM_SPREAD_PERIOD_MS 間隔で更新。 */
#define PWM_SLEW_MHZ         2
#define PWM_SPREAD_SPECTRUM  0
#define PWM_SPREAD_RANGE     192u    /* ±この分 ATRLR を振る(≈±%スパンで周波数拡散) */
#define PWM_SPREAD_PERIOD_MS 2u      /* ディザ更新間隔 */

/* ===================== 調光段数 ===================== */
#define LEVELS       64u     /* 0(消灯) .. LEVELS(最大) の段数 */
#define LEVEL_INIT   32u     /* 起動時レベル */

/* ===================== 調光カーブ (CIE 1931 L*: 人間の知覚を最優先で再現) =====
 * 目的: 「1クリック=知覚的に等量の明るさ変化」。人間の明るさ知覚(明度)は輝度に対し
 *       べき乗則(≒立方根)で、暗部は緩やか・明部は急峻。これを標準化したのが CIE L*。
 *   段 i を明度 L*(0..100) に等間隔で割り当て、L* → 相対輝度 Y → duty へ逆算:
 *       L* <= 8 : Y = L* / 903.3                (真っ暗付近の直線トウ)
 *       L* >  8 : Y = ((L* + 16) / 116)^3       (べき乗則)
 *       duty = PWM_TOP * Y
 *   → 暗い時はゆっくり、明るい時は急激に、が"目にとって均等な"配分で実現。
 *   純 log/指数テーパより実際の知覚(特に暗部)に忠実。曲線は固定(パラメータ不要)。
 * ※整数演算のみ(立方は起動時に uint64 で計算)。libm/float 不使用。
 *   実行中は uint16 テーブル参照のみ。 */
/* (この節に調整パラメータは無い ─ CIE L* は知覚均等になるよう定義された曲線そのもの) */

/* ===================== エンコーダ (CW/CCW 2タイプ対応) =====================
 * 品種・配線で回転方向が逆になる。ENC_REVERSE で入れ替え可 (半田付けし直し不要)。
 *   0: 時計回り(CW)で明るく / 反時計回り(CCW)で暗く
 *   1: 反時計回り(CCW)で明るく / 時計回り(CW)で暗く
 * ENC_HALF_STEP: ディテントの数え方。
 *   0: フルステップ = 1クリック(4遷移)で1段 … 一般的なディテント付きエンコーダ
 *   1: ハーフステップ = 半クリック(2遷移)で1段 … 1周に倍のディテントを持つ品/半段品 */
#define ENC_REVERSE     0
#define ENC_HALF_STEP   0

/* エンコーダ加速: 同方向を速く回すと 1クリックのステップを ×ENC_ACCEL_FACTOR 段に。
 * 前クリックから ENC_ACCEL_WINDOW_MS 未満なら加速。0 相当にしたい場合は ENABLE=0。
 * (さらに速い"勢い回し"は SNAP で 100%/0% になる。加速はその手前の中速域。) */
#define ENC_ACCEL_ENABLE    1
#define ENC_ACCEL_FACTOR    3       /* 速回し時の1クリックのステップ倍率(=現在の3倍) */
#define ENC_ACCEL_WINDOW_MS 50u     /* 前クリックからこの時間未満なら加速 */

/* ===================== チャタリング(バウンス)吸収 =====================
 * 単純 delay ではなく「状態機械 + 時間ロックアウト」で構造的に吸収する。
 *   (1) フルステップ状態機械(Ben Buxton方式): ディテント間の正しい遷移経路を
 *       完走したときだけ 1 ステップ発火。途中のバウンスは中間状態と静止位置を
 *       往復するだけで発火しない → 単相バウンスを構造的に無視。
 *   (2) 方向反転ロックアウト: 直前ステップと"逆方向"のステップが ENC_REVERSAL_LOCK_MS
 *       以内に来たら、物理的にあり得ない=バウンスとして破棄。
 *       (人が実際にディテントを逆回しするには数十 ms 以上かかる。5ms は安全に短い。)
 *       同方向は制限しない → 高速回転(スナップ)を妨げない。
 * ※詳細と代替案(定周期サンプリング等)の検討は documents/DESIGN.md 参照。 */
#define ENC_REVERSAL_LOCK_MS  5u    /* この時間以内の"逆方向"ステップはバウンス扱いで無視 */

/* ===================== 高速回しスナップ =====================
 * SNAP_WINDOW_MS(=n ms) 以内に同方向へ SNAP_CLICKS(=j回) 以上のクリックが
 * 起きたら、明るい方向なら duty=100%(全開)、暗い方向なら duty=0%(消灯) に即セット。
 *   「勢いよく回す」= 一気に最大/最小、のショートカット。 */
#define SNAP_WINDOW_MS   500u    /* n ms (0.5秒) */
#define SNAP_CLICKS      6u      /* j 回 (2以上) */

/* ===================== 押しSW デバウンス (時間ベース積分) =====================
 * ループ回数依存の粗いカウンタではなく、SysTick 実時間で「安定してこの時間 Low を
 * 維持したら押下確定」。放し側も同様に安定を要求してチャタを吸収する。 */
#define SW_DEBOUNCE_MS   20u

/* ===================== 動作オプション =====================
 * WAKE_ON_TURN: 消灯(OFF)中にエンコーダを回したら自動で点灯(ON)に復帰する。
 *   ただし"明るさが出る"操作(結果 level>0)のときだけ点灯する。level=0 のまま暗方向へ
 *   回した場合は消灯のまま(g_on を立てない)＝「回したのに点かず on だけ立つ」不整合を防ぐ。
 *   0 にすると OFF 中の回転は隠れた level のみ変え、点灯は押しSW でのみ行う。
 * DEBUG_LOG: 1 で SWD(WCH-LinkE) 経由の printf ログを出す(開発時のみ)。
 *   ★通常運用は 0 を厳守。printf はブロッキングで、ホスト未接続だとバッファ満杯で
 *     処理が停滞し、高速回転時のエンコーダ遷移取りこぼし/スナップ不発を招く。 */
#define WAKE_ON_TURN     1
#define DEBUG_LOG        0
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

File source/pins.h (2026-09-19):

/*
 * pins.h — 機能↔ピン割当の能力モデル・導出・コンパイル時検証 (CH32V003 SOP8 / J4M6)
 *
 *  config.h の「1機能=1ピンマクロ」から、各機能に必要な低レベル情報
 *  (GPIOポート/ピン番号 / ADCチャネル / PWMのタイマ・チャネル・remap) を導出し、
 *  ハード能力違反(PWM/ADC不可ピン)とピン衝突(2機能が同一ピン)をコンパイル時に弾く。
 *
 *  ── SOP8 (J4M6) の実在ピンと能力 ──  (出典: CH32V003 データシート / ch32fun ch32v003hw.h)
 *   pin   GPIO      ADCch   PWM経路(正出力)            既定用途
 *   PA1   GPIOA/1   1       TIM1_CH2 (no remap)        ENC_A
 *   PA2   GPIOA/2   0       (CH2N=相補のみ→PWM非対応)   ENC_SW
 *   PC1   GPIOC/1   -       TIM2_CH4 (remap1)          ENC_B
 *   PC2   GPIOC/2   -       TIM2_CH2 (remap1) ★既定PWM
 *   PC4   GPIOC/4   2       TIM1_CH4 (no remap)        常夜灯/温度/警告灯
 *   PD1   GPIOD/1   -       (CH3N=相補のみ) ※SWIO=書込/printf 予約
 *
 *  ※既定構成(PWM=PC2)は従来と同一のレジスタ操作を生成する(挙動不変)。
 *    PC2 以外の PWM ピンは「コンパイル対応・実機未検証」。
 */
#ifndef PINS_H
#define PINS_H

#include "ch32fun.h"   /* ピンマクロ(PA1=1,PC2=34,…) / GpioOf / TIM/RCC/AFIO 定義 */
#include "config.h"    /* 機能↔ピンの割当・有効フラグ */

/* ch32fun のピンマクロは整数値: 汎用の導出はビット演算で行える。
 *   GPIOポート = GpioOf(pin)  (= GPIOA_BASE + 0x400*(pin>>4))
 *   ピン番号   = (pin & 0x7)   (SOP8 は全て 0..7) */
#define LB_GPIO_OF(pin)   GpioOf(pin)
#define LB_PINNUM_OF(pin) ((pin) & 0x7)

/* SOP8 実在ピンか (それ以外は物理的に存在しない) */
#define LB_PIN_IS_SOP8(p) \
    ((p)==PA1 || (p)==PA2 || (p)==PC1 || (p)==PC2 || (p)==PC4 || (p)==PD1)

/* =========================================================================
 *  PWM 出力ピン → タイマ / チャネル / remap の導出
 *  正出力(単出力)チャネルのみ対応。相補(PA2=CH2N/PD1=CH3N)は既定除外。
 * ========================================================================= */
#if   PWM_PIN == PC2
  #define PWM_USES_TIM1    0
  #define PWM_CH           2
  #define PWM_REMAP_CLEAR  AFIO_PCFR1_TIM2_REMAP
  #define PWM_REMAP_SET    AFIO_PCFR1_TIM2_REMAP_PARTIALREMAP1
  #define PWM_RCC_GPIO_BIT RCC_APB2Periph_GPIOC
#elif PWM_PIN == PC1
  #define PWM_USES_TIM1    0
  #define PWM_CH           4
  #define PWM_REMAP_CLEAR  AFIO_PCFR1_TIM2_REMAP
  #define PWM_REMAP_SET    AFIO_PCFR1_TIM2_REMAP_PARTIALREMAP1
  #define PWM_RCC_GPIO_BIT RCC_APB2Periph_GPIOC
#elif PWM_PIN == PA1
  #define PWM_USES_TIM1    1
  #define PWM_CH           2
  #define PWM_REMAP_CLEAR  AFIO_PCFR1_TIM1_REMAP
  #define PWM_REMAP_SET    AFIO_PCFR1_TIM1_REMAP_NOREMAP
  #define PWM_RCC_GPIO_BIT RCC_APB2Periph_GPIOA
#elif PWM_PIN == PC4
  #define PWM_USES_TIM1    1
  #define PWM_CH           4
  #define PWM_REMAP_CLEAR  AFIO_PCFR1_TIM1_REMAP
  #define PWM_REMAP_SET    AFIO_PCFR1_TIM1_REMAP_NOREMAP
  #define PWM_RCC_GPIO_BIT RCC_APB2Periph_GPIOC
#else
  #error "PWM_PIN は PWM 可能な SOP8 ピンにしてください: PC2(TIM2_CH2)/PC1(TIM2_CH4)/PA1(TIM1_CH2)/PC4(TIM1_CH4)"
#endif

#if PWM_USES_TIM1
  #define PWM_TIMREG TIM1
#else
  #define PWM_TIMREG TIM2
#endif

#define PWM_GPIO_PORT  LB_GPIO_OF(PWM_PIN)
#define PWM_PINNUM     LB_PINNUM_OF(PWM_PIN)

/* チャネル番号(1..4)からレジスタ/ビットを合成する2段展開マクロ */
#define LB_CVR_(t,c)   ((t)->CH##c##CVR)
#define LB_CVR(t,c)    LB_CVR_(t,c)
#define PWM_CVR        LB_CVR(PWM_TIMREG, PWM_CH)                 /* 比較値レジスタ */

#define LB_OCM_(c)     (TIM_OC##c##M_2 | TIM_OC##c##M_1 | TIM_OC##c##PE) /* PWM mode1 + preload */
#define LB_OCM(c)      LB_OCM_(c)
#define PWM_OCM        LB_OCM(PWM_CH)

#define LB_CCE_(c)     (TIM_CC##c##E)                            /* 出力有効 */
#define LB_CCE(c)      LB_CCE_(c)
#define PWM_CCE        LB_CCE(PWM_CH)

/* CH1/CH2 は CHCTLR1、CH3/CH4 は CHCTLR2 に OCxM を書く */
#if PWM_CH <= 2
  #define PWM_CHCTLR   PWM_TIMREG->CHCTLR1
#else
  #define PWM_CHCTLR   PWM_TIMREG->CHCTLR2
#endif

/* =========================================================================
 *  外付け温度センサ(ADC) ピン → ADCチャネルの導出 (external 使用時のみ)
 * ========================================================================= */
#if TEMP_PROTECT_ENABLE && (TEMP_SOURCE == TEMP_SOURCE_EXTERNAL)
  #if   TEMP_SENSE_PIN == PA2
    #define TEMP_ADC_CH 0
  #elif TEMP_SENSE_PIN == PA1
    #define TEMP_ADC_CH 1
  #elif TEMP_SENSE_PIN == PC4
    #define TEMP_ADC_CH 2
  #else
    #error "TEMP_SENSE_PIN は ADC 対応の SOP8 ピンにしてください: PA2(ch0)/PA1(ch1)/PC4(ch2)"
  #endif
#endif

/* =========================================================================
 *  常夜灯 WS2812 データピン → GPIOポート/ピン番号の導出
 * ========================================================================= */
#define WS_GPIO_PORT   LB_GPIO_OF(WS_DIN_PIN)
#define WS_GPIO_PINNUM LB_PINNUM_OF(WS_DIN_PIN)
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

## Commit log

2026-09-18 Revise README with project details and specifications
    Updated README to include detailed project information, features, and specifications for the CH32V003 LED Dimmer Controller.
2026-09-18 docs: 全ドキュメントの整合・相互リンク整理（EN⇔JP・成果物リンク・パス修正）
    - 全18 md にEN⇔JP言語切替ナビを追加し、日本語文書のリンク先を _JP 版へ統一
    - documents 各文書にREADMEへの戻りリンクを追加（DESIGN/HARDWARE 含む）
    - トップREADMEに LightBox Studio(GUIツール) の節とリンクを追加、
    ディレクトリ図に tools/・ldscript/ を追記
    - ディレクトリ表記の不整合を修正: 3D/ → 3D_Models/、EN READMEの ArtWork.png → AertWork.png
    - HARDWARE.md/_JP の絶対パス(D:\hobby\LightBox\...)をリポジトリ相対に変更
    - LightBox Studio README のJAR本数を 4→5 に訂正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
2026-09-19 feat: config.h 主導の「機能↔ピン割当」を本格実装 (+GUI/検証/docs)
    firmware:
    - 新規 source/pins.h: 機能↔ピンの能力モデルと導出、コンパイル時検証。
    * PWM_PIN/TEMP_SENSE_PIN の能力チェック(#error)、全機能横断のピン衝突検出
    (_Static_assert: 使用ピンの加算==論理和)、SWIO(PD1) 使用の #warning。
    * ピン能力/remap は ch32fun ch32v003hw.h に照合(TIM1/TIM2 remap, ADCch)。
    - config.h を「1機能=1ピンマクロ」に統一: PWM_PIN 新設、WS_PORT/WS_PINNUM→WS_DIN_PIN、
    TEMP_SENSE_ANALOG 廃止(TEMP_SENSE_PIN から自動導出)。既定値は不変。
    - lightbox.c: tim2_pwm_init→汎用 pwm_init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
    [ConfigSchema.java, ConfigSchemaCheck.java, config.h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]
2026-09-19 feat: 自動消灯タイマ PWM_ON_TIME_S を追加 + バッテリ駆動の補足ドキュメント
    - config.h: PWM_ON_TIME_S(秒, 0=無効) を新設。点灯からこの秒数で本体出力を
    自動消灯(ソフトオフ)。既定 0 で従来どおり(挙動不変)。
    - lightbox.c: 自動消灯タイマを実装。
    * 1秒刻みでカウント(SysTick 32bit@48MHz ~89秒ラップに非依存)。
    * エンコーダ回転/押しSW ON などの操作でカウントをリセット(=延長)。
    * 到達で g_on=0 → SOFT_START_OFF でソフトオフ → 常夜灯有効なら常夜灯へ移行。
    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
2026-09-19 feat: 深い低電力(Standby+AWU)常夜灯 + 常夜灯タイプ(WS2812/単色LED) + GUI電池目安
    概要: バッテリ駆動向けの深い低電力常夜灯を追加。常夜灯を①WS2812(演出優先)/②単色LED
    (n秒おき・x ms・PWM有無)から選べるようにし、GUIにCR2032寿命目安(1kΩ前提)をライブ表示。
    全新規挙動は既定OFF/既定WS2812にゲートし、既定ビルドは従来と挙動不変。
    - config.h: NIGHTLIGHT_TYPE(WS2812/SINGLE), 単色LED(NL_LED_PIN/NL_PERIOD_S/NL_ON_MS/NL_USE_PWM),
    深い低電力(LOW_POWER_MODE/LOWPWR_ACTIVE_WINDOW_S) を追加。既定は従来値。
    - 新規 nl_single.h: 単色LED常夜灯(非スリープ)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
2026-09-20 docs: 設計議論を記録(POWER_AND_DRIVER EN/JP) + jarモジュール群を最新ソースで再ビルド
    - 新規 documents/POWER_AND_DRIVER.md(+_JP): これまでの設計議論を記録。
    機能↔ピン割当の動機(PCB簡素化)、自動消灯タイマ、常夜灯タイプ(WS2812/単色LED)、
    深い低電力(Standby+AWU: 起水モデル/リーク対策/再書込みセーフティ/リセット耐性/AWU≤30s/WDT必須0)、
    電池寿命見積り(CR2032 1kΩ, 直列は容量非増/6VはVDD上限超, 並列/大容量セル)、
    本体LEDドライバ選定(CN5711リニアCC: CE PWM<2kHz/温度フォールドバック、5V→白色でのリニア損失表と
    ~1Aフォール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
2026-09-20 fix(studio): 設定エディタでピン割当が編集不可だった問題を修正
    症状: LightBoxMenu.jar → 設定エディタで肝心のピンが割り当てられない。原因2つを ConfigEditor.java で修正:
    - ピンが「上級者モード」でロックされていた(PWM_PIN/ENC_*_PIN が .advanced()=既定で無効)。
    ピン割当は本ツールの主機能なのでトグルを既定ONに変更(ラベルも「オフでロック」に)。
    - 読み込み時の値クロバー: 電池目安のライブ再計算リスナが loadWidgets() 中に発火し、
    applyWidgets() が未ロード既定値で config を上書き→ピン等が誤ってロードされた。
    loading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
2026-09-20 feat(studio): 設定エディタの「ピン割当」に全ピン機能を集約(常夜灯ピンも)
    - ConfigSchema: 「ピン割当」セクションの末尾に常夜灯ピン(①WS2812=WS_DIN_PIN /
    ②単色LED=NL_LED_PIN)を移動し、全ピン機能を1セクションに集約。
    「常夜灯」セクションには点灯周期/点灯時間/PWM有無/LED個数 等の機能パラメータのみ残す。
    セクション名を「ピン割当 (全ピン機能を集約)」に更新。ピンは advanced 指定=固定ロックのトグル対象。
    - 重複キー無し・全64項目が config.h に存在・自己テスト ALL PASS を確認。dist/*.jar 再ビルド。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
2026-09-20 chore(studio): 温度保護セクションのラベルを「温度保護機能（実験的・既定OFF）」に変更
    依頼どおり「温度保護→温度保護機能（実験的）」を反映(既定OFFの情報は残す)。dist/*.jar 再ビルド。
    Claude-Session: https://claude.ai/code/session_01QUXowbh1Y3TD7TayBGyNWJ
2026-09-20 feat(studio): 設定エディタのピン割当をピン中心UI(PinMapPanel)へ刷新
    SVG準拠。SOP8の各割当可能ピン(PA1/PA2/PC1/PC2/PC4)に機能を選ぶ方式に
    変更し、1ピン=1機能を構造的に保証(従来の機能→ピンの取り合い衝突を排除)。
    - 新規 PinMapPanel: ピン中心の割当パネル。VSS/VDD/SWIO(PD1)は固定表示。
    上部チェック「ピン割り当て機能を利用する(上級者向き)」(既定☑)で編集可否を
    切替、「デフォルト」で実機検証済み既定割当へ一括復帰。常夜灯は
    WS_DIN_PIN/NL_LED_PIN の両方へ書込。PWM/ADC能力で選択肢を自動フィルタ。
    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
